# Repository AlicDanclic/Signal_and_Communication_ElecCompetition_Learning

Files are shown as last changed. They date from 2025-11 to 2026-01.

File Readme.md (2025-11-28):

<div align=center><h1>信号电赛备战</h1></div>

### 待完成项目

- [ ] 无线运动传感器节点设计
- [ ] 信号失真度测量装置
- [ ] 无线环境监测模拟装置
- [ ] 微弱信号检测装置
- [ ] 频率补偿电路
- [ ] 调幅信号处理实验电路
- [ ] 无线话筒扩音系统
- [ ] 数字频率计
- [ ] 红外光通信装置
- [ ] 锁定放大器
- [ ] 增益可控射频放大器
- [ ] ∑-Δ 型 ADC 转换电路设计
- [ ] 自适应滤波器
- [ ] 数字-模拟信号混合传输收发机
- [ ] 信号调制方式识别与参数估计装置

### 已有模块

#### 基于TPS7A4701RGWR的低噪声射频LDO

> 包含5V默认输出,3V3默认输出,1V8默认输出,拨码开关可调输出

整个系统通过MP2236进行初步降压,由于MP2236最大输出为6A,考虑1.5倍余量来说,负载端的最大输出应该使用4A左右,正好可以搭配4个TPS7A4701.

### 已有代码

| 代码名/地址 | 完成时间 | 功能介绍 |
| --- | --- | --- |
| | | |
| | | |
| | | |

<div align=center><h3>FPGA知识</h3></div>

<div align=center><h3>信号PCB设计知识</h3></div>

<div align=center><h3>信号处理</h3></div>

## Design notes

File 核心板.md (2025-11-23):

### Component
- FPGA  
XC7A50T-FGG484
- SDRAM  
M12L64322A 8MB SDRAM (512K x 32 Bit x 4 Banks)
- SPI Flash  
MX25L128 16MB
- Ethernet PHY  
1Gb Ethernet PHY Broadcom B50612D x 2

### JTAG
| Pin | Function |
|-----|---|
| J5  | TCK |
| J4  | TMS |
| J3  | TDI |
| J2  | TDO |

### Clock
A 25Mhz clock is connected to FPGA with pin K4

### LED
| LED | FPGA Pin |
|-----|---|
| D2  | A18 |

### SPI-FLASH (U12)
| U12 Pin | FPGA Pin |
|-----|---|
| CS  | T19 |
| MISO| R22 |
| MOSI| P22 |
| SCK | L12 |

### DDR2-SODIMM-200P
| Function | Top-Pin | Bot-Pin | Function |
|---|---|---|---|
| GND | 1 | 2 | 5V |
| GND | 3 | 4 | 5V |
| GND | 5 | 6 | 5V |
| GND | 7 | 8 | 5V |
| GND | 9 | 10 | 5V |
| GND | 11 | 12 | 5V |
| NC | 13 | 14 | NC |
| ETH1_1P| 15 | 16 | ETH2_1P|
| ETH1_1N| 17 | 18 | ETH2_1N|
| NC | 19 | 20 | NC |
| ETH1_2N| 21 | 22 | ETH2_2N|
| ETH1_2P| 23 | 24 | ETH2_2P|
| NC | 25 | 26 | NC |
| ETH1_3P| 27 | 28 | ETH2_3P|
| ETH1_3N| 29 | 30 | ETH2_3N|
| NC | 31 | 32 | NC |
| ETH1_4N| 33 | 34 | ETH2_4N|
| ETH1_4P| 35 | 36 | ETH2_4P|
| NC | 37 | 38 | NC |
| GND | 39 | 40 | GND |
| | | | |
| | | | |
| R2 | 41 | 42 | P5 |
| NC | 43 | 44 | T6 |
| NC | 45 | 46 | U7 |
| NC | 47 | 48 | U6 |
| T3 | 49 | 50 | U5 |
| T4 | 51 | 52 | V5 |
| NC | 53 | 54 | U1 |
| GND | 55 | 56 | GND |
| U2 | 57 | 58 | H3 |
| U3 | 59 | 60 | J1 |
| V2 | 61 | 62 | K1 |
| V3 | 63 | 64 | L1 |
| W1 | 65 | 66 | M1 |
| Y1 | 67 | 68 | J2 |
| AA1 | 69 | 70 | K2 |
| AB1 | 71 | 72 | K3 |
| W2 | 73 | 74 | G3 |
| Y2 | 75 | 76 | J4 |
| AB2 | 77 | 78 | G4 |
| AA3 | 79 | 80 | F4 |
| AB3 | 81 | 82 | L4 |
| Y3 | 83 | 84 | R3 |
| W4 | 85 | 86 | M3 |
| AA4 | 87 | 88 | V4 |
| Y4 | 89 | 90 | R4 |
| AB5 | 91 | 92 | T5 |
| AA5 | 93 | 94 | J5 |
| Y6 | 95 | 96 | J6 |
| AB6 | 97 | 98 | W5 |
| AA6 | 99 | 100  | L5 |
| Y7 | 101  | 102  | L6 |
| AB7 | 103  | 104  | W6 |
| GND | 105  | 106  | GND |
| GND | 107  | 108  | GND |
| AA8 | 109  | 110  | V7 |
| AB8 | 111  | 112  | N13 |
| Y8 | 113  | 114  | N14 |
| W7 | 115  | 116  | P15 |
| Y9 | 117  | 118  | P16 |
| V8 | 119  | 120  | R16 |
| W9 | 121  | 122  | N17 |
| V9 | 123  | 124  | V17 |
| R14 | 125  | 126  | P17 |
| P14 | 127  | 128  | U17 |
| W17 | 129  | 130  | T18 |
| Y18 | 131  | 132  | R17 |
| AA18 | 133  | 134  | U18 |
| W19 | 135  | 136  | R18 |
| AB18 | 137  | 138  | N18 |
| Y19 | 139  | 140  | R19 |
| AA19 | 141  | 142  | N19 |
| V18 | 143  | 144  | N15 |
| V19 | 145  | 146  | M16 |
| AB20 | 147  | 148  | M15 |
| AA20 | 149  | 150  | L15 |
| AA21 | 151  | 152  | L16 |
| AB21 | 153  | 154  | K14 |
| Y21 | 155  | 156  | N22 |
| GND | 157  | 158  | GND |
| NC | 159  | 160  | NC |
| NC | 161  | 162  | NC |
| NC | 163  | 164  | NC |
| NC | 165  | 166  | NC |
| NC | 167  | 168  | NC |
| NC | 169  | 170  | NC |
| NC | 171  | 172  | NC |
| NC | 173  | 174  | NC |
| NC | 175  | 176  | NC |
| NC | 177  | 178  | NC |
| NC | 179  | 180  | NC |
| NC | 181  | 182  | NC |
| NC | 183  | 184  | NC |
| NC | 185  | 186  | NC |
| NC | 187  | 188  | NC |
| NC | 189  | 190  | NC |
| NC | 191  | 192  | NC |
| NC | 193  | 194  | NC |
| NC | 195  | 196  | NC |
| NC | 197  | 198  | NC |
| GND | 199  | 200  | GND |

### SDRAM (U6)
| U6 Pin | FPGA Pin |
|-----|---|
| CLK | E14 |
| CKE | VCC |
| CS  | GND |
| RAS | A14 |
| CAS | D14 |
| WE  | D17 |
| DQM0| GND |
| DQM1| GND |
| DQM2| GND |
| DQM3| GND |
| BA0 | D19 |
| BA1 | B13 |
| A0  | C20 |
| A1  | C19 |
| A2  | C13 |
| A3  | F13 |
| A4  | G13 |
| A5  | G15 |
| A6  | F14 |
| A7  | F18 |
| A8  | E13 |
| A9  | E18 |
| A10 | C14 |
| DQ0 | F21 |
| DQ1 | E22 |
| DQ2 | F20 |
| DQ3 | E21 |
| DQ4 | F19 |
| DQ5 | D22 |
| DQ6 | E19 |
| DQ7 | D21 |
| DQ8 | K21 |
| DQ9 | L21 |
| DQ10| K22 |
| DQ11| M21 |
| DQ12| L20 |
| DQ13| M22 |
| DQ14| N20 |
| DQ15| M20 |
| DQ16| B18 |
| DQ17| D20 |
| DQ18| A19 |
| DQ19| A21 |
| DQ20| A20 |
| DQ21| B21 |
| DQ22| C22 |
| DQ23| B22 |
| DQ24| G21 |
| DQ25| G22 |
| DQ26| H20 |
| DQ27| H22 |
| DQ28| J20 |
| DQ29| J22 |
| DQ30| G20 |
| DQ31| J21 |

### ETH-PHY0 (U5)
| U5 Pin | FPGA Pin |
|---|---|
| MDC | G1 |
| MDIO  | G2 |
| RESET | H2 |
| GTXCLK| A1 |
| TXD[0]| B2 |
| TXD[1]| B1 |
| TXD[2]| C2 |
| TXD[3]| D2 |
| TX_EN | D1 |
| RXC | H2/H4 |
| RXD[0]| E3 |
| RXD[1]| E2 |
| RXD[2]| E1 |
| RXD[3]| F3 |
| RX_DV | F1 |

### ETH-PHY1 (U9)
| U9 Pin | FPGA Pin |
|---|---|
| MDC | G1 |
| MDIO  | G2 |
| RESET | H2 |
| GTXCLK| M6 |
| TXD[0]| M5 |
| TXD[1]| M2 |
| TXD[2]| N4 |
| TXD[3]| P4 |
| TX_EN | N5 |
| RXC | L3/H2 |
| RXD[0]| N2 |
| RXD[1]| N3 |
| RXD[2]| P1 |
| RXD[3]| P2 |
| RX_DV | R1 |

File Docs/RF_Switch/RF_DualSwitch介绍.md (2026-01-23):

<div align="center"><h1>RF_DualSwitch</h1></div>

**SKY13453-385LF**是一款0.01至6.0 GHz单控制SPDT射频开关芯片，专为蜂窝和WLAN系统中的信号路径切换设计。其特点包括采用先进半导体工艺，在2.0 GHz下实现低至0.40 dB的插入损耗和高于25 dB的隔离度。该器件通过单一控制引脚（VCTL）即可实现RFC端口与RF1或RF2之间的高线性切换，并集成在超小尺寸的6引脚QFN（1×1 mm）封装内，满足现代紧凑型射频前端模组的需求。主要应用于手机预功率放大器（PA）模式切换s及双频WLAN（802.11a/b/g/n）等场景。

### 硬件设计

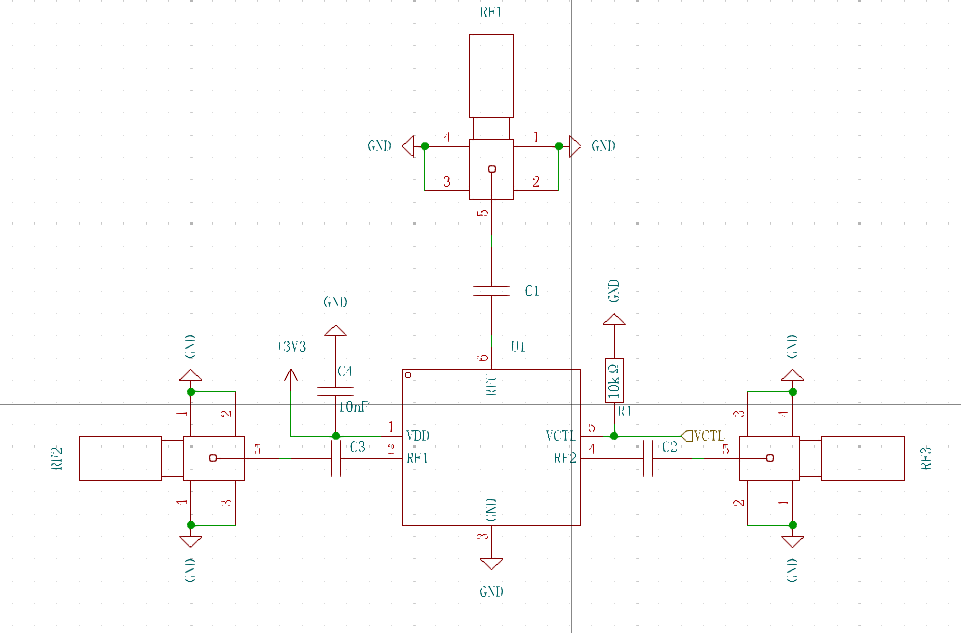
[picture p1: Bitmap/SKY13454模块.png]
RF_DualSwitch模块
 <div align="center">图1 RF_DualSwitch 模块示意图</div>

SKY13453-385LF 的设计重点在于确保射频性能与控制稳定性：**控制端 VCTL** 必须严格遵循逻辑真值表，高电平范围为 +1.8V 至 +3.0V，低电平为 0V 至 +0.45V；**所有射频端口（RFC、RF1、RF2）必须串联 DC 阻隔电容**（建议 10 nF 用于低频应用）；**PCB 布局**应确保射频走线短直、阻抗控制在 50Ω，并**将芯片底部接地焊盘通过多个过孔充分连接至系统地平面**，以优化散热与电气性能；**工作温度范围**为 -40°C 至 +90°C，且在整个生产与操作过程中**必须实施严格的 ESD 防护措施**。建议使用官方评估板进行前期验证，并确保输入功率不超过 +33 dBm。

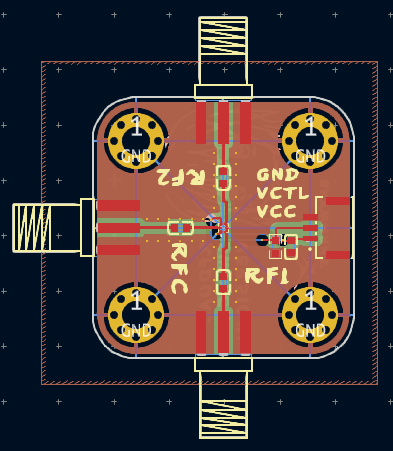
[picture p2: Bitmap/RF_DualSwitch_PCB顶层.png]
RF_DualSwitch_PCB顶层
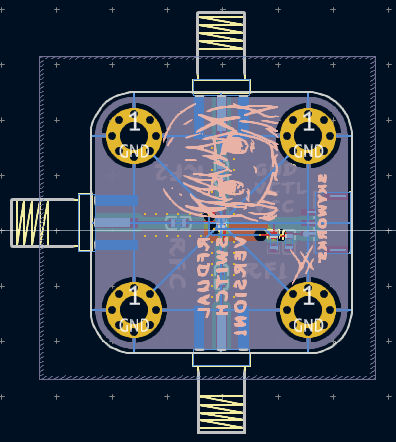
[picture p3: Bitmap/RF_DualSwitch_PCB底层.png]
RF_DualSwitch_PCB底层
 <div align="center">图2 RF_DualSwitch PCB 设计示例</div>

<div style="background-color: #f8f9fa; padding: 30px; text-align: center; margin-top: 20px; border-radius: 8px;">
    <div style="color: #666; margin-bottom: 15px;">PCB尺寸示意图</div>
    <div style="display: inline-block; background-color: #e8f0fe; padding: 90px 60px; border: 2px solid #2c5aa0; border-radius: 4px;">
      <div style="color: #2c5aa0; font-weight: bold; font-size: 24px;">30 × 30 mm</div>
    </div>
    <div style="color: #666; margin-top: 15px;">边长：30 mm</div>
    <div style="color: #888; font-size: 12px; margin-top: 5px;">正方形 PCB</div>
  </div>

  <div style="display: flex; flex-wrap: wrap; gap: 20px; margin-top: 20px;">
    <div style="flex: 1; min-width: 200px;">
      <div style="color: #666; margin-bottom: 5px;">安装孔半径</div>
      <div style="font-size: 18px; font-weight: bold; color: #333;">3mm</div>
    </div>
    <div style="flex: 1; min-width: 200px;">
      <div style="color: #666; margin-bottom: 5px;">安装孔数量</div>
      <div style="font-size: 18px; font-weight: bold; color: #333;">4</div>
    </div>
    <div style="flex: 1; min-width: 200px;">
      <div style="color: #666; margin-bottom: 5px;">板厚</div>
      <div style="font-size: 18px; font-weight: bold; color: #333;">1.6 mm</div>
    </div>
    <div style="flex: 1; min-width: 200px;">
      <div style="color: #666; margin-bottom: 5px;">安装孔位置</div>
      <div style="font-size: 18px; font-weight: bold; color: #333;">四角对称</div>
    </div>
</div>

### 使用注意

- **控制逻辑与电压**：控制引脚 VCTL 必须严格遵循逻辑真值表，高电平为 +1.8V 至 +3.0V，低电平为 0V 至 +0.45V，未定义的逻辑状态会导致开关进入不确定状态
- **射频端口 DC 隔离电容**：所有射频端口（RFC、RF1、RF2）必须串联隔直电容，建议使用 10 nF 电容用于低频应用（＜100 MHz），并应选用 NPO/C0G 材质，尽量靠近芯片引脚布局
- **散热与功率**：射频输入功率绝对不得超过 +33 dBm，芯片底部裸露焊盘必须通过多个过孔大面积连接到 PCB 接地层，以确保散热和电气性能稳定

### 附录: 电容选择建议

| 射频端口 | 频率范围 | 推荐电容值 (C_BL) | 关键设计说明 |
| :--- | :--- | :--- | :--- |
| **所有RF端口** (RFC, RF1, RF2) | **< 100 MHz** (低频应用) | **≥ 10 nF** | **数据手册推荐值**。应选用 **NPO/C0G** 材质多层陶瓷电容（MLCC），以提供充分的DC隔离。 |
| | **≥ 100 MHz** (中高频应用) | **100 pF** | **典型建议值**。为获得更宽频带性能，可根据具体应用调整容值（如47 pF至220 pF）。电容的ESR和自谐振频率需满足应用要求。 |
| **控制电压 VCTL** | **全频率范围** | **10 nF** | **推荐使用**。用于控制引脚的去耦与滤波，确保控制信号稳定，应靠近引脚布局。 |

> **注**：对于高频应用（如 2.4/5.8 GHz WLAN），建议参考官方评估板设计或使用网络分析仪进行实际调测，以优化电容选择。

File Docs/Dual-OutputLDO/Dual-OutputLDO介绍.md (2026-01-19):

<div align="center"><h1>Dual-OutputLDO</h1></div>

LM27762 是一款低噪声正负输出集成式电荷泵与 LDO 芯片，能够从单路输入（2.7V‑5.5V）同时生成可调节的正电压（1.5V‑5V）和负电压（‑1.5V‑‑5V），输出电流可达 ±250mA。其特点包括采用反相电荷泵后接负 LDO 的结构，开关频率为 2MHz，输出噪声极低（典型值 22μVrms），并具有独立的使能控制和电源正常（PGOOD）指示功能。重要参数包括静态电流仅 390μA（典型值）、关断电流 0.5μA，正/负 LDO 在 100mA 负载下的压降分别为 45mV 和 30mV，适用于音频放大器、运放偏置、数据转换器等需要低噪声正负电源的场景。

MP2236 是一款 18V、6A 高效率同步降压转换器，采用恒定导通时间（COT）控制，提供快速瞬态响应和简易的环路补偿。其输入电压范围宽达 3V‑18V，支持最大 6A 连续输出电流，内部集成低导通电阻的功率 MOSFET（25mΩ/12mΩ）。该器件默认参考电压为 600mV，开关频率为 600kHz，并具备打嗝式过流保护（OCP）和热关断功能。重要参数包括轻载时静态电流 150μA（典型值）、关断电流低于 1μA，以及内部软启动时间约 1ms，主要应用于平板电视、数字电视电源、分布式电源系统等中高功率降压转换场合。

### 硬件设计

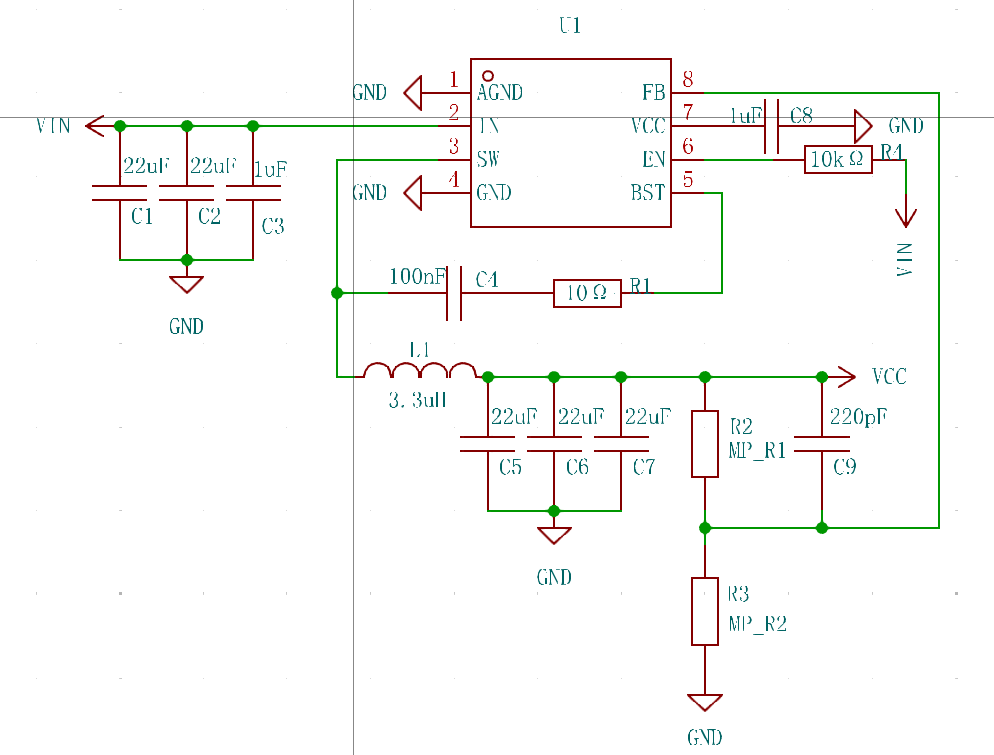
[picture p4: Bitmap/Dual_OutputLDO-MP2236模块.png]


<div align="center">图1 MP2236模块</div>

MP2236是一款同步降压（Step-Down）转换器，其核心任务是将较高的输入电压（如12V）高效、稳定地转换为一个更低的、可精确设定的中间电压（VCC）。这个电压的设定完全由一个连接在输出端与反馈（FB）引脚之间的外部电阻分压网络决定。计算遵循公式 **Vout = 0.6V × (1 + R1/R2)**，其中0.6V是芯片内部的精密基准电压。通过改变R1与R2的阻值比例，即可在0.6V至输入电压的范围内线性调节输出电压。MP2236采用恒定导通时间（COT）控制模式，能根据输入、输出电压实时调整开关频率，在宽输入范围内保持效率与快速瞬态响应。其输出的VCC电压的精度和稳定性，直接决定了后续电路供电平台的质量。

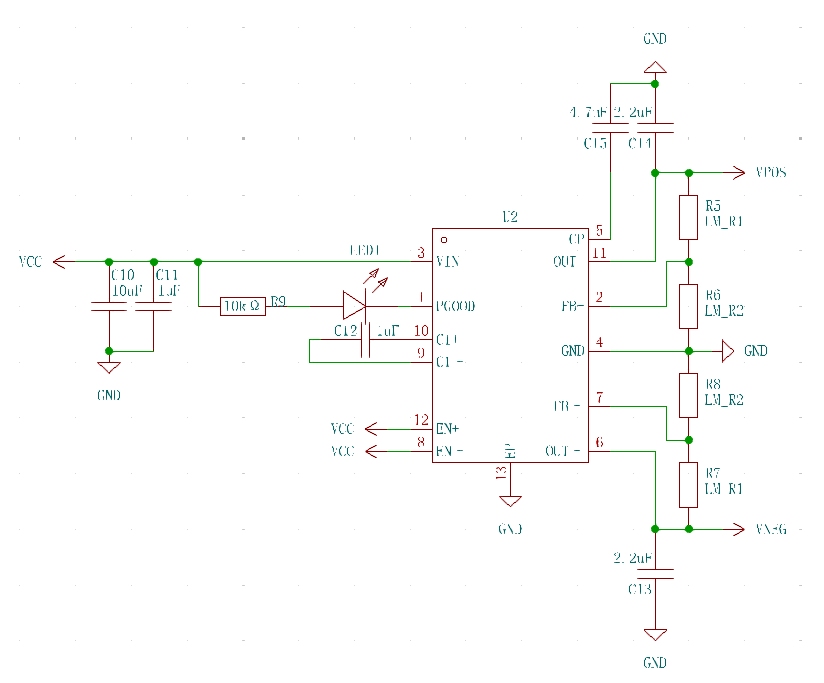
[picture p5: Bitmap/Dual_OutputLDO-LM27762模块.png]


<div align="center">图2 LM27762模块</div>

LM27762则是一个集成了电荷泵和低压差线性稳压器（LDO）的独特芯片，它能从一个单路正输入（即MP2236提供的VCC）同时产生一组相互独立、低噪声的正负输出电压（如+3.3V和-3.3V）。其每路输出都拥有独立的反馈控制环路：正输出由基准电压1.2V和电阻R1、R2设定（公式：**Vout+ = 1.2V × (R1+R2)/R2**），负输出则由基准电压-1.22V和电阻R3、R4设定（公式：**Vout- = -1.22V × (R3+R4)/R4**）。一个关键的设计约束是，为了保障LDO环路的稳定，连接到地的反馈电阻R2和R4必须不小于50kΩ。这种设计允许工程师灵活配置不对称的双电源（如+5V/-3V），但为了获得最佳性能，正负输出的电阻需分别计算以确保精度。

<div style="display: flex; justify-content: space-between; margin: 20px 0;">
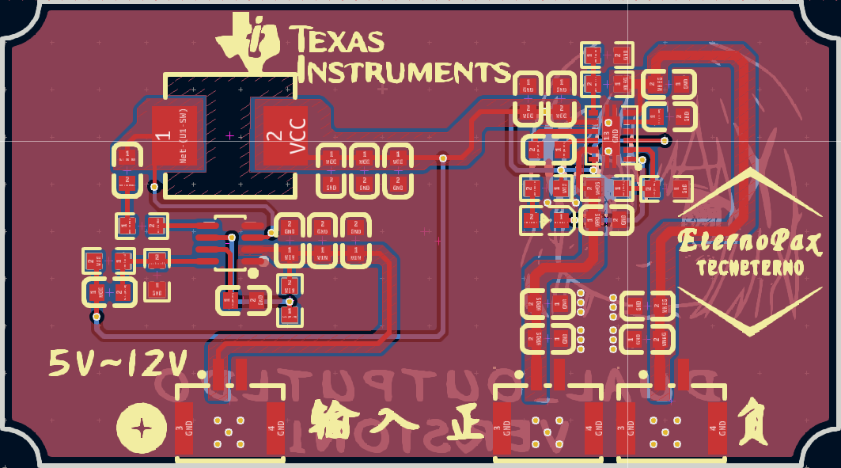
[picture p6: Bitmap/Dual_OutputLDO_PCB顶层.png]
QuietLDO_PCB顶层
  
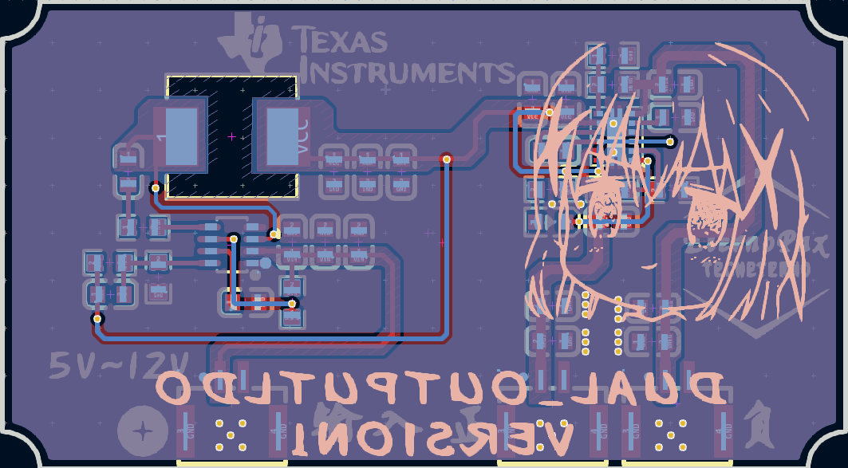
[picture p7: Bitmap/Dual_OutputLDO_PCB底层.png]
QuietLDO_PCBd底层
  
</div>
<div align="center">图3 Dual-OutputLDO PCB设计</div>

<div style="background-color:#f8f9fa;padding:40px;text-align:center;margin-top:30px;border-radius:10px;"><div style="color:#666;margin-bottom:20px;font-size:18px;">PCB尺寸示意图</div><div style="position:relative;display:inline-block;padding:80px 120px;"><div style="width:300px;height:180px;background-color:#e8f0fe;border:3px solid #2c5aa0;clip-path:path('M15,0L285,0L300,15L300,165L285,180L15,180L0,165L0,15L15,0Z M0,15A15,15 0 0 0 15,0L0,15Z M300,15L285,0A15,15 0 0 0 300,15Z M285,180L300,165A15,15 0 0 0 285,180Z M0,165L15,180A15,15 0 0 0 0,165Z')"><div style="color:#2c5aa0;font-weight:bold;font-size:32px;position:absolute;top:50%;left:50%;transform:translate(5%,100%);">25 × 45 mm</div></div></div><div style="color:#666;margin-top:20px;font-size:16px;">长×宽 (单位: mm)，四角2mm半径内凹缺角</div></div>

  <div style="display: flex; flex-wrap: wrap; gap: 20px; margin-top: 20px;">
    <div style="flex: 1; min-width: 200px;">
      <div style="color: #666; margin-bottom: 5px;">安装孔半径</div>
      <div style="font-size: 18px; font-weight: bold; color: #333;">2 mm</div>
    </div>
    <div style="flex: 1; min-width: 200px;">
      <div style="color: #666; margin-bottom: 5px;">安装孔数量</div>
      <div style="font-size: 18px; font-weight: bold; color: #333;">4个</div>
    </div>
    <div style="flex: 1; min-width: 200px;">
      <div style="color: #666; margin-bottom: 5px;">板厚</div>
      <div style="font-size: 18px; font-weight: bold; color: #333;">1.6 mm</div>
    </div>
    <div style="flex: 1; min-width: 200px;">
      <div style="color: #666; margin-bottom: 5px;">安装孔位置</div>
      <div style="font-size: 18px; font-weight: bold; color: #333;">四角对称</div>
    </div>
</div>

### 使用注意

- 在焊接过程中需注意反馈电阻的选择,原理图上为标注电阻大小的作为反馈电阻,具体取值参考附录
- 在使用前尽可能先估算电压电流大小,该电路板不适合通过大电流
- 用户需要采用4个铜柱+螺母将PCB固定
- 由于可以同时输出正负电压,所以在使用过程中注意散热

### 附录:建议匹配电阻

| 目标输出 (LM27762) | 推荐VCC (MP2236) | MP2236 电阻配置 (产生VCC) | LM27762 正输出电阻配置 | LM27762 负输出电阻配置 | 计算实际电压 |
| :--- | :--- | :--- | :--- | :--- | :--- |
| **±3.3V** | **4.0V** | **R1**: 267kΩ </br>**R2**: 47.5kΩ | **R1**: 174kΩ </br>**R2**: 100kΩ  | **R3**: 169kΩ </br>**R4**: 100kΩ  | VCC≈3.99V </br>VOUT+≈3.30V </br>VOUT-≈-3.29V |
| **±1.8V** | **2.5V** | **R1**: 158kΩ </br>**R2**: 49.9kΩ | **R1**: 51.1kΩ </br>**R2**: 100kΩ | **R3**: 47.5kΩ </br>**R4**: 100kΩ | VCC≈2.50V </br>VOUT+≈1.81V </br>VOUT-≈-1.80V |
| **±2.5V** | **3.3V** | **R1**: 287kΩ </br>**R2**: 63.4kΩ | **R1**: 127kΩ </br>**R2**: 100kΩ  | **R3**: 124kΩ </br>**R4**: 100kΩ  | VCC≈3.30V </br>VOUT+≈2.51V </br>VOUT-≈-2.50V |

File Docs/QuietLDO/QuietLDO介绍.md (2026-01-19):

<div align="center"><h1>QuietLDO</h1></div>

**MP2236** 是一款由 MPS 生产的高效率同步降压转换器，其输入电压范围为 3V 至 18V，并能提供高达 6A 的连续输出电流。它采用恒定导通时间控制模式，具有快速的瞬态响应能力，开关频率为 600kHz，且集成了低导通电阻的功率 MOSFET，使其在宽负载范围内都能保持高效。该芯片内置了打嗝模式的过流保护、热关断和欠压锁定等全面保护功能，外围元件精简，采用紧凑的 TSOT23-8 封装，非常适用于平板显示器、数字电视电源和分布式电源系统等需要高电流密度和高效能的应用场景。

**TPS7A47** 系列是德州仪器推出的一款高压、超低噪声的 LDO 线性稳压器，包括 TPS7A4700 和 TPS7A4701 两个型号。它的输入电压范围宽达 3V 至 36V，输出电流为 1A，其最突出的特点是极低的输出噪声（仅 4µVrms）和极高的电源抑制比，能为核心模拟电路提供极其洁净的电压轨。TPS7A4700 可通过独特的 ANY-OUT 引脚编程方式设置输出电压（1.4V 至 20.5V），无需外部电阻；TPS7A4701 还支持通过外部电阻在更宽范围（至 34V）内调节。该器件采用带散热焊盘的 VQFN 封装，是射频电路、高精度 ADC/DAC、测试测量以及医疗音频等噪声敏感型应用的理想选择。

### 硬件设计

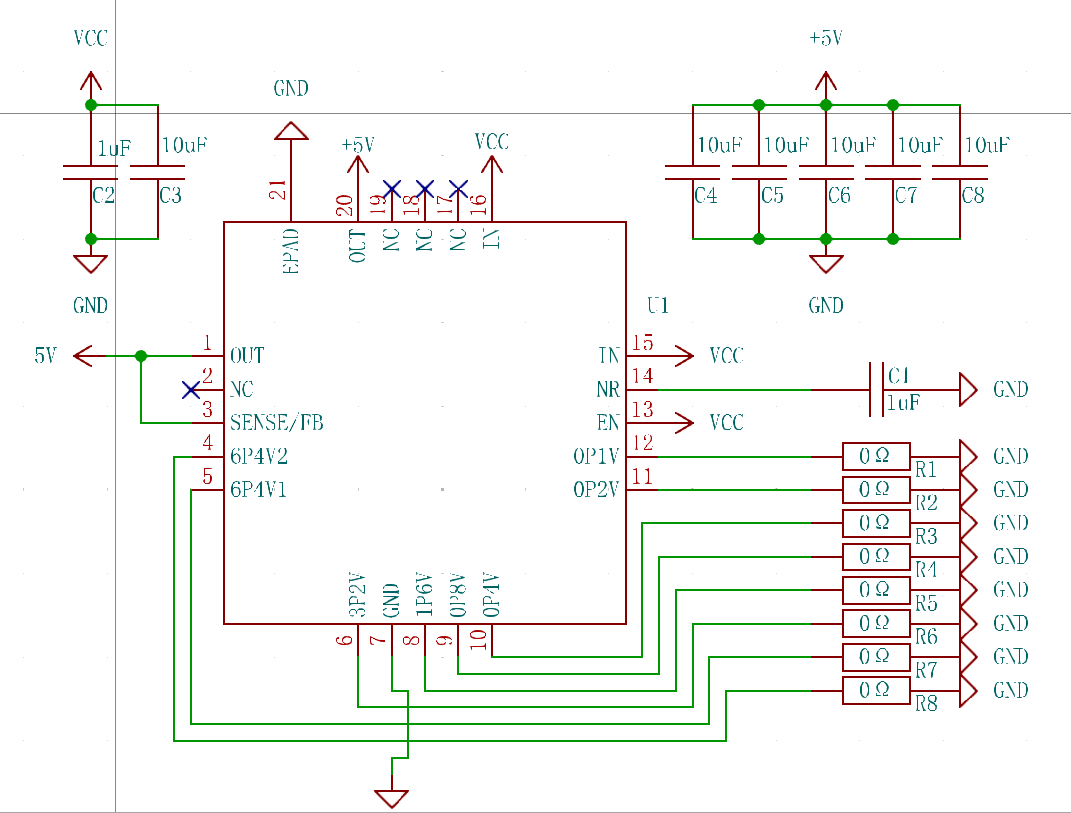
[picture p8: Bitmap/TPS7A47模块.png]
TPS7A47模块


<div align="center">图1 TPS7A47模块</div>

这一个基本的TPS7A47模块,在实际使用时,需要考虑右侧八个电阻的有无.在其配置中他有1.4V到20.5V的输出,步长为0.1V,计算公式如下:V_
$$
V_{out} = 1.4V + a_0V_{0.1} + a_1 V_{0.2}+ a_2 V_{0.4}+ a_3 V_{0.8}+ a_4 V_{1.6}+ a_5 V_{3.2}+ a_6 V_{6.4}+ a_7 V_{6.4}
$$
但实际上我们在实际需求时只需要6V以下的电压,过大的电压在实际中并不适合LDO,超过7V的输入在实际使用中会使得该电路发热多大,于是我们采用MP2236作为前级DCDC降压.

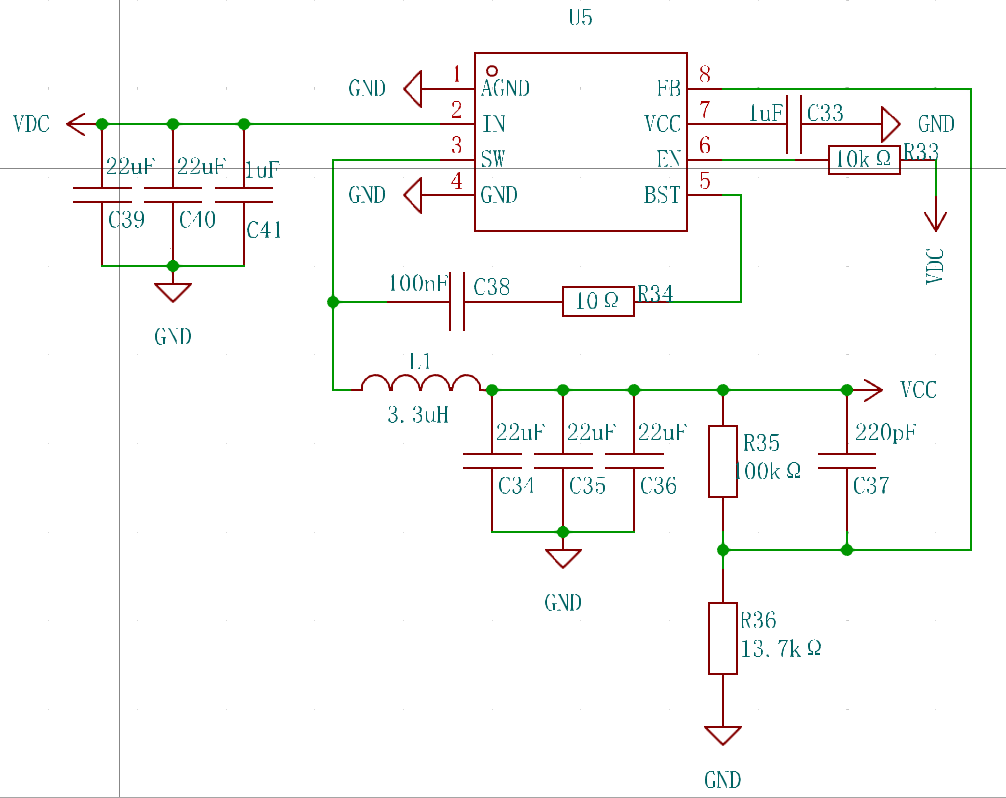
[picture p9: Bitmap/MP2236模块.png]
MP2236模块


<div align="center">图2 MP2236模块</div>

在PCB设计主要注意MP2236的大电流布局和TPS7A47的电源布局.通过PCB ToolKit,我们可以计算出以下几个数据:

| 导线宽度(mils) | 最大电流(A) |
| :---: | :---: |
| 10 | 1.2927 |
| 40 | 3.2097 |
| 60 | 4.1041 |
| 120 | 6.1992 |

可以发现在实际中我们过6A的上限电流是实现不了的,当我们可以使用40mils+铺铜的布线方式增大电流的上限.

<div style="display: flex; justify-content: space-between; margin: 20px 0;">
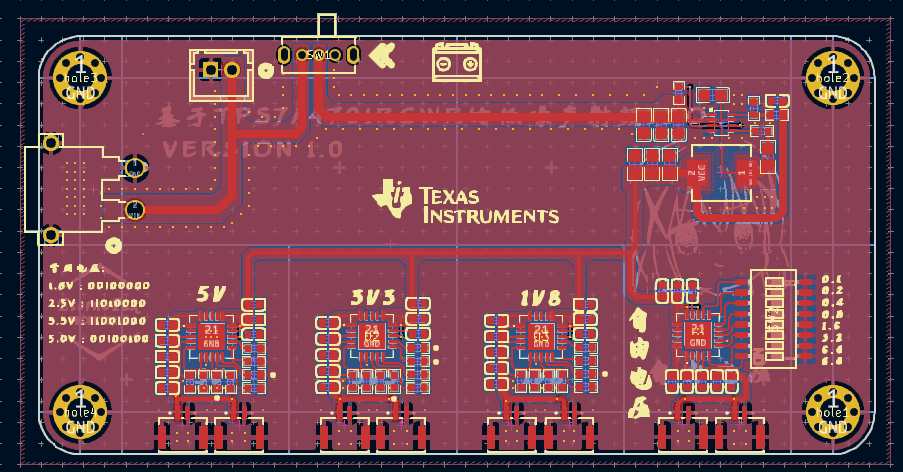
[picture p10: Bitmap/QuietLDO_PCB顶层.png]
QuietLDO_PCB顶层
  
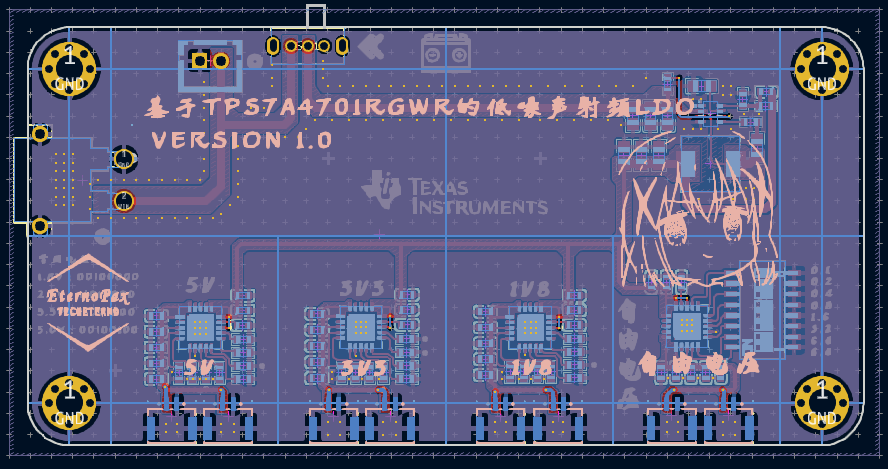
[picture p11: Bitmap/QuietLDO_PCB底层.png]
QuietLDO_PCBd底层
  
</div>

<div align="center">图3 QuietPCB设计</div>

<div style="background-color: #f8f9fa; padding: 30px; text-align: center; margin-top: 20px; border-radius: 8px;">
    <div style="color: #666; margin-bottom: 15px;">PCB尺寸示意图</div>
    <div style="display: inline-block; background-color: #e8f0fe; padding: 40px 60px; border: 2px solid #2c5aa0; border-radius: 4px;">
      <div style="color: #2c5aa0; font-weight: bold; font-size: 24px;">100 × 50 mm</div>
    </div>
    <div style="color: #666; margin-top: 15px;">长×宽 (单位: mm)</div>
  </div>

  <div style="display: flex; flex-wrap: wrap; gap: 20px; margin-top: 20px;">
    <div style="flex: 1; min-width: 200px;">
      <div style="color: #666; margin-bottom: 5px;">安装孔直径</div>
      <div style="font-size: 18px; font-weight: bold; color: #333;">3.2 mm</div>
    </div>
    <div style="flex: 1; min-width: 200px;">
      <div style="color: #666; margin-bottom: 5px;">安装孔数量</div>
      <div style="font-size: 18px; font-weight: bold; color: #333;">无</div>
    </div>
    <div style="flex: 1; min-width: 200px;">
      <div style="color: #666; margin-bottom: 5px;">板厚</div>
      <div style="font-size: 18px; font-weight: bold; color: #333;">1.6 mm</div>
    </div>
    <div style="flex: 1; min-width: 200px;">
      <div style="color: #666; margin-bottom: 5px;">安装孔位置</div>
      <div style="font-size: 18px; font-weight: bold; color: #333;">四角对称</div>
    </div>
  </div>
### 使用注意

- 在焊接过程中需注意5V,3V3和1V8的电阻焊接问题,可以阅读原理图,对于NC的电阻不进行焊接,也可以参考PCB,标有圆圈的电阻需要焊接
- 在使用前请尽可能先估计电压大小和电流电小,输出端建议每路(4个GH1.25)不超过1A,输出总电流不超过4A,输入电压尽可能控制在7.4V-12V
- 用户需采用4个M3的铜柱踮起,尽可能避免该PCB处于射频信号的附近或不必要接触

### 附录:可调端所有可能输出

| 组合编号 | OP1V | OP2V | OP4V | OP8V | 1P6V | 3P2V | 6P4V1 | 6P4V2 | 输出电压(V) | 二进制 |
| --- | ---- | ---- | ---- | ---- | ---- | ---- | ----- | ----- | --- | --- |
| 0 | 0V | 0V | 0V | 0V | 0V | 0V | 0V | 0V | 1.4 | 00000000 |
| 1 | 0.1V | 0V | 0V | 0V | 0V | 0V | 0V | 0V | 1.5 | 00000001 |
| 2 | 0V | 0.2V | 0V | 0V | 0V | 0V | 0V | 0V | 1.6 | 00000010 |
| 3 | 0.1V | 0.2V | 0V | 0V | 0V | 0V | 0V | 0V | 1.7 | 00000011 |
| 4 | 0V | 0V | 0.4V | 0V | 0V | 0V | 0V | 0V | 1.8 | 00000100 |
| 5 | 0.1V | 0V | 0.4V | 0V | 0V | 0V | 0V | 0V | 1.9 | 00000101 |
| 6 | 0V | 0.2V | 0.4V | 0V | 0V | 0V | 0V | 0V | 2.0 | 00000110 |
| 7 | 0.1V | 0.2V | 0.4V | 0V | 0V | 0V | 0V | 0V | 2.1 | 00000111 |
| 8 | 0V | 0V | 0V | 0.8V | 0V | 0V | 0V | 0V | 2.2 | 00001000 |
| 9 | 0.1V | 0V | 0V | 0.8V | 0V | 0V | 0V | 0V | 2.3 | 00001001 |
| 10 | 0V | 0.2V | 0V | 0.8V | 0V | 0V | 0V | 0V | 2.4 | 00001010 |
| 11 | 0.1V | 0.2V | 0V | 0.8V | 0V | 0V | 0V | 0V | 2.5 | 00001011 |
| 12 | 0V | 0V | 0.4V | 0.8V | 0V | 0V | 0V | 0V | 2.6 | 00001100 |
| 13 | 0.1V | 0V | 0.4V | 0.8V | 0V | 0V | 0V | 0V | 2.7 | 00001101 |
| 14 | 0V | 0.2V | 0.4V | 0.8V | 0V | 0V | 0V | 0V | 2.8 | 00001110 |
| 15 | 0.1V | 0.2V | 0.4V | 0.8V | 0V | 0V | 0V | 0V | 2.9 | 00001111 |
| 16 | 0V | 0V | 0V | 0V | 1.6V | 0V | 0V | 0V | 3.0 | 00010000 |
| 17 | 0.1V | 0V | 0V | 0V | 1.6V | 0V | 0V | 0V | 3.1 | 00010001 |
| 18 | 0V | 0.2V | 0V | 0V | 1.6V | 0V | 0V | 0V | 3.2 | 00010010 |
| 19 | 0.1V | 0.2V | 0V | 0V | 1.6V | 0V | 0V | 0V | 3.3 | 00010011 |
| 20 | 0V | 0V | 0.4V | 0V | 1.6V | 0V | 0V | 0V | 3.4 | 00010100 |
| 21 | 0.1V | 0V | 0.4V | 0V | 1.6V | 0V | 0V | 0V | 3.5 | 00010101 |
| 22 | 0V | 0.2V | 0.4V | 0V | 1.6V | 0V | 0V | 0V | 3.6 | 00010110 |
| 23 | 0.1V | 0.2V | 0.4V | 0V | 1.6V | 0V | 0V | 0V | 3.7 | 00010111 |
| 24 | 0V | 0V | 0V | 0.8V | 1.6V | 0V | 0V | 0V | 3.8 | 00011000 |
| 25 | 0.1V | 0V | 0V | 0.8V | 1.6V | 0V | 0V | 0V | 3.9 | 00011001 |
| 26 | 0V | 0.2V | 0V | 0.8V | 1.6V | 0V | 0V | 0V | 4.0 | 00011010 |
| 27 | 0.1V | 0.2V | 0V | 0.8V | 1.6V | 0V | 0V | 0V | 4.1 | 00011011 |
| 28 | 0V | 0V | 0.4V | 0.8V | 1.6V | 0V | 0V | 0V | 4.2 | 00011100 |
| 29 | 0.1V | 0V | 0.4V | 0.8V | 1.6V | 0V | 0V | 0V | 4.3 | 00011101 |
| 30 | 0V | 0.2V | 0.4V | 0.8V | 1.6V | 0V | 0V | 0V | 4.4 | 00011110 |
| 31 | 0.1V | 0.2V | 0.4V | 0.8V | 1.6V | 0V | 0V | 0V | 4.5 | 00011111 |
| 32 | 0V | 0V | 0V | 0V | 0V | 3.2V | 0V | 0V | 4.6 | 00100000 |
| 33 | 0.1V | 0V | 0V | 0V | 0V | 3.2V | 0V | 0V | 4.7 | 00100001 |
| 34 | 0V | 0.2V | 0V | 0V | 0V | 3.2V | 0V | 0V | 4.8 | 00100010 |
| 35 | 0.1V | 0.2V | 0V | 0V | 0V | 3.2V | 0V | 0V | 4.9 | 00100011 |
| 36 | 0V | 0V | 0.4V | 0V | 0V | 3.2V | 0V | 0V | 5.0 | 00100100 |
| 37 | 0.1V | 0V | 0.4V | 0V | 0V | 3.2V | 0V | 0V | 5.1 | 00100101 |
| 38 | 0V | 0.2V | 0.4V | 0V | 0V | 3.2V | 0V | 0V | 5.2 | 00100110 |
| 39 | 0.1V | 0.2V | 0.4V | 0V | 0V | 3.2V | 0V | 0V | 5.3 | 00100111 |
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

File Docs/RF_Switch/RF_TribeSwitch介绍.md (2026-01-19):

<div align="center"><h1>RF_TribeSwitch</h1></div>

**SKY13317-373LF**是一款20 MHz至6.0 GHz基于pHEMT工艺的GaAs SP3T天线开关，适用于高频宽带的无线通信系统。其采用正电压控制逻辑（0/1.8-5.0V），在2.5 GHz和6 GHz频点分别实现0.5 dB和0.9 dB的低插入损耗，并保持高达25 dB的通道隔离。芯片集成了高线性度设计（P1dB达+29 dBm），并采用微型8引脚MLP（1.5×1.5 mm）封装，是WLAN（802.11a/b/g/n）及蓝牙天线切换的理想选择。

### 硬件设计

<div align="center">
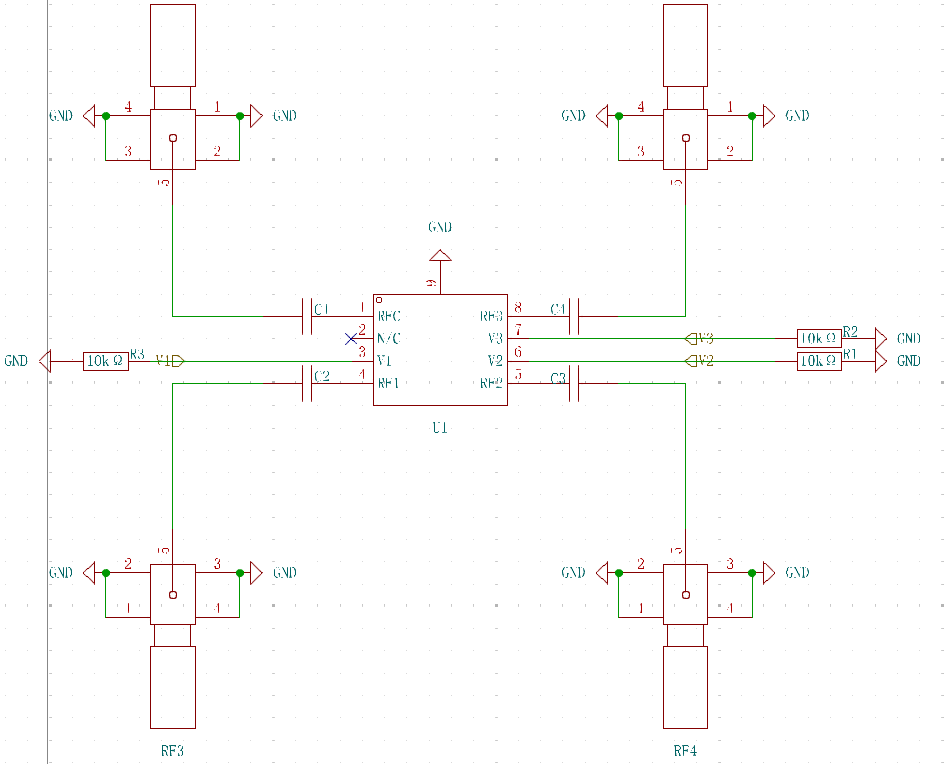
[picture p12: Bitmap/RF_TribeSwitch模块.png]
  
</div>
<div align="center">图2 Dual-OutputLDO PCB设计</div>

SKY13317-373LF的设计要求核心在于确保其射频性能与可靠性：**控制端**需严格遵循真值表逻辑，提供1.8-5.0V（高电平）与0-0.25V（低电平）的电压；**所有RF端口（RF1/RF2/RF3/RFC）必须串联DC阻隔电容**（根据频段选择47pF至10nF）；**PCB布局**须保证射频走线短直、阻抗匹配为50Ω，并**将芯片底部裸露焊盘充分接地**以优化散热与电气性能；**工作环境**需控制在-40°C至+100°C之间，且在整个生产与操作过程中**必须实施严格的ESD防护措施**。建议使用官方评估板进行前期验证，并确保输入功率不超过+30dBm。

<div style="display: flex; justify-content: space-between; margin: 20px 0;">
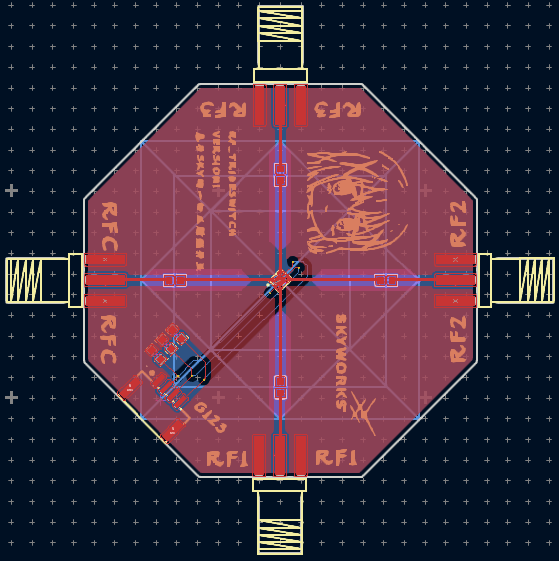
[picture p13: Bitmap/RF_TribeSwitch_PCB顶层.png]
QuietLDO_PCB顶层
  
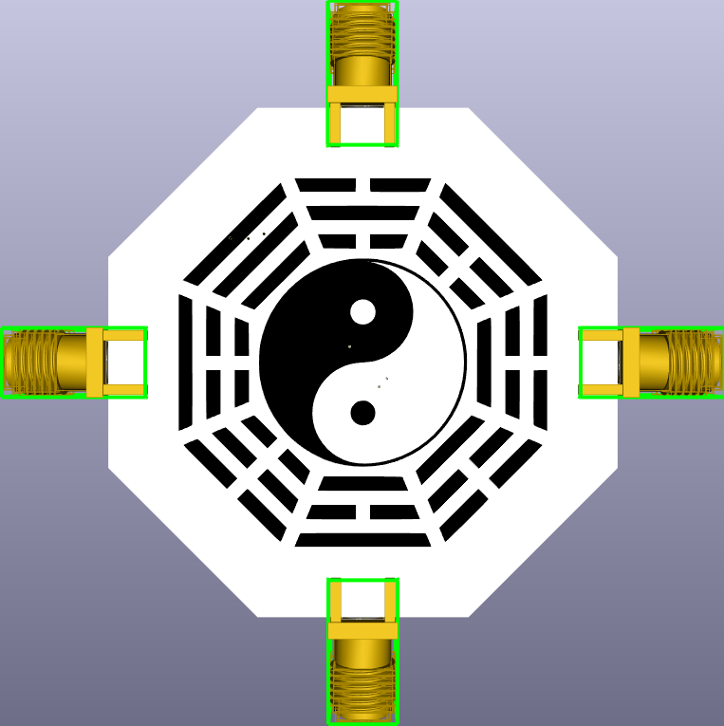
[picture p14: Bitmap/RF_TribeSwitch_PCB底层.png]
QuietLDO_PCBd底层
  
</div>
<div align="center">图2 Dual-OutputLDO PCB设计</div>

<div style="background-color: #f8f9fa; padding: 30px; text-align: center; margin-top: 20px; border-radius: 8px;">
    <div style="color: #666; margin-bottom: 15px;">正八边形尺寸示意图</div>
    <div style="display: inline-block; position: relative; width: 180px; height: 180px; margin: 0 auto;">
        <svg width="180" height="180" viewBox="0 0 180 180">
            <!-- 正八边形 -->
            <polygon points="90,20 130,40 150,80 130,120 90,140 50,120 30,80 50,40" 
                     style="fill: #e8f0fe; stroke: #2c5aa0; stroke-width: 3;"/>
            <!-- 边长标注 -->
            <line x1="90" y1="20" x2="130" y2="40" 
                  style="stroke: #666; stroke-width: 1; stroke-dasharray: 5,5;"/>
            <text x="110" y="15" text-anchor="middle" style="font-size: 12px; fill: #333;">20 mm</text>
            <!-- 中心点 -->
            <circle cx="90" cy="80" r="4" fill="#2c5aa0"/>
            <text x="90" y="75" text-anchor="middle" style="font-size: 10px; fill: #2c5aa0;">中心</text>
        </svg>
    </div>
    <div style="color: #666; margin-top: 15px;">边长：20 mm</div>
    <div style="color: #888; font-size: 12px; margin-top: 5px;">边数：8 | 内角：135° | 外角：45°</div>
</div>

  <div style="display: flex; flex-wrap: wrap; gap: 20px; margin-top: 20px;">
    <div style="flex: 1; min-width: 200px;">
      <div style="color: #666; margin-bottom: 5px;">安装孔半径</div>
      <div style="font-size: 18px; font-weight: bold; color: #333;">无</div>
    </div>
    <div style="flex: 1; min-width: 200px;">
      <div style="color: #666; margin-bottom: 5px;">安装孔数量</div>
      <div style="font-size: 18px; font-weight: bold; color: #333;">无</div>
    </div>
    <div style="flex: 1; min-width: 200px;">
      <div style="color: #666; margin-bottom: 5px;">板厚</div>
      <div style="font-size: 18px; font-weight: bold; color: #333;">1.6 mm</div>
    </div>
    <div style="flex: 1; min-width: 200px;">
      <div style="color: #666; margin-bottom: 5px;">安装孔位置</div>
      <div style="font-size: 18px; font-weight: bold; color: #333;">无</div>
    </div>
</div>

### 使用注意

- **控制逻辑与电压**：控制引脚 V1、V2、V3 必须严格遵循真值表逻辑，高电平为 +1.8V 至 +5.0V，低电平为 0V 至 +0.25V（建议为 0V），任何未定义的逻辑组合都会使开关进入不可预测的状态
- **射频端口 DC 隔离电容**：所有射频端口（RFC、RF1、RF2、RF3）必须串联隔直电容，电容值根据工作频率选择：＞500MHz 时建议 47pF，50MHz‑500MHz 建议 220pF，＜50MHz 建议 ≥10nF，并应选用 NPO/C0G 材质，且尽量靠近引脚布局
- **散热与功率**：射频输入功率绝对不得超过 +30dBm（1W），芯片底部裸露焊盘必须通过多个过孔大面积连接到 PCB 接地层，以确保散热和电气性能稳定

### 附录:建议匹配电容

| 射频端口 | 频率范围 | 推荐电容值 (C_BL) | 关键设计说明 |
| :--- | :--- | :--- | :--- |
| **所有RF端口** (RF1, RF2, RF3, RFC) | **> 500 MHz** (例如：2.4/5.8 GHz WLAN) | **47 pF** | **首选值**。应选用高频性能优异的 **NPO/C0G** 材质多层陶瓷电容（MLCC），以最小化插入损耗。 |
| | **50 MHz 至 500 MHz** | **220 pF** | 用于中频段，确保良好的射频导通与DC隔离。 |
| | **< 50 MHz** (低频应用) | **≥ 10 nF** | 为获得更低的截止频率，建议使用更大容值（如10 nF）。电容的ESR和自谐振频率需满足应用要求。 |

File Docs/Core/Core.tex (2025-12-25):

\documentclass[12pt]{article}
\usepackage{xeCJK}
\usepackage{geometry}
\usepackage{booktabs}
\usepackage{longtable}
\usepackage{array}
\usepackage{multirow}
\usepackage{xcolor}
\usepackage{colortbl}
\usepackage{makecell}
\usepackage{caption}
\usepackage{afterpage}
\usepackage{threeparttable}
\usepackage{tabu}
\usepackage{rotating}

% 设置中文字体
\setCJKmainfont{SimSun}
\setCJKsansfont{SimHei}
\setCJKmonofont{SimSun}

% 页面设置
\geometry{a4paper, left=1.5cm, right=1.5cm, top=2cm, bottom=2cm}

% 表格样式定义
\newcolumntype{L}[1]{>{\raggedright\arraybackslash}p{#1}}
\newcolumntype{C}[1]{>{\centering\arraybackslash}p{#1}}
\newcolumntype{R}[1]{>{\raggedleft\arraybackslash}p{#1}}
% 表格列格式定义
\newcolumntype{P}[1]{>{\centering\arraybackslash}p{#1}}

% 颜色定义
\definecolor{tableheader}{RGB}{41,128,185}
\definecolor{rowcolor1}{RGB}{250,250,250}
\definecolor{rowcolor2}{RGB}{240,248,255}
\definecolor{rowcolor3}{RGB}{245,245,245}
\definecolor{highlight}{RGB}{255,255,204}

% 表格颜色定义
\definecolor{headcolor}{RGB}{52,152,219}
\definecolor{GNDcolor}{RGB}{220,237,247}
\definecolor{ETHcolor}{RGB}{230,247,238}
\definecolor{NCcolor}{RGB}{250,250,250}

% 表格设置
\captionsetup[table]{
    font=small,
    labelfont=bf,
    labelsep=period,
    justification=centering,
    skip=6pt
}
\renewcommand{\arraystretch}{1.1}
\setlength{\tabcolsep}{4pt}
\setlength{\belowcaptionskip}{8pt}

% 自定义表格命令
\newcommand{\tabhead}[1]{\cellcolor{tableheader}\textcolor{white}{\bfseries #1}}
\newcommand{\specialcell}[2][c]{\begin{tabular}[#1]{@{}c@{}}#2\end{tabular}}
\newcommand{\important}[1]{\cellcolor{highlight}#1}

\begin{document}

\title{\textbf{FPGA 开发板完整引脚连接技术文档}}
\author{}
\date{}
\maketitle

\begin{center}
    \color{tableheader}\rule{\textwidth}{1.5pt}
    \vspace{5pt}
    \textcolor{tableheader}{\small 完整引脚连接表 - 保留所有原始内容}
\end{center}

\section*{1. 系统主要组件}
\begin{table}[h]
    \centering
    \footnotesize
    \begin{tabular}{|L{4cm}|L{10cm}|}
    \hline
    \rowcolor{tableheader}
    \textcolor{white}{\bfseries 组件名称} & \textcolor{white}{\bfseries 规格描述} \\
    \hline
    FPGA芯片 & Xilinx Artix-7 XC7A50T-FGG484 (484引脚) \\
    \hline
    SDRAM存储器 & M12L64322A, 8MB容量 (512K × 32位 × 4 Bank) \\
    \hline
    SPI Flash存储器 & MX25L128, 16MB容量 \\
    \hline
    以太网PHY芯片 & Broadcom B50612D 1Gb以太网PHY × 2个 \\
    \hline
    \end{tabular}
\end{table}

\section*{2. JTAG调试接口引脚连接}
\begin{table}[h]
    \centering
    \footnotesize
    \begin{tabular}{|C{2cm}|C{2cm}|C{8cm}|}
    \hline
    \rowcolor{tableheader}
    \textcolor{white}{\bfseries 引脚编号} & \textcolor{white}{\bfseries 功能} & \textcolor{white}{\bfseries 功能描述} \\
    \hline
    J5 & TCK & 测试时钟输入 \\
    \hline
    J4 & TMS & 测试模式选择 \\
    \hline
    J3 & TDI & 测试数据输入 \\
    \hline
    J2 & TDO & 测试数据输出 \\
    \hline
    \end{tabular}
\end{table}

\section*{3. 系统时钟源}
\begin{table}[h]
    \centering
    \footnotesize
    \begin{tabular}{|C{4cm}|C{3cm}|C{7cm}|}
    \hline
    \rowcolor{tableheader}
    \textcolor{white}{\bfseries 时钟类型} & \textcolor{white}{\bfseries FPGA引脚} & \textcolor{white}{\bfseries 规格说明} \\
    \hline
    主系统时钟 & K4 & 25MHz有源晶振，作为系统主时钟源 \\
    \hline
    \end{tabular}
\end{table}

\section*{4. LED状态指示灯}
\begin{table}[h]
    \centering
    \footnotesize
    \begin{tabular}{|C{2cm}|C{2cm}|C{9cm}|}
    \hline
    \rowcolor{tableheader}
    \textcolor{white}{\bfseries LED编号} & \textcolor{white}{\bfseries FPGA引脚} & \textcolor{white}{\bfseries 功能说明} \\
    \hline
    D2 & A18 & 用户可编程状态指示灯 \\
    \hline
    \end{tabular}
\end{table}

\section*{5. SPI Flash存储器 (U12) 引脚连接}
\begin{table}[h]
    \centering
    \footnotesize
    \begin{tabular}{|C{2cm}|C{2.5cm}|C{2.5cm}|C{6cm}|}
    \hline
    \rowcolor{tableheader}
    \multicolumn{2}{|c|}{\textcolor{white}{\bfseries SPI Flash引脚}} & \textcolor{white}{\bfseries FPGA引脚} & \textcolor{white}{\bfseries 功能描述} \\
    \hline
    引脚名称 & 功能 & 引脚编号 & 说明 \\
    \hline
    CS & 片选信号 & T19 & 低电平有效，选择SPI Flash \\
    \hline
    MISO & 主入从出 & R22 & 数据输入线，Flash输出数据到FPGA \\
    \hline
    MOSI & 主出从入 & P22 & 数据输出线，FPGA输出数据到Flash \\
    \hline
    SCK & 时钟信号 & L12 & 串行时钟，由FPGA提供 \\
    \hline
    \end{tabular}
\end{table}

\begin{longtable}{P{2.5cm}P{1.5cm}P{1.5cm}P{2.5cm}}
\caption{DDR2 SODIMM 引脚连接表} \\
\toprule
\rowcolor{headcolor}
\textcolor{white}{\textbf{功能}} & \textcolor{white}{\textbf{顶排引脚}} & \textcolor{white}{\textbf{底排引脚}} & \textcolor{white}{\textbf{功能}} \\
\midrule
\endfirsthead

\multicolumn{4}{c}{{\bfseries 续表：DDR2 SODIMM 引脚连接表}} \\
\toprule
\rowcolor{headcolor}
\textcolor{white}{\textbf{功能}} & \textcolor{white}{\textbf{顶排引脚}} & \textcolor{white}{\textbf{底排引脚}} & \textcolor{white}{\textbf{功能}} \\
\midrule
\endhead

\bottomrule
\endfoot

\rowcolor{GNDcolor} GND    & 1  & 2  & 5V \\
\rowcolor{GNDcolor} GND    & 3  & 4  & 5V \\
\rowcolor{GNDcolor} GND    & 5  & 6  & 5V \\
\rowcolor{GNDcolor} GND    & 7  & 8  & 5V \\
\rowcolor{GNDcolor} GND    & 9  & 10 & 5V \\
\rowcolor{GNDcolor} GND    & 11 & 12 & 5V \\
\rowcolor{NCcolor} NC     & 13 & 14 & NC \\
\rowcolor{ETHcolor} ETH1\_1P & 15 & 16 & ETH2\_1P \\
\rowcolor{ETHcolor} ETH1\_1N & 17 & 18 & ETH2\_1N \\
\rowcolor{NCcolor} NC     & 19 & 20 & NC \\
\rowcolor{ETHcolor} ETH1\_2N & 21 & 22 & ETH2\_2N \\
\rowcolor{ETHcolor} ETH1\_2P & 23 & 24 & ETH2\_2P \\
\rowcolor{NCcolor} NC     & 25 & 26 & NC \\
\rowcolor{ETHcolor} ETH1\_3P & 27 & 28 & ETH2\_3P \\
\rowcolor{ETHcolor} ETH1\_3N & 29 & 30 & ETH2\_3N \\
\rowcolor{NCcolor} NC     & 31 & 32 & NC \\
\rowcolor{ETHcolor} ETH1\_4N & 33 & 34 & ETH2\_4N \\
\rowcolor{ETHcolor} ETH1\_4P & 35 & 36 & ETH2\_4P \\
\rowcolor{NCcolor} NC     & 37 & 38 & NC \\
\rowcolor{GNDcolor} GND    & 39 & 40 & GND \\
\rowcolor{rowcolor2} R2     & 41 & 42 & P5 \\
\rowcolor{NCcolor} NC     & 43 & 44 & T6 \\
\rowcolor{NCcolor} NC     & 45 & 46 & U7 \\
\rowcolor{NCcolor} NC     & 47 & 48 & U6 \\
\rowcolor{rowcolor2} T3     & 49 & 50 & U5 \\
\rowcolor{rowcolor2} T4     & 51 & 52 & V5 \\
\rowcolor{NCcolor} NC     & 53 & 54 & U1 \\
\rowcolor{GNDcolor} GND    & 55 & 56 & GND \\
\rowcolor{rowcolor2} U2     & 57 & 58 & H3 \\
\rowcolor{rowcolor2} U3     & 59 & 60 & J1 \\
\rowcolor{rowcolor2} V2     & 61 & 62 & K1 \\
\rowcolor{rowcolor2} V3     & 63 & 64 & L1 \\
\rowcolor{rowcolor2} W1     & 65 & 66 & M1 \\
\rowcolor{rowcolor2} Y1     & 67 & 68 & J2 \\
\rowcolor{rowcolor2} AA1    & 69 & 70 & K2 \\
\rowcolor{rowcolor2} AB1    & 71 & 72 & K3 \\
\rowcolor{rowcolor2} W2     & 73 & 74 & G3 \\
\rowcolor{rowcolor2} Y2     & 75 & 76 & J4 \\
\rowcolor{rowcolor2} AB2    & 77 & 78 & G4 \\
\rowcolor{rowcolor2} AA3    & 79 & 80 & F4 \\
\rowcolor{rowcolor2} AB3    & 81 & 82 & L4 \\
\rowcolor{rowcolor2} Y3     & 83 & 84 & R3 \\
\rowcolor{rowcolor2} W4     & 85 & 86 & M3 \\
\rowcolor{rowcolor2} AA4    & 87 & 88 & V4 \\
\rowcolor{rowcolor2} Y4     & 89 & 90 & R4 \\
\rowcolor{rowcolor2} AB5    & 91 & 92 & T5 \\
\rowcolor{rowcolor2} AA5    & 93 & 94 & J5 \\
\rowcolor{rowcolor2} Y6     & 95 & 96 & J6 \\
\rowcolor{rowcolor2} AB6    & 97 & 98 & W5 \\
\rowcolor{rowcolor2} AA6    & 99 & 100 & L5 \\
\rowcolor{rowcolor2} Y7     & 101 & 102 & L6 \\
\rowcolor{rowcolor2} AB7    & 103 & 104 & W6 \\
\rowcolor{GNDcolor} GND    & 105 & 106 & GND \\
\rowcolor{GNDcolor} GND    & 107 & 108 & GND \\
\rowcolor{rowcolor2} AA8    & 109 & 110 & V7 \\
\rowcolor{rowcolor2} AB8    & 111 & 112 & N13 \\
\rowcolor{rowcolor2} Y8     & 113 & 114 & N14 \\
\rowcolor{rowcolor2} W7     & 115 & 116 & P15 \\
\rowcolor{rowcolor2} Y9     & 117 & 118 & P16 \\
\rowcolor{rowcolor2} V8     & 119 & 120 & R16 \\
\rowcolor{rowcolor2} W9     & 121 & 122 & N17 \\
\rowcolor{rowcolor2} V9     & 123 & 124 & V17 \\
\rowcolor{rowcolor2} R14    & 125 & 126 & P17 \\
\rowcolor{rowcolor2} P14    & 127 & 128 & U17 \\
\rowcolor{rowcolor2} W17    & 129 & 130 & T18 \\
\rowcolor{rowcolor2} Y18    & 131 & 132 & R17 \\
\rowcolor{rowcolor2} AA18   & 133 & 134 & U18 \\
\rowcolor{rowcolor2} W19    & 135 & 136 & R18 \\
\rowcolor{rowcolor2} AB18   & 137 & 138 & N18 \\
\rowcolor{rowcolor2} Y19    & 139 & 140 & R19 \\
\rowcolor{rowcolor2} AA19   & 141 & 142 & N19 \\
\rowcolor{rowcolor2} V18    & 143 & 144 & N15 \\
\rowcolor{rowcolor2} V19    & 145 & 146 & M16 \\
\rowcolor{rowcolor2} AB20   & 147 & 148 & M15 \\
\rowcolor{rowcolor2} AA20   & 149 & 150 & L15 \\
\rowcolor{rowcolor2} AA21   & 151 & 152 & L16 \\
\rowcolor{rowcolor2} AB21   & 153 & 154 & K14 \\
\rowcolor{rowcolor2} Y21    & 155 & 156 & N22 \\
\rowcolor{GNDcolor} GND    & 157 & 158 & GND \\
\rowcolor{NCcolor} NC     & 159 & 160 & NC \\
\rowcolor{NCcolor} NC     & 161 & 162 & NC \\
\rowcolor{NCcolor} NC     & 163 & 164 & NC \\
\rowcolor{NCcolor} NC     & 165 & 166 & NC \\
\rowcolor{NCcolor} NC     & 167 & 168 & NC \\
\rowcolor{NCcolor} NC     & 169 & 170 & NC \\
\rowcolor{NCcolor} NC     & 171 & 172 & NC \\
\rowcolor{NCcolor} NC     & 173 & 174 & NC \\
\rowcolor{NCcolor} NC     & 175 & 176 & NC \\
\rowcolor{NCcolor} NC     & 177 & 178 & NC \\
\rowcolor{NCcolor} NC     & 179 & 180 & NC \\
\rowcolor{NCcolor} NC     & 181 & 182 & NC \\
\rowcolor{NCcolor} NC     & 183 & 184 & NC \\
\rowcolor{NCcolor} NC     & 185 & 186 & NC \\
\rowcolor{NCcolor} NC     & 187 & 188 & NC \\
\rowcolor{NCcolor} NC     & 189 & 190 & NC \\
\rowcolor{NCcolor} NC     & 191 & 192 & NC \\
\rowcolor{NCcolor} NC     & 193 & 194 & NC \\
\rowcolor{NCcolor} NC     & 195 & 196 & NC \\
\rowcolor{NCcolor} NC     & 197 & 198 & NC \\
\rowcolor{GNDcolor} GND    & 199 & 200 & GND \\
\bottomrule
\end{longtable}

\section*{7. SDRAM (U6) 完整引脚连接表}
\afterpage{\clearpage}
\begin{longtable}{|C{2cm}|C{3cm}|C{3cm}|}
\caption{SDRAM (U6) 完整引脚连接表}\\
\hline
\rowcolor{tableheader}
\textcolor{white}{\bfseries SDRAM引脚} & \textcolor{white}{\bfseries FPGA引脚/连接} & \textcolor{white}{\bfseries 功能说明} \\
\hline
\endfirsthead

\multicolumn{3}{c}{{\bfseries 续表: SDRAM (U6) 完整引脚连接表}} \\
\hline
\rowcolor{tableheader}
\textcolor{white}{\bfseries SDRAM引脚} & \textcolor{white}{\bfseries FPGA引脚/连接} & \textcolor{white}{\bfseries 功能说明} \\
\hline
\endhead

\hline
\endfoot

CLK & E14 & 时钟输入引脚 \\
\hline
CKE & VCC & 时钟使能，接电源 \\
\hline
CS & GND & 片选，接地 \\
\hline
RAS & A14 & 行地址选通 \\
\hline
CAS & D14 & 列地址选通 \\
\hline
WE & D17 & 写使能 \\
\hline
DQM0 & GND & 数据掩码0，接地 \\
\hline
DQM1 & GND & 数据掩码1，接地 \\
\hline
DQM2 & GND & 数据掩码2，接地 \\
\hline
DQM3 & GND & 数据掩码3，接地 \\
\hline
BA0 & D19 & Bank地址0 \\
\hline
BA1 & B13 & Bank地址1 \\
\hline
A0 & C20 & 地址线0 \\
\hline
A1 & C19 & 地址线1 \\
\hline
A2 & C13 & 地址线2 \\
\hline
A3 & F13 & 地址线3 \\
\hline
A4 & G13 & 地址线4 \\
\hline
A5 & G15 & 地址线5 \\
\hline
A6 & F14 & 地址线6 \\
\hline
A7 & F18 & 地址线7 \\
\hline
A8 & E13 & 地址线8 \\
\hline
A9 & E18 & 地址线9 \\
\hline
A10 & C14 & 地址线10 \\
\hline
DQ0 & F21 & 数据线0 \\
\hline
DQ1 & E22 & 数据线1 \\
\hline
DQ2 & F20 & 数据线2 \\
\hline
DQ3 & E21 & 数据线3 \\
\hline
DQ4 & F19 & 数据线4 \\
\hline
DQ5 & D22 & 数据线5 \\
\hline
DQ6 & E19 & 数据线6 \\
\hline
DQ7 & D21 & 数据线7 \\
\hline
DQ8 & K21 & 数据线8 \\
\hline
DQ9 & L21 & 数据线9 \\
\hline
DQ10 & K22 & 数据线10 \\
\hline
DQ11 & M21 & 数据线11 \\
\hline
DQ12 & L20 & 数据线12 \\
\hline
DQ13 & M22 & 数据线13 \\
\hline
DQ14 & N20 & 数据线14 \\
\hline
DQ15 & M20 & 数据线15 \\
\hline
DQ16 & B18 & 数据线16 \\
\hline
DQ17 & D20 & 数据线17 \\
\hline
DQ18 & A19 & 数据线18 \\
\hline
DQ19 & A21 & 数据线19 \\
\hline
DQ20 & A20 & 数据线20 \\
\hline
DQ21 & B21 & 数据线21 \\
\hline
DQ22 & C22 & 数据线22 \\
\hline
DQ23 & B22 & 数据线23 \\
\hline
DQ24 & G21 & 数据线24 \\
\hline
DQ25 & G22 & 数据线25 \\
\hline
DQ26 & H20 & 数据线26 \\
\hline
DQ27 & H22 & 数据线27 \\
\hline
DQ28 & J20 & 数据线28 \\
\hline
DQ29 & J22 & 数据线29 \\
\hline
DQ30 & G20 & 数据线30 \\
\hline
DQ31 & J21 & 数据线31 \\
\hline
\end{longtable}

\section*{8. 以太网 PHY 0 (U5) 完整引脚连接表}
\afterpage{\clearpage}
\begin{longtable}{|C{2.5cm}|C{3cm}|C{3cm}|C{5cm}|}
\caption{以太网 PHY 0 (U5) 完整引脚连接表}\\
\hline
\rowcolor{tableheader}
\textcolor{white}{\bfseries U5引脚} & \textcolor{white}{\bfseries 功能名称} & \textcolor{white}{\bfseries FPGA引脚} & \textcolor{white}{\bfseries 详细描述} \\
\hline
\endfirsthead

\multicolumn{4}{c}{{\bfseries 续表: 以太网 PHY 0 (U5) 完整引脚连接表}} \\
\hline
\rowcolor{tableheader}
\textcolor{white}{\bfseries U5引脚} & \textcolor{white}{\bfseries 功能名称} & \textcolor{white}{\bfseries FPGA引脚} & \textcolor{white}{\bfseries 详细描述} \\
\hline
\endhead

\hline
\endfoot

MDC & 管理数据时钟 & G1 & MDIO接口时钟信号 \\
\hline
MDIO & 管理数据输入输出 & G2 & MDIO接口双向数据线 \\
\hline
RESET & 复位信号 & H2 & PHY复位控制信号 \\
\hline
GTXCLK & 发送时钟 & A1 & 千兆发送时钟 \\
\hline
TXD[0] & 发送数据0 & B2 & 发送数据位0 \\
\hline
TXD[1] & 发送数据1 & B1 & 发送数据位1 \\
\hline
TXD[2] & 发送数据2 & C2 & 发送数据位2 \\
\hline
TXD[3] & 发送数据3 & D2 & 发送数据位3 \\
\hline
TX\_EN & 发送使能 & D1 & 发送使能控制信号 \\
\hline
RXC & 接收时钟 & H2/H4 & 接收时钟（双引脚连接） \\
\hline
RXD[0] & 接收数据0 & E3 & 接收数据位0 \\
\hline
RXD[1] & 接收数据1 & E2 & 接收数据位1 \\
\hline
RXD[2] & 接收数据2 & E1 & 接收数据位2 \\
\hline
RXD[3] & 接收数据3 & F3 & 接收数据位3 \\
\hline
RX\_DV & 接收数据有效 & F1 & 接收数据有效指示信号 \\
\hline
\end{longtable}

\section*{9. 以太网 PHY 1 (U9) 完整引脚连接表}
\begin{longtable}{|C{2.5cm}|C{3cm}|C{3cm}|C{5cm}|}
\caption{以太网 PHY 1 (U9) 完整引脚连接表}\\
\hline
\rowcolor{tableheader}
\textcolor{white}{\bfseries U9引脚} & \textcolor{white}{\bfseries 功能名称} & \textcolor{white}{\bfseries FPGA引脚} & \textcolor{white}{\bfseries 详细描述} \\
\hline
\endfirsthead

\multicolumn{4}{c}{{\bfseries 续表: 以太网 PHY 1 (U9) 完整引脚连接表}} \\
\hline
\rowcolor{tableheader}
\textcolor{white}{\bfseries U9引脚} & \textcolor{white}{\bfseries 功能名称} & \textcolor{white}{\bfseries FPGA引脚} & \textcolor{white}{\bfseries 详细描述} \\
\hline
\endhead

\hline
\endfoot

MDC & 管理数据时钟 & G1 & MDIO接口时钟信号 \\
\hline
MDIO & 管理数据输入输出 & G2 & MDIO接口双向数据线 \\
\hline
RESET & 复位信号 & H2 & PHY复位控制信号 \\
\hline
GTXCLK & 发送时钟 & M6 & 千兆发送时钟 \\
\hline
TXD[0] & 发送数据0 & M5 & 发送数据位0 \\
\hline
TXD[1] & 发送数据1 & M2 & 发送数据位1 \\
\hline
TXD[2] & 发送数据2 & N4 & 发送数据位2 \\
\hline
TXD[3] & 发送数据3 & P4 & 发送数据位3 \\
\hline
TX\_EN & 发送使能 & N5 & 发送使能控制信号 \\
\hline
RXC & 接收时钟 & L3/H2 & 接收时钟（双引脚连接） \\
\hline
RXD[0] & 接收数据0 & N2 & 接收数据位0 \\
\hline
RXD[1] & 接收数据1 & N3 & 接收数据位1 \\
\hline
RXD[2] & 接收数据2 & P1 & 接收数据位2 \\
\hline
RXD[3] & 接收数据3 & P2 & 接收数据位3 \\
\hline
RX\_DV & 接收数据有效 & R1 & 接收数据有效指示信号 \\
\hline
\end{longtable}

\vspace{1cm}
\begin{center}
    \color{tableheader}\rule{\textwidth}{0.8pt}
    
    \vspace{5pt}
    \textbf{文档完整性声明} \\
    \small
    本技术文档完整包含了所有原始引脚连接信息，无任何内容删减。\\
    包含：200个DDR2 SODIMM引脚、32个SDRAM数据线、11个SDRAM地址线、\\
    所有以太网PHY信号以及其他所有系统连接。\\
    总记录引脚数：350+个引脚连接关系 \\
    版本：1.0 | 生成日期：\today \\
    文档状态：完整准确
\end{center}

\end{document}

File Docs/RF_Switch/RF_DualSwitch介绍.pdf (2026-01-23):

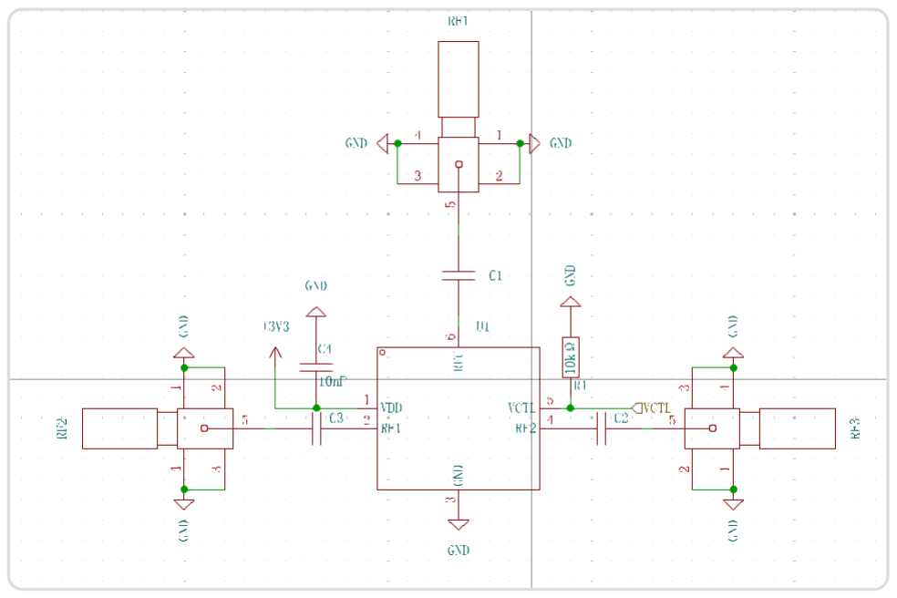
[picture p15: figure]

图1 RF_DualSwitch 模块示意图

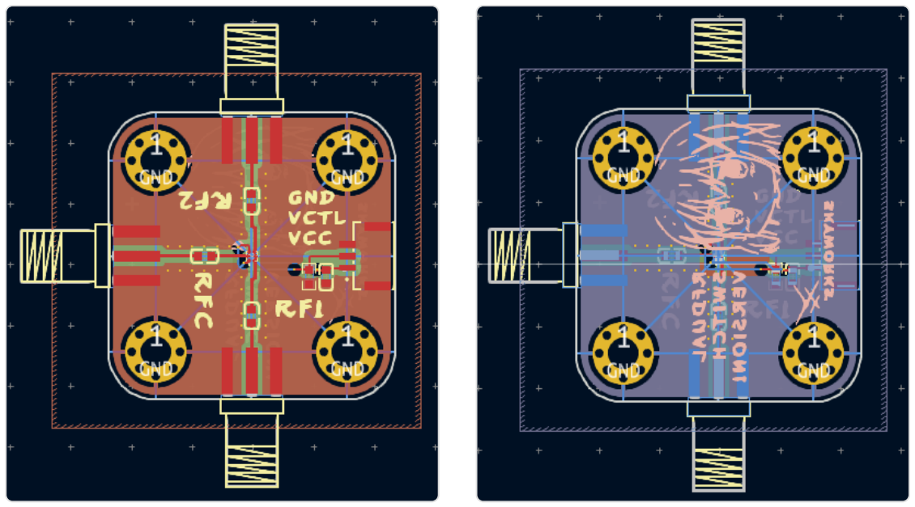
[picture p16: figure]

图2 RF_DualSwitch PCB 设计示例

# RF_DualSwitch

SKY13453-385LF是一款0.01至6.0 GHz单控制SPDT射频开关芯片，专为蜂窝和WLAN系统中的信号路径 切换设计。其特点包括采用先进半导体工艺，在2.0 GHz下实现低至0.40 dB的插入损耗和高于25 dB的隔 离度。该器件通过单一控制引脚（VCTL）即可实现RFC端口与RF1或RF2之间的高线性切换，并集成在超 小尺寸的6引脚QFN（1×1 mm）封装内，满足现代紧凑型射频前端模组的需求。主要应用于手机预功率 放大器（PA）模式切换s及双频WLAN（802.11a/b/g/n）等场景。

## 硬件设计

SKY13453-385LF 的设计重点在于确保射频性能与控制稳定性：控制端 VCTL 必须严格遵循逻辑真值 表，高电平范围为 +1.8V 至 +3.0V，低电平为 0V 至 +0.45V；所有射频端口（RFC、RF1、RF2）必须串 联 DC 阻隔电容（建议 10 nF 用于低频应用）；PCB 布局应确保射频走线短直、阻抗控制在 50Ω，并将 芯片底部接地焊盘通过多个过孔充分连接至系统地平面，以优化散热与电气性能；工作温度范围为 -40°C 至 +90°C，且在整个生产与操作过程中必须实施严格的 ESD 防护措施。建议使用官方评估板进行前期验 证，并确保输入功率不超过 +33 dBm。

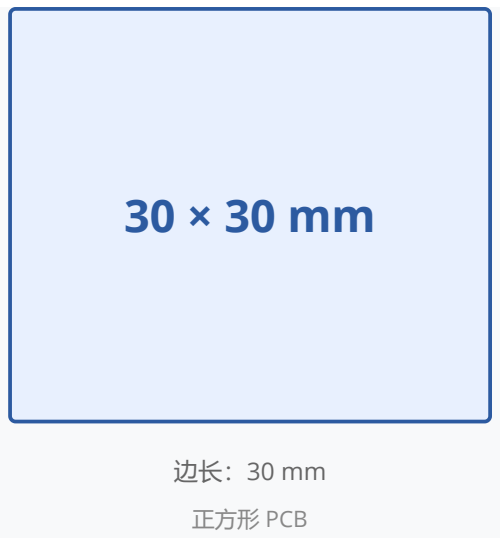
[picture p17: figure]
正方形 PCB

安装孔半径
3mm

安装孔数量
4

板厚

## 1.6 mm

安装孔位置

## 四角对称

射频端口 | 频率范围 | 推荐电容 值 (C_BL) | 关键设计说明
所有RF端口 (RFC, RF1, RF2) | < 100 MHz (低频应用) | ≥ 10 nF | 数据手册推荐值。应选用 NPO/C0G 材质多层陶瓷 电容（MLCC），以提供充分的DC隔离。
| ≥ 100 MHz (中高频应 用) | 100 pF | 典型建议值。为获得更宽频带性能，可根据具体应 用调整容值（如47 pF至220 pF）。电容的ESR和 自谐振频率需满足应用要求。
控制电压 VCTL | 全频率范围 | 10 nF | 推荐使用。用于控制引脚的去耦与滤波，确保控制 信号稳定，应靠近引脚布局。

## 使用注意

控制逻辑与电压：控制引脚 VCTL 必须严格遵循逻辑真值表，高电平为 +1.8V 至 +3.0V，低电平为 0V 至 +0.45V，未定义的逻辑状态会导致开关进入不确定状态
射频端口 DC 隔离电容：所有射频端口（RFC、RF1、RF2）必须串联隔直电容，建议使用 10 nF 电 容用于低频应用（＜100 MHz），并应选用 NPO/C0G 材质，尽量靠近芯片引脚布局 散热与功率：射频输入功率绝对不得超过 +33 dBm，芯片底部裸露焊盘必须通过多个过孔大面积连 接到 PCB 接地层，以确保散热和电气性能稳定

## 附录: 电容选择建议

注：对于高频应用（如 2.4/5.8 GHz WLAN），建议参考官方评估板设计或使用网络分析仪进行实 际调测，以优化电容选择。

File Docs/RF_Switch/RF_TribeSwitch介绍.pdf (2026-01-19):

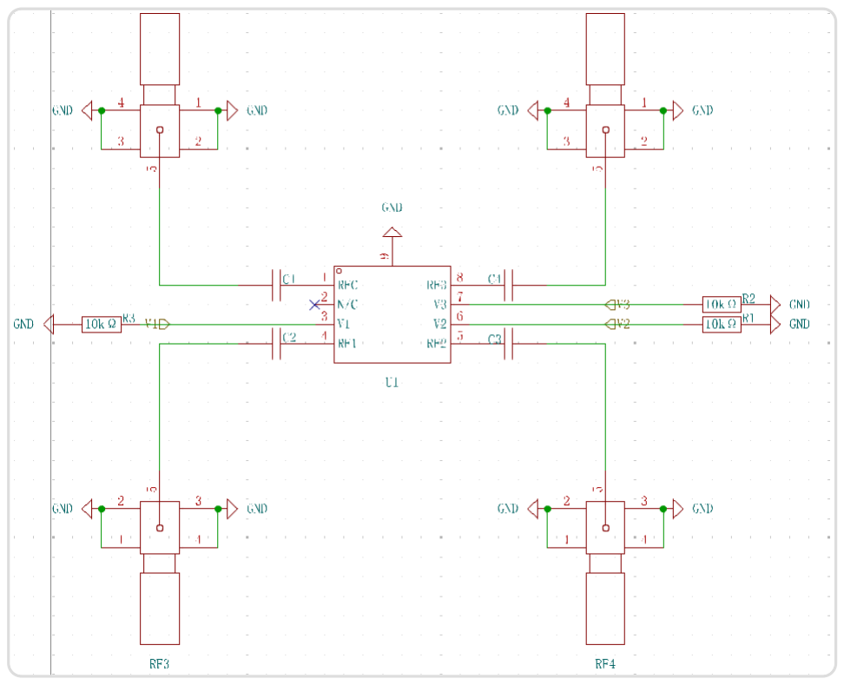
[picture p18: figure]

图2 Dual-OutputLDO PCB设计

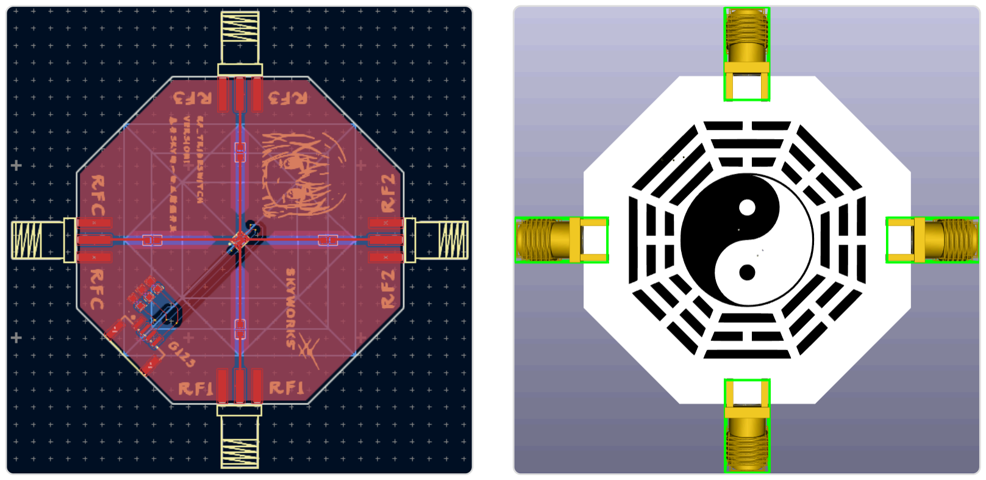
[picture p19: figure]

图2 Dual-OutputLDO PCB设计

# RF_TribeSwitch

SKY13317-373LF是一款20 MHz至6.0 GHz基于pHEMT工艺的GaAs SP3T天线开关，适用于高频宽带的 无线通信系统。其采用正电压控制逻辑（0/1.8-5.0V），在2.5 GHz和6 GHz频点分别实现0.5 dB和0.9 dB的低插入损耗，并保持高达25 dB的通道隔离。芯片集成了高线性度设计（P1dB达+29 dBm），并采 用微型8引脚MLP（1.5×1.5 mm）封装，是WLAN（802.11a/b/g/n）及蓝牙天线切换的理想选择。

## 硬件设计

SKY13317-373LF的设计要求核心在于确保其射频性能与可靠性：控制端需严格遵循真值表逻辑，提供 1.8-5.0V（高电平）与0-0.25V（低电平）的电压；所有RF端口（RF1/RF2/RF3/RFC）必须串联DC阻隔 电容（根据频段选择47pF至10nF）；PCB布局须保证射频走线短直、阻抗匹配为50Ω，并将芯片底部裸 露焊盘充分接地以优化散热与电气性能；工作环境需控制在-40°C至+100°C之间，且在整个生产与操作 过程中必须实施严格的ESD防护措施。建议使用官方评估板进行前期验证，并确保输入功率不超过 +30dBm。

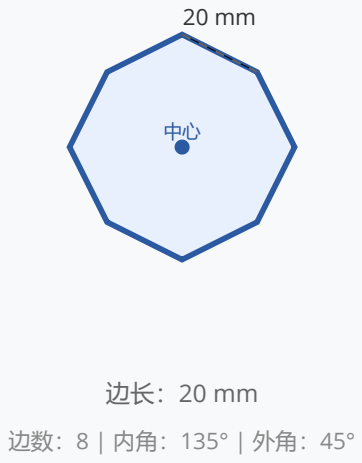
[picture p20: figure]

安装孔半径
无

安装孔数量
无

板厚

## 1.6 mm

安装孔位置
无
射频端口 | 频率范围 | 推荐电容 值 (C_BL) | 关键设计说明
所有RF端口 (RF1, RF2, RF3, RFC) | > 500 MHz (例 如：2.4/5.8 GHz WLAN) | 47 pF | 首选值。应选用高频性能优异的 NPO/C0G 材质多层陶瓷电容（MLCC）， 以最小化插入损耗。
| 50 MHz 至 500 MHz | 220 pF | 用于中频段，确保良好的射频导通与DC隔 离。
| < 50 MHz (低频 应用) | ≥ 10 nF | 为获得更低的截止频率，建议使用更大容 值（如10 nF）。电容的ESR和自谐振频率 需满足应用要求。

## 使用注意

控制逻辑与电压：控制引脚 V1、V2、V3 必须严格遵循真值表逻辑，高电平为 +1.8V 至 +5.0V，低 电平为 0V 至 +0.25V（建议为 0V），任何未定义的逻辑组合都会使开关进入不可预测的状态 射频端口 DC 隔离电容：所有射频端口（RFC、RF1、RF2、RF3）必须串联隔直电容，电容值根据 工作频率选择：＞500MHz 时建议 47pF，50MHz‑500MHz 建议 220pF，＜50MHz 建议 ≥10nF， 并应选用 NPO/C0G 材质，且尽量靠近引脚布局
散热与功率：射频输入功率绝对不得超过 +30dBm（1W），芯片底部裸露焊盘必须通过多个过孔 大面积连接到 PCB 接地层，以确保散热和电气性能稳定

## 附录:建议匹配电容

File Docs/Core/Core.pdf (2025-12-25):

# FPGA 开发板完整引脚连接技术文档

完整引脚连接表 - 保留所有原始内容

## 1. 系统主要组件

组件名称 | 规格描述
FPGA 芯片 | Xilinx Artix-7 XC7A50T-FGG484 (484 引脚)
SDRAM 存储器 | M12L64322A, 8MB 容量 (512K × 32 位 × 4 Bank)
SPI Flash 存储器 | MX25L128, 16MB 容量
以太网 PHY 芯片 | Broadcom B50612D 1Gb 以太网 PHY × 2 个

## 2. JTAG 调试接口引脚连接

引脚编号 | 功能 | 功能描述
J5 | TCK | 测试时钟输入
J4 | TMS | 测试模式选择
J3 | TDI | 测试数据输入
J2 | TDO | 测试数据输出

## 3. 系统时钟源

时钟类型 | FPGA 引脚 | 规格说明
主系统时钟 | K4 | 25MHz 有源晶振，作为系统主时钟源

## 4. LED 状态指示灯

## 5. SPI Flash 存储器 (U12) 引脚连接

LED 编号 | FPGA 引脚 | 功能说明
D2 | A18 | 用户可编程状态指示灯
SPI Flash 引脚 | FPGA 引脚 | 功能描述
引脚名称 | 功能 | 引脚编号 | 说明
CS | 片选信号 | T19 | 低电平有效，选择 SPI Flash
MISO | 主入从出 | R22 | 数据输入线，Flash 输出数据到 FPGA
MOSI | 主出从入 | P22 | 数据输出线，FPGA 输出数据到 Flash
SCK | 时钟信号 | L12 | 串行时钟，由 FPGA 提供

Table 1. DDR2 SODIMM 引脚连接表

功能 | 顶排引 脚 | 底排引 脚 | 功能
GND | 1 | 2 | 5V
GND | 3 | 4 | 5V
GND | 5 | 6 | 5V
GND | 7 | 8 | 5V
GND | 9 | 10 | 5V
GND | 11 | 12 | 5V
NC | 13 | 14 | NC
ETH1_1P | 15 | 16 | ETH2_1P
ETH1_1N | 17 | 18 | ETH2_1N
NC | 19 | 20 | NC
ETH1_2N | 21 | 22 | ETH2_2N
ETH1_2P | 23 | 24 | ETH2_2P
NC | 25 | 26 | NC
ETH1_3P | 27 | 28 | ETH2_3P
ETH1_3N | 29 | 30 | ETH2_3N
NC | 31 | 32 | NC
ETH1_4N | 33 | 34 | ETH2_4N
ETH1_4P | 35 | 36 | ETH2_4P
NC | 37 | 38 | NC
GND | 39 | 40 | GND
R2 | 41 | 42 | P5
NC | 43 | 44 | T6
NC | 45 | 46 | U7
NC | 47 | 48 | U6
T3 | 49 | 50 | U5
T4 | 51 | 52 | V5
NC | 53 | 54 | U1
GND | 55 | 56 | GND
U2 | 57 | 58 | H3
U3 | 59 | 60 | J1
V2 | 61 | 62 | K1
V3 | 63 | 64 | L1

续表：DDR2 SODIMM 引脚连接表
功能 顶排引 脚

底排引
脚

功能

W1 | 65 | 66 | M1
Y1 | 67 | 68 | J2
AA1 | 69 | 70 | K2
AB1 | 71 | 72 | K3
W2 | 73 | 74 | G3
Y2 | 75 | 76 | J4
AB2 | 77 | 78 | G4
AA3 | 79 | 80 | F4
AB3 | 81 | 82 | L4
Y3 | 83 | 84 | R3
W4 | 85 | 86 | M3
AA4 | 87 | 88 | V4
Y4 | 89 | 90 | R4
AB5 | 91 | 92 | T5
AA5 | 93 | 94 | J5
Y6 | 95 | 96 | J6
AB6 | 97 | 98 | W5
AA6 | 99 | 100 | L5
Y7 | 101 | 102 | L6
AB7 | 103 | 104 | W6
GND | 105 | 106 | GND
GND | 107 | 108 | GND
AA8 | 109 | 110 | V7
AB8 | 111 | 112 | N13
Y8 | 113 | 114 | N14
W7 | 115 | 116 | P15
Y9 | 117 | 118 | P16
V8 | 119 | 120 | R16
W9 | 121 | 122 | N17
V9 | 123 | 124 | V17
R14 | 125 | 126 | P17
P14 | 127 | 128 | U17
W17 | 129 | 130 | T18
Y18 | 131 | 132 | R17
AA18 | 133 | 134 | U18
W19 | 135 | 136 | R18
AB18 | 137 | 138 | N18
Y19 | 139 | 140 | R19
AA19 | 141 | 142 | N19
V18 | 143 | 144 | N15
V19 | 145 | 146 | M16
AB20 | 147 | 148 | M15

续表：DDR2 SODIMM 引脚连接表
功能 | 顶排引 脚 | 底排引 脚 | 功能
AA20 | 149 | 150 | L15
AA21 | 151 | 152 | L16
AB21 | 153 | 154 | K14
Y21 | 155 | 156 | N22
GND | 157 | 158 | GND
NC | 159 | 160 | NC
NC | 161 | 162 | NC
NC | 163 | 164 | NC
NC | 165 | 166 | NC
NC | 167 | 168 | NC
NC | 169 | 170 | NC
NC | 171 | 172 | NC
NC | 173 | 174 | NC
NC | 175 | 176 | NC
NC | 177 | 178 | NC
NC | 179 | 180 | NC
NC | 181 | 182 | NC
NC | 183 | 184 | NC
NC | 185 | 186 | NC
NC | 187 | 188 | NC
NC | 189 | 190 | NC
NC | 191 | 192 | NC
NC | 193 | 194 | NC
NC | 195 | 196 | NC
NC | 197 | 198 | NC
GND | 199 | 200 | GND

## 7. SDRAM (U6) 完整引脚连接表

Table 2. SDRAM (U6) 完整引脚连接表
SDRAM 引脚 | FPGA 引 脚/连接 | 功能说明
CLK | E14 | 时钟输入引脚
CKE | VCC | 时钟使能，接电 源
CS | GND | 片选，接地
RAS | A14 | 行地址选通
CAS | D14 | 列地址选通
WE | D17 | 写使能

续表: SDRAM (U6) 完整引脚连接表
SDRAM 引脚 | FPGA 引 脚/连接 | 功能说明
DQM0 | GND | 数据掩码 0，接 地
DQM1 | GND | 数据掩码 1，接 地
DQM2 | GND | 数据掩码 2，接 地
DQM3 | GND | 数据掩码 3，接 地
BA0 | D19 | Bank 地址 0
BA1 | B13 | Bank 地址 1
A0 | C20 | 地址线 0
A1 | C19 | 地址线 1
A2 | C13 | 地址线 2
A3 | F13 | 地址线 3
A4 | G13 | 地址线 4
A5 | G15 | 地址线 5
A6 | F14 | 地址线 6
A7 | F18 | 地址线 7
A8 | E13 | 地址线 8
A9 | E18 | 地址线 9
A10 | C14 | 地址线 10
DQ0 | F21 | 数据线 0
DQ1 | E22 | 数据线 1
DQ2 | F20 | 数据线 2
DQ3 | E21 | 数据线 3
DQ4 | F19 | 数据线 4
DQ5 | D22 | 数据线 5
DQ6 | E19 | 数据线 6
DQ7 | D21 | 数据线 7
DQ8 | K21 | 数据线 8
DQ9 | L21 | 数据线 9
DQ10 | K22 | 数据线 10
DQ11 | M21 | 数据线 11
DQ12 | L20 | 数据线 12
DQ13 | M22 | 数据线 13
DQ14 | N20 | 数据线 14
DQ15 | M20 | 数据线 15
DQ16 | B18 | 数据线 16
DQ17 | D20 | 数据线 17
DQ18 | A19 | 数据线 18
DQ19 | A21 | 数据线 19
DQ20 | A20 | 数据线 20

续表: SDRAM (U6) 完整引脚连接表
SDRAM 引脚 | FPGA 引 脚/连接 | 功能说明
DQ21 | B21 | 数据线 21
DQ22 | C22 | 数据线 22
DQ23 | B22 | 数据线 23
DQ24 | G21 | 数据线 24
DQ25 | G22 | 数据线 25
DQ26 | H20 | 数据线 26
DQ27 | H22 | 数据线 27
DQ28 | J20 | 数据线 28
DQ29 | J22 | 数据线 29
DQ30 | G20 | 数据线 30
DQ31 | J21 | 数据线 31

## 8. 以太网 PHY 0 (U5) 完整引脚连接表

Table 3. 以太网 PHY 0 (U5) 完整引脚连接表
U5 引脚 | 功能名称 | FPGA 引脚 | 详细描述
MDC | 管理数据时钟 | G1 | MDIO 接口时钟信号
MDIO | 管理数据输入输 出 | G2 | MDIO 接口双向数据线
RESET | 复位信号 | H2 | PHY 复位控制信号
GTXCLK | 发送时钟 | A1 | 千兆发送时钟
TXD[0] | 发送数据 0 | B2 | 发送数据位 0
TXD[1] | 发送数据 1 | B1 | 发送数据位 1
TXD[2] | 发送数据 2 | C2 | 发送数据位 2
TXD[3] | 发送数据 3 | D2 | 发送数据位 3
TX_EN | 发送使能 | D1 | 发送使能控制信号
RXC | 接收时钟 | H2/H4 | 接收时钟（双引脚连接）
RXD[0] | 接收数据 0 | E3 | 接收数据位 0
RXD[1] | 接收数据 1 | E2 | 接收数据位 1
RXD[2] | 接收数据 2 | E1 | 接收数据位 2
RXD[3] | 接收数据 3 | F3 | 接收数据位 3
RX_DV | 接收数据有效 | F1 | 接收数据有效指示信号

## 9. 以太网 PHY 1 (U9) 完整引脚连接表

Table 4. 以太网 PHY 1 (U9) 完整引脚连接表
U9 引脚 | 功能名称 | FPGA 引脚 | 详细描述
MDC | 管理数据时钟 | G1 | MDIO 接口时钟信号
MDIO | 管理数据输入输 出 | G2 | MDIO 接口双向数据线
RESET | 复位信号 | H2 | PHY 复位控制信号
GTXCLK | 发送时钟 | M6 | 千兆发送时钟
TXD[0] | 发送数据 0 | M5 | 发送数据位 0
TXD[1] | 发送数据 1 | M2 | 发送数据位 1
TXD[2] | 发送数据 2 | N4 | 发送数据位 2
TXD[3] | 发送数据 3 | P4 | 发送数据位 3
TX_EN | 发送使能 | N5 | 发送使能控制信号
RXC | 接收时钟 | L3/H2 | 接收时钟（双引脚连接）
RXD[0] | 接收数据 0 | N2 | 接收数据位 0
RXD[1] | 接收数据 1 | N3 | 接收数据位 1
RXD[2] | 接收数据 2 | P1 | 接收数据位 2
RXD[3] | 接收数据 3 | P2 | 接收数据位 3
RX_DV | 接收数据有效 | R1 | 接收数据有效指示信号

文档完整性声明
本技术文档完整包含了所有原始引脚连接信息，无任何内容删减。 包含：200 个 DDR2 SODIMM 引脚、32 个 SDRAM 数据线、11 个 SDRAM 地址线、 所有以太网 PHY 信号以及其他所有系统连接。
总记录引脚数：350+ 个引脚连接关系
版本：1.0 | 生成日期：December 25, 2025
文档状态：完整准确

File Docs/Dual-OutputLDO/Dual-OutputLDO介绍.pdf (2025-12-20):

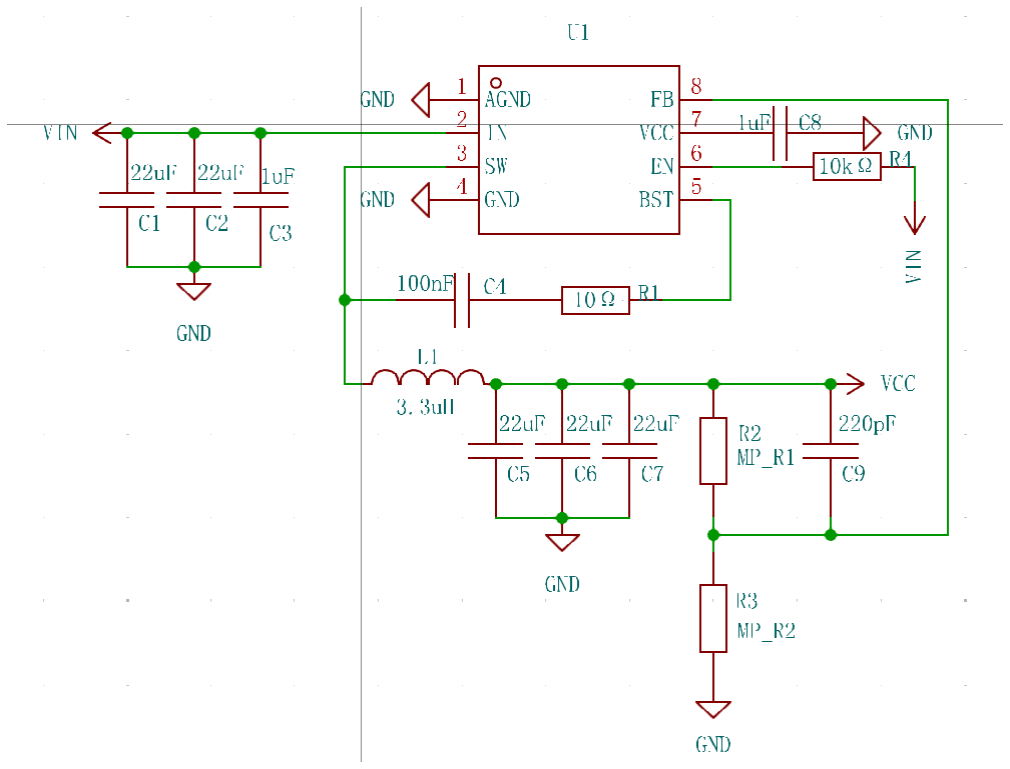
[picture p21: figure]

图1 MP2236模块

# Dual-OutputLDO

LM27762 是一款低噪声正负输出集成式电荷泵与 LDO 芯片，能够从单路输入（2.7V‑5.5V）同时生 成可调节的正电压（1.5V‑5V）和负电压（‑1.5V‑ ‑5V），输出电流可达 ±250mA。其特点包括采用反相 电荷泵后接负 LDO 的结构，开关频率为 2MHz，输出噪声极低（典型值 22μVrms），并具有独立的使 能控制和电源正常（PGOOD）指示功能。重要参数包括静态电流仅 390μA（典型值）、关断电流 0.5μA，正/负 LDO 在 100mA 负载下的压降分别为 45mV 和 30mV，适用于音频放大器、运放偏置、数 据转换器等需要低噪声正负电源的场景。

MP2236 是一款 18V、6A 高效率同步降压转换器，采用恒定导通时间（COT）控制，提供快速瞬态 响应和简易的环路补偿。其输入电压范围宽达 3V‑18V，支持最大 6A 连续输出电流，内部集成低导通电 阻的功率 MOSFET（25mΩ/12mΩ）。该器件默认参考电压为 600mV，开关频率为 600kHz，并具备打 嗝式过流保护（OCP）和热关断功能。重要参数包括轻载时静态电流 150μA（典型值）、关断电流低于 1μA，以及内部软启动时间约 1ms，主要应用于平板电视、数字电视电源、分布式电源系统等中高功率 降压转换场合。

## 硬件设计

MP2236是一款同步降压（Step-Down）转换器，其核心任务是将较高的输入电压（如12V）高效、 稳定地转换为一个更低的、可精确设定的中间电压（VCC）。这个电压的设定完全由一个连接在输出端 与反馈（FB）引脚之间的外部电阻分压网络决定。计算遵循公式 Vout = 0.6V × (1 + R1/R2)，其中0.6V 是芯片内部的精密基准电压。通过改变R1与R2的阻值比例，即可在0.6V至输入电压的范围内线性调节输 出电压。MP2236采用恒定导通时间（COT）控制模式，能根据输入、输出电压实时调整开关频率，在宽 输入范围内保持效率与快速瞬态响应。其输出的VCC电压的精度和稳定性，直接决定了后续电路供电平 台的质量。

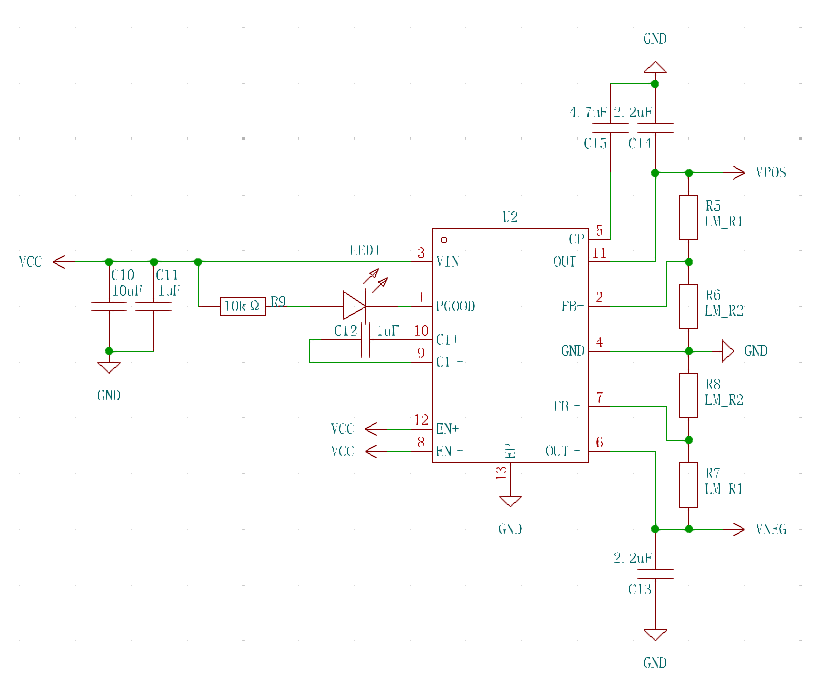
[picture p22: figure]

图2 LM27762模块

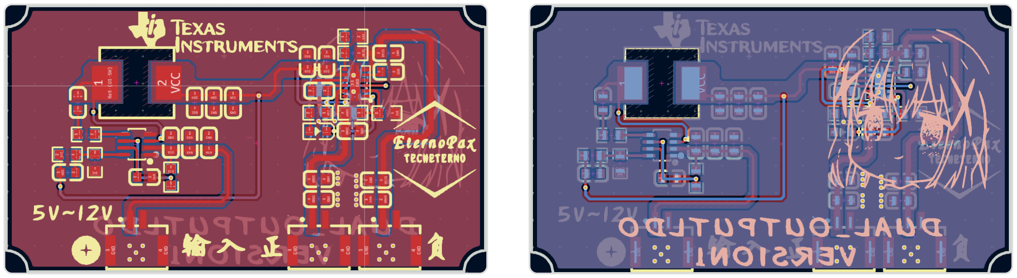
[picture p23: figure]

图3 Dual-OutputLDO PCB设计

LM27762则是一个集成了电荷泵和低压差线性稳压器（LDO）的独特芯片，它能从一个单路正输入 （即MP2236提供的VCC）同时产生一组相互独立、低噪声的正负输出电压（如+3.3V和-3.3V）。其每路 输出都拥有独立的反馈控制环路：正输出由基准电压1.2V和电阻R1、R2设定（公式：Vout+ = 1.2V × (R1+R2)/R2），负输出则由基准电压-1.22V和电阻R3、R4设定（公式：Vout- = -1.22V × (R3+R4)/R4）。一个关键的设计约束是，为了保障LDO环路的稳定，连接到地的反馈电阻R2和R4必须不 小于50kΩ。这种设计允许工程师灵活配置不对称的双电源（如+5V/-3V），但为了获得最佳性能，正负 输出的电阻需分别计算以确保精度。

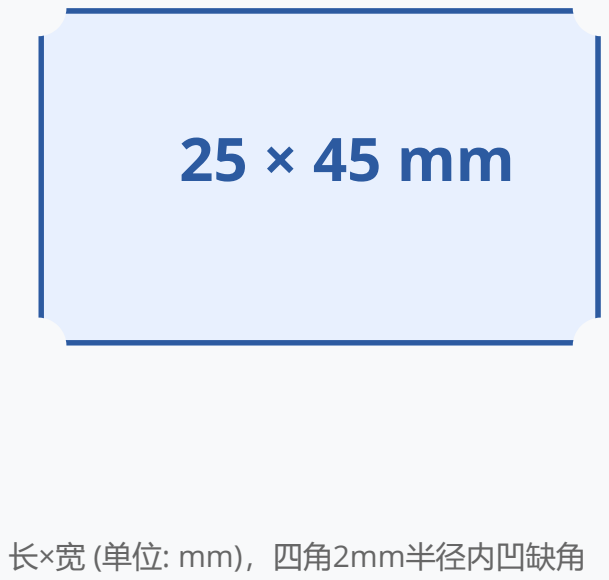
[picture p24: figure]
长×宽 (单位: mm)，四角2mm半径内凹缺角

安装孔半径

## 2 mm

安装孔数量
4个

板厚

## 1.6 mm

安装孔位置

## 四角对称

目标输出 (LM27762) | 推荐VCC (MP2236) | MP2236 电 阻配置 (产 生VCC) | LM27762 正输出电阻 配置 | LM27762 负输出电阻 配置 | 计算实际电压
±3.3V | 4.0V | R1: 267kΩ R2: 47.5kΩ | R1: 174kΩ R2: 100kΩ | R3: 169kΩ R4: 100kΩ | VCC≈3.99V VOUT+≈3.30V VOUT-≈-3.29V

## 使用注意

在焊接过程中需注意反馈电阻的选择,原理图上为标注电阻大小的作为反馈电阻,具体取值参考附 录
在使用前尽可能先估算电压电流大小,该电路板不适合通过大电流 用户需要采用4个铜柱+螺母将PCB固定
由于可以同时输出正负电压,所以在使用过程中注意散热

## 附录:建议匹配电阻

目标输出 (LM27762) | 推荐VCC (MP2236) | MP2236 电 阻配置 (产 生VCC) | LM27762 正输出电阻 配置 | LM27762 负输出电阻 配置 | 计算实际电压
±1.8V | 2.5V | R1: 158kΩ R2: 49.9kΩ | R1: 51.1kΩ R2: 100kΩ | R3: 47.5kΩ R4: 100kΩ | VCC≈2.50V VOUT+≈1.81V VOUT-≈-1.80V
±2.5V | 3.3V | R1: 287kΩ R2: 63.4kΩ | R1: 127kΩ R2: 100kΩ | R3: 124kΩ R4: 100kΩ | VCC≈3.30V VOUT+≈2.51V VOUT-≈-2.50V

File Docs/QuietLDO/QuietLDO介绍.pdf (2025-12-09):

# QuietLDO

图1 TPS7A47模块; 这一个基本的TPS7A47模块,在实际使用时,需要考虑右侧八个电阻的有无.在其配置中他有1.4V到 20.5V的输出,步长为0.1V,计算公式如下:V_; 但实际上我们在实际需求时只需要6V以下的电压,过大的电压在实际中并不适合LDO,超过7V的输入 在实际使用中会使得该电路发热多大,于是我们采用MP2236作为前级DCDC降压.

MP2236 是一款由 MPS 生产的高效率同步降压转换器，其输入电压范围为 3V 至 18V，并能提供高
达 6A 的连续输出电流。它采用恒定导通时间控制模式，具有快速的瞬态响应能力，开关频率为
600kHz，且集成了低导通电阻的功率 MOSFET，使其在宽负载范围内都能保持高效。该芯片内置了打嗝
模式的过流保护、热关断和欠压锁定等全面保护功能，外围元件精简，采用紧凑的 TSOT23-8 封装，非
常适用于平板显示器、数字电视电源和分布式电源系统等需要高电流密度和高效能的应用场景。
TPS7A47 系列是德州仪器推出的一款高压、超低噪声的 LDO 线性稳压器，包括 TPS7A4700 和
TPS7A4701 两个型号。它的输入电压范围宽达 3V 至 36V，输出电流为 1A，其最突出的特点是极低的输
出噪声（仅 4µVrms）和极高的电源抑制比，能为核心模拟电路提供极其洁净的电压轨。TPS7A4700 可
通过独特的 ANY-OUT 引脚编程方式设置输出电压（1.4V 至 20.5V），无需外部电阻；TPS7A4701 还支
持通过外部电阻在更宽范围（至 34V）内调节。该器件采用带散热焊盘的 VQFN 封装，是射频电路、高
精度 ADC/DAC、测试测量以及医疗音频等噪声敏感型应用的理想选择。
硬件设计


### 图2 MP2236模块

导线宽度(mils) | 最大电流(A)
10 | 1.2927
40 | 3.2097
60 | 4.1041
120 | 6.1992


### 图3 QuietPCB设计

在PCB设计主要注意MP2236的大电流布局和TPS7A47的电源布局.通过PCB ToolKit,我们可以计算出 以下几个数据:

可以发现在实际中我们过6A的上限电流是实现不了的,当我们可以使用40mils+铺铜的布线方式增大 电流的上限.

PCB尺寸示意图

### 长×宽 (单位: mm)

安装孔直径

## 3.2 mm

安装孔数量
4个

板厚

## 1.6 mm

安装孔位置

## 四角对称

组合 编号 | OP1V | OP2V | OP4V | OP8V | 1P6V | 3P2V | 6P4V1 | 6P4V2 | 输出 电压 (V) | 二进制
0 | 0V | 0V | 0V | 0V | 0V | 0V | 0V | 0V | 1.4 | 00000000
1 | 0.1V | 0V | 0V | 0V | 0V | 0V | 0V | 0V | 1.5 | 00000001
2 | 0V | 0.2V | 0V | 0V | 0V | 0V | 0V | 0V | 1.6 | 00000010
3 | 0.1V | 0.2V | 0V | 0V | 0V | 0V | 0V | 0V | 1.7 | 00000011
4 | 0V | 0V | 0.4V | 0V | 0V | 0V | 0V | 0V | 1.8 | 00000100
5 | 0.1V | 0V | 0.4V | 0V | 0V | 0V | 0V | 0V | 1.9 | 00000101
6 | 0V | 0.2V | 0.4V | 0V | 0V | 0V | 0V | 0V | 2.0 | 00000110
7 | 0.1V | 0.2V | 0.4V | 0V | 0V | 0V | 0V | 0V | 2.1 | 00000111
8 | 0V | 0V | 0V | 0.8V | 0V | 0V | 0V | 0V | 2.2 | 00001000
9 | 0.1V | 0V | 0V | 0.8V | 0V | 0V | 0V | 0V | 2.3 | 00001001
10 | 0V | 0.2V | 0V | 0.8V | 0V | 0V | 0V | 0V | 2.4 | 00001010
11 | 0.1V | 0.2V | 0V | 0.8V | 0V | 0V | 0V | 0V | 2.5 | 00001011
12 | 0V | 0V | 0.4V | 0.8V | 0V | 0V | 0V | 0V | 2.6 | 00001100
13 | 0.1V | 0V | 0.4V | 0.8V | 0V | 0V | 0V | 0V | 2.7 | 00001101
14 | 0V | 0.2V | 0.4V | 0.8V | 0V | 0V | 0V | 0V | 2.8 | 00001110
15 | 0.1V | 0.2V | 0.4V | 0.8V | 0V | 0V | 0V | 0V | 2.9 | 00001111
16 | 0V | 0V | 0V | 0V | 1.6V | 0V | 0V | 0V | 3.0 | 00010000
17 | 0.1V | 0V | 0V | 0V | 1.6V | 0V | 0V | 0V | 3.1 | 00010001

# 使用注意

在焊接过程中需注意5V,3V3和1V8的电阻焊接问题,可以阅读原理图,对于NC的电阻不进行焊接, 也可以参考PCB,标有圆圈的电阻需要焊接
在使用前请尽可能先估计电压大小和电流电小,输出端建议每路(4个GH1.25)不超过1A,输出总电 流不超过4A,输入电压尽可能控制在7.4V-12V
用户需采用4个M3的铜柱踮起,尽可能避免该PCB处于射频信号的附近或不必要接触

# 附录:可调端所有可能输出

组合 编号 | OP1V | OP2V | OP4V | OP8V | 1P6V | 3P2V | 6P4V1 | 6P4V2 | 输出 电压 (V) | 二进制
18 | 0V | 0.2V | 0V | 0V | 1.6V | 0V | 0V | 0V | 3.2 | 00010010
19 | 0.1V | 0.2V | 0V | 0V | 1.6V | 0V | 0V | 0V | 3.3 | 00010011
20 | 0V | 0V | 0.4V | 0V | 1.6V | 0V | 0V | 0V | 3.4 | 00010100
21 | 0.1V | 0V | 0.4V | 0V | 1.6V | 0V | 0V | 0V | 3.5 | 00010101
22 | 0V | 0.2V | 0.4V | 0V | 1.6V | 0V | 0V | 0V | 3.6 | 00010110
23 | 0.1V | 0.2V | 0.4V | 0V | 1.6V | 0V | 0V | 0V | 3.7 | 00010111
24 | 0V | 0V | 0V | 0.8V | 1.6V | 0V | 0V | 0V | 3.8 | 00011000
25 | 0.1V | 0V | 0V | 0.8V | 1.6V | 0V | 0V | 0V | 3.9 | 00011001
26 | 0V | 0.2V | 0V | 0.8V | 1.6V | 0V | 0V | 0V | 4.0 | 00011010
27 | 0.1V | 0.2V | 0V | 0.8V | 1.6V | 0V | 0V | 0V | 4.1 | 00011011
28 | 0V | 0V | 0.4V | 0.8V | 1.6V | 0V | 0V | 0V | 4.2 | 00011100
29 | 0.1V | 0V | 0.4V | 0.8V | 1.6V | 0V | 0V | 0V | 4.3 | 00011101
30 | 0V | 0.2V | 0.4V | 0.8V | 1.6V | 0V | 0V | 0V | 4.4 | 00011110
31 | 0.1V | 0.2V | 0.4V | 0.8V | 1.6V | 0V | 0V | 0V | 4.5 | 00011111
32 | 0V | 0V | 0V | 0V | 0V | 3.2V | 0V | 0V | 4.6 | 00100000
33 | 0.1V | 0V | 0V | 0V | 0V | 3.2V | 0V | 0V | 4.7 | 00100001
34 | 0V | 0.2V | 0V | 0V | 0V | 3.2V | 0V | 0V | 4.8 | 00100010
35 | 0.1V | 0.2V | 0V | 0V | 0V | 3.2V | 0V | 0V | 4.9 | 00100011
36 | 0V | 0V | 0.4V | 0V | 0V | 3.2V | 0V | 0V | 5.0 | 00100100
37 | 0.1V | 0V | 0.4V | 0V | 0V | 3.2V | 0V | 0V | 5.1 | 00100101
38 | 0V | 0.2V | 0.4V | 0V | 0V | 3.2V | 0V | 0V | 5.2 | 00100110
39 | 0.1V | 0.2V | 0.4V | 0V | 0V | 3.2V | 0V | 0V | 5.3 | 00100111
40 | 0V | 0V | 0V | 0.8V | 0V | 3.2V | 0V | 0V | 5.4 | 00101000
41 | 0.1V | 0V | 0V | 0.8V | 0V | 3.2V | 0V | 0V | 5.5 | 00101001
42 | 0V | 0.2V | 0V | 0.8V | 0V | 3.2V | 0V | 0V | 5.6 | 00101010
43 | 0.1V | 0.2V | 0V | 0.8V | 0V | 3.2V | 0V | 0V | 5.7 | 00101011
44 | 0V | 0V | 0.4V | 0.8V | 0V | 3.2V | 0V | 0V | 5.8 | 00101100
45 | 0.1V | 0V | 0.4V | 0.8V | 0V | 3.2V | 0V | 0V | 5.9 | 00101101
46 | 0V | 0.2V | 0.4V | 0.8V | 0V | 3.2V | 0V | 0V | 6.0 | 00101110
47 | 0.1V | 0.2V | 0.4V | 0.8V | 0V | 3.2V | 0V | 0V | 6.1 | 00101111
48 | 0V | 0V | 0V | 0V | 1.6V | 3.2V | 0V | 0V | 6.2 | 00110000
49 | 0.1V | 0V | 0V | 0V | 1.6V | 3.2V | 0V | 0V | 6.3 | 00110001
50 | 0V | 0.2V | 0V | 0V | 1.6V | 3.2V | 0V | 0V | 6.4 | 00110010
51 | 0.1V | 0.2V | 0V | 0V | 1.6V | 3.2V | 0V | 0V | 6.5 | 00110011

52 | 0V | 0V | 0.4V | 0V | 1.6V | 3.2V | 0V | 0V | 6.6 | 00110100
53 | 0.1V | 0V | 0.4V | 0V | 1.6V | 3.2V | 0V | 0V | 6.7 | 00110101
54 | 0V | 0.2V | 0.4V | 0V | 1.6V | 3.2V | 0V | 0V | 6.8 | 00110110
55 | 0.1V | 0.2V | 0.4V | 0V | 1.6V | 3.2V | 0V | 0V | 6.9 | 00110111
56 | 0V | 0V | 0V | 0.8V | 1.6V | 3.2V | 0V | 0V | 7.0 | 00111000
57 | 0.1V | 0V | 0V | 0.8V | 1.6V | 3.2V | 0V | 0V | 7.1 | 00111001
58 | 0V | 0.2V | 0V | 0.8V | 1.6V | 3.2V | 0V | 0V | 7.2 | 00111010
59 | 0.1V | 0.2V | 0V | 0.8V | 1.6V | 3.2V | 0V | 0V | 7.3 | 00111011
60 | 0V | 0V | 0.4V | 0.8V | 1.6V | 3.2V | 0V | 0V | 7.4 | 00111100
61 | 0.1V | 0V | 0.4V | 0.8V | 1.6V | 3.2V | 0V | 0V | 7.5 | 00111101
62 | 0V | 0.2V | 0.4V | 0.8V | 1.6V | 3.2V | 0V | 0V | 7.6 | 00111110
63 | 0.1V | 0.2V | 0.4V | 0.8V | 1.6V | 3.2V | 0V | 0V | 7.7 | 00111111
64 | 0V | 0V | 0V | 0V | 0V | 0V | 6.4V | 0V | 7.8 | 01000000
65 | 0.1V | 0V | 0V | 0V | 0V | 0V | 6.4V | 0V | 7.9 | 01000001
66 | 0V | 0.2V | 0V | 0V | 0V | 0V | 6.4V | 0V | 8.0 | 01000010
67 | 0.1V | 0.2V | 0V | 0V | 0V | 0V | 6.4V | 0V | 8.1 | 01000011
68 | 0V | 0V | 0.4V | 0V | 0V | 0V | 6.4V | 0V | 8.2 | 01000100
69 | 0.1V | 0V | 0.4V | 0V | 0V | 0V | 6.4V | 0V | 8.3 | 01000101
70 | 0V | 0.2V | 0.4V | 0V | 0V | 0V | 6.4V | 0V | 8.4 | 01000110
71 | 0.1V | 0.2V | 0.4V | 0V | 0V | 0V | 6.4V | 0V | 8.5 | 01000111
72 | 0V | 0V | 0V | 0.8V | 0V | 0V | 6.4V | 0V | 8.6 | 01001000
73 | 0.1V | 0V | 0V | 0.8V | 0V | 0V | 6.4V | 0V | 8.7 | 01001001
74 | 0V | 0.2V | 0V | 0.8V | 0V | 0V | 6.4V | 0V | 8.8 | 01001010
75 | 0.1V | 0.2V | 0V | 0.8V | 0V | 0V | 6.4V | 0V | 8.9 | 01001011
76 | 0V | 0V | 0.4V | 0.8V | 0V | 0V | 6.4V | 0V | 9.0 | 01001100
77 | 0.1V | 0V | 0.4V | 0.8V | 0V | 0V | 6.4V | 0V | 9.1 | 01001101
78 | 0V | 0.2V | 0.4V | 0.8V | 0V | 0V | 6.4V | 0V | 9.2 | 01001110
79 | 0.1V | 0.2V | 0.4V | 0.8V | 0V | 0V | 6.4V | 0V | 9.3 | 01001111
80 | 0V | 0V | 0V | 0V | 1.6V | 0V | 6.4V | 0V | 9.4 | 01010000
81 | 0.1V | 0V | 0V | 0V | 1.6V | 0V | 6.4V | 0V | 9.5 | 01010001
82 | 0V | 0.2V | 0V | 0V | 1.6V | 0V | 6.4V | 0V | 9.6 | 01010010
83 | 0.1V | 0.2V | 0V | 0V | 1.6V | 0V | 6.4V | 0V | 9.7 | 01010011
84 | 0V | 0V | 0.4V | 0V | 1.6V | 0V | 6.4V | 0V | 9.8 | 01010100
85 | 0.1V | 0V | 0.4V | 0V | 1.6V | 0V | 6.4V | 0V | 9.9 | 01010101

86 | 0V | 0.2V | 0.4V | 0V | 1.6V | 0V | 6.4V | 0V | 10.0 | 01010110
87 | 0.1V | 0.2V | 0.4V | 0V | 1.6V | 0V | 6.4V | 0V | 10.1 | 01010111
88 | 0V | 0V | 0V | 0.8V | 1.6V | 0V | 6.4V | 0V | 10.2 | 01011000
89 | 0.1V | 0V | 0V | 0.8V | 1.6V | 0V | 6.4V | 0V | 10.3 | 01011001
90 | 0V | 0.2V | 0V | 0.8V | 1.6V | 0V | 6.4V | 0V | 10.4 | 01011010
91 | 0.1V | 0.2V | 0V | 0.8V | 1.6V | 0V | 6.4V | 0V | 10.5 | 01011011
92 | 0V | 0V | 0.4V | 0.8V | 1.6V | 0V | 6.4V | 0V | 10.6 | 01011100
93 | 0.1V | 0V | 0.4V | 0.8V | 1.6V | 0V | 6.4V | 0V | 10.7 | 01011101
94 | 0V | 0.2V | 0.4V | 0.8V | 1.6V | 0V | 6.4V | 0V | 10.8 | 01011110
95 | 0.1V | 0.2V | 0.4V | 0.8V | 1.6V | 0V | 6.4V | 0V | 10.9 | 01011111
96 | 0V | 0V | 0V | 0V | 0V | 3.2V | 6.4V | 0V | 11.0 | 01100000
97 | 0.1V | 0V | 0V | 0V | 0V | 3.2V | 6.4V | 0V | 11.1 | 01100001
98 | 0V | 0.2V | 0V | 0V | 0V | 3.2V | 6.4V | 0V | 11.2 | 01100010
99 | 0.1V | 0.2V | 0V | 0V | 0V | 3.2V | 6.4V | 0V | 11.3 | 01100011
100 | 0V | 0V | 0.4V | 0V | 0V | 3.2V | 6.4V | 0V | 11.4 | 01100100
101 | 0.1V | 0V | 0.4V | 0V | 0V | 3.2V | 6.4V | 0V | 11.5 | 01100101
102 | 0V | 0.2V | 0.4V | 0V | 0V | 3.2V | 6.4V | 0V | 11.6 | 01100110
103 | 0.1V | 0.2V | 0.4V | 0V | 0V | 3.2V | 6.4V | 0V | 11.7 | 01100111
104 | 0V | 0V | 0V | 0.8V | 0V | 3.2V | 6.4V | 0V | 11.8 | 01101000
105 | 0.1V | 0V | 0V | 0.8V | 0V | 3.2V | 6.4V | 0V | 11.9 | 01101001
106 | 0V | 0.2V | 0V | 0.8V | 0V | 3.2V | 6.4V | 0V | 12.0 | 01101010
107 | 0.1V | 0.2V | 0V | 0.8V | 0V | 3.2V | 6.4V | 0V | 12.1 | 01101011
108 | 0V | 0V | 0.4V | 0.8V | 0V | 3.2V | 6.4V | 0V | 12.2 | 01101100
109 | 0.1V | 0V | 0.4V | 0.8V | 0V | 3.2V | 6.4V | 0V | 12.3 | 01101101
110 | 0V | 0.2V | 0.4V | 0.8V | 0V | 3.2V | 6.4V | 0V | 12.4 | 01101110
111 | 0.1V | 0.2V | 0.4V | 0.8V | 0V | 3.2V | 6.4V | 0V | 12.5 | 01101111
112 | 0V | 0V | 0V | 0V | 1.6V | 3.2V | 6.4V | 0V | 12.6 | 01110000
113 | 0.1V | 0V | 0V | 0V | 1.6V | 3.2V | 6.4V | 0V | 12.7 | 01110001
114 | 0V | 0.2V | 0V | 0V | 1.6V | 3.2V | 6.4V | 0V | 12.8 | 01110010
115 | 0.1V | 0.2V | 0V | 0V | 1.6V | 3.2V | 6.4V | 0V | 12.9 | 01110011
116 | 0V | 0V | 0.4V | 0V | 1.6V | 3.2V | 6.4V | 0V | 13.0 | 01110100
117 | 0.1V | 0V | 0.4V | 0V | 1.6V | 3.2V | 6.4V | 0V | 13.1 | 01110101
118 | 0V | 0.2V | 0.4V | 0V | 1.6V | 3.2V | 6.4V | 0V | 13.2 | 01110110
119 | 0.1V | 0.2V | 0.4V | 0V | 1.6V | 3.2V | 6.4V | 0V | 13.3 | 01110111

120 | 0V | 0V | 0V | 0.8V | 1.6V | 3.2V | 6.4V | 0V | 13.4 | 01111000
121 | 0.1V | 0V | 0V | 0.8V | 1.6V | 3.2V | 6.4V | 0V | 13.5 | 01111001
122 | 0V | 0.2V | 0V | 0.8V | 1.6V | 3.2V | 6.4V | 0V | 13.6 | 01111010
123 | 0.1V | 0.2V | 0V | 0.8V | 1.6V | 3.2V | 6.4V | 0V | 13.7 | 01111011
124 | 0V | 0V | 0.4V | 0.8V | 1.6V | 3.2V | 6.4V | 0V | 13.8 | 01111100
125 | 0.1V | 0V | 0.4V | 0.8V | 1.6V | 3.2V | 6.4V | 0V | 13.9 | 01111101
126 | 0V | 0.2V | 0.4V | 0.8V | 1.6V | 3.2V | 6.4V | 0V | 14.0 | 01111110
127 | 0.1V | 0.2V | 0.4V | 0.8V | 1.6V | 3.2V | 6.4V | 0V | 14.1 | 01111111
128 | 0V | 0V | 0V | 0V | 0V | 0V | 0V | 6.4V | 7.8 | 10000000
129 | 0.1V | 0V | 0V | 0V | 0V | 0V | 0V | 6.4V | 7.9 | 10000001
130 | 0V | 0.2V | 0V | 0V | 0V | 0V | 0V | 6.4V | 8.0 | 10000010
131 | 0.1V | 0.2V | 0V | 0V | 0V | 0V | 0V | 6.4V | 8.1 | 10000011
132 | 0V | 0V | 0.4V | 0V | 0V | 0V | 0V | 6.4V | 8.2 | 10000100
133 | 0.1V | 0V | 0.4V | 0V | 0V | 0V | 0V | 6.4V | 8.3 | 10000101
134 | 0V | 0.2V | 0.4V | 0V | 0V | 0V | 0V | 6.4V | 8.4 | 10000110
135 | 0.1V | 0.2V | 0.4V | 0V | 0V | 0V | 0V | 6.4V | 8.5 | 10000111
136 | 0V | 0V | 0V | 0.8V | 0V | 0V | 0V | 6.4V | 8.6 | 10001000
137 | 0.1V | 0V | 0V | 0.8V | 0V | 0V | 0V | 6.4V | 8.7 | 10001001
138 | 0V | 0.2V | 0V | 0.8V | 0V | 0V | 0V | 6.4V | 8.8 | 10001010
139 | 0.1V | 0.2V | 0V | 0.8V | 0V | 0V | 0V | 6.4V | 8.9 | 10001011
140 | 0V | 0V | 0.4V | 0.8V | 0V | 0V | 0V | 6.4V | 9.0 | 10001100
141 | 0.1V | 0V | 0.4V | 0.8V | 0V | 0V | 0V | 6.4V | 9.1 | 10001101
142 | 0V | 0.2V | 0.4V | 0.8V | 0V | 0V | 0V | 6.4V | 9.2 | 10001110
143 | 0.1V | 0.2V | 0.4V | 0.8V | 0V | 0V | 0V | 6.4V | 9.3 | 10001111
144 | 0V | 0V | 0V | 0V | 1.6V | 0V | 0V | 6.4V | 9.4 | 10010000
145 | 0.1V | 0V | 0V | 0V | 1.6V | 0V | 0V | 6.4V | 9.5 | 10010001
146 | 0V | 0.2V | 0V | 0V | 1.6V | 0V | 0V | 6.4V | 9.6 | 10010010
147 | 0.1V | 0.2V | 0V | 0V | 1.6V | 0V | 0V | 6.4V | 9.7 | 10010011
148 | 0V | 0V | 0.4V | 0V | 1.6V | 0V | 0V | 6.4V | 9.8 | 10010100
149 | 0.1V | 0V | 0.4V | 0V | 1.6V | 0V | 0V | 6.4V | 9.9 | 10010101
150 | 0V | 0.2V | 0.4V | 0V | 1.6V | 0V | 0V | 6.4V | 10.0 | 10010110
151 | 0.1V | 0.2V | 0.4V | 0V | 1.6V | 0V | 0V | 6.4V | 10.1 | 10010111
152 | 0V | 0V | 0V | 0.8V | 1.6V | 0V | 0V | 6.4V | 10.2 | 10011000
153 | 0.1V | 0V | 0V | 0.8V | 1.6V | 0V | 0V | 6.4V | 10.3 | 10011001

154 | 0V | 0.2V | 0V | 0.8V | 1.6V | 0V | 0V | 6.4V | 10.4 | 10011010
155 | 0.1V | 0.2V | 0V | 0.8V | 1.6V | 0V | 0V | 6.4V | 10.5 | 10011011
156 | 0V | 0V | 0.4V | 0.8V | 1.6V | 0V | 0V | 6.4V | 10.6 | 10011100
157 | 0.1V | 0V | 0.4V | 0.8V | 1.6V | 0V | 0V | 6.4V | 10.7 | 10011101
158 | 0V | 0.2V | 0.4V | 0.8V | 1.6V | 0V | 0V | 6.4V | 10.8 | 10011110
159 | 0.1V | 0.2V | 0.4V | 0.8V | 1.6V | 0V | 0V | 6.4V | 10.9 | 10011111
160 | 0V | 0V | 0V | 0V | 0V | 3.2V | 0V | 6.4V | 11.0 | 10100000
161 | 0.1V | 0V | 0V | 0V | 0V | 3.2V | 0V | 6.4V | 11.1 | 10100001
162 | 0V | 0.2V | 0V | 0V | 0V | 3.2V | 0V | 6.4V | 11.2 | 10100010
163 | 0.1V | 0.2V | 0V | 0V | 0V | 3.2V | 0V | 6.4V | 11.3 | 10100011
164 | 0V | 0V | 0.4V | 0V | 0V | 3.2V | 0V | 6.4V | 11.4 | 10100100
165 | 0.1V | 0V | 0.4V | 0V | 0V | 3.2V | 0V | 6.4V | 11.5 | 10100101
166 | 0V | 0.2V | 0.4V | 0V | 0V | 3.2V | 0V | 6.4V | 11.6 | 10100110
167 | 0.1V | 0.2V | 0.4V | 0V | 0V | 3.2V | 0V | 6.4V | 11.7 | 10100111
168 | 0V | 0V | 0V | 0.8V | 0V | 3.2V | 0V | 6.4V | 11.8 | 10101000
169 | 0.1V | 0V | 0V | 0.8V | 0V | 3.2V | 0V | 6.4V | 11.9 | 10101001
170 | 0V | 0.2V | 0V | 0.8V | 0V | 3.2V | 0V | 6.4V | 12.0 | 10101010
171 | 0.1V | 0.2V | 0V | 0.8V | 0V | 3.2V | 0V | 6.4V | 12.1 | 10101011
172 | 0V | 0V | 0.4V | 0.8V | 0V | 3.2V | 0V | 6.4V | 12.2 | 10101100
173 | 0.1V | 0V | 0.4V | 0.8V | 0V | 3.2V | 0V | 6.4V | 12.3 | 10101101
174 | 0V | 0.2V | 0.4V | 0.8V | 0V | 3.2V | 0V | 6.4V | 12.4 | 10101110
175 | 0.1V | 0.2V | 0.4V | 0.8V | 0V | 3.2V | 0V | 6.4V | 12.5 | 10101111
176 | 0V | 0V | 0V | 0V | 1.6V | 3.2V | 0V | 6.4V | 12.6 | 10110000
177 | 0.1V | 0V | 0V | 0V | 1.6V | 3.2V | 0V | 6.4V | 12.7 | 10110001
178 | 0V | 0.2V | 0V | 0V | 1.6V | 3.2V | 0V | 6.4V | 12.8 | 10110010
179 | 0.1V | 0.2V | 0V | 0V | 1.6V | 3.2V | 0V | 6.4V | 12.9 | 10110011
180 | 0V | 0V | 0.4V | 0V | 1.6V | 3.2V | 0V | 6.4V | 13.0 | 10110100
181 | 0.1V | 0V | 0.4V | 0V | 1.6V | 3.2V | 0V | 6.4V | 13.1 | 10110101
182 | 0V | 0.2V | 0.4V | 0V | 1.6V | 3.2V | 0V | 6.4V | 13.2 | 10110110
183 | 0.1V | 0.2V | 0.4V | 0V | 1.6V | 3.2V | 0V | 6.4V | 13.3 | 10110111
184 | 0V | 0V | 0V | 0.8V | 1.6V | 3.2V | 0V | 6.4V | 13.4 | 10111000
185 | 0.1V | 0V | 0V | 0.8V | 1.6V | 3.2V | 0V | 6.4V | 13.5 | 10111001
186 | 0V | 0.2V | 0V | 0.8V | 1.6V | 3.2V | 0V | 6.4V | 13.6 | 10111010
187 | 0.1V | 0.2V | 0V | 0.8V | 1.6V | 3.2V | 0V | 6.4V | 13.7 | 10111011

188 | 0V | 0V | 0.4V | 0.8V | 1.6V | 3.2V | 0V | 6.4V | 13.8 | 10111100
189 | 0.1V | 0V | 0.4V | 0.8V | 1.6V | 3.2V | 0V | 6.4V | 13.9 | 10111101
190 | 0V | 0.2V | 0.4V | 0.8V | 1.6V | 3.2V | 0V | 6.4V | 14.0 | 10111110
191 | 0.1V | 0.2V | 0.4V | 0.8V | 1.6V | 3.2V | 0V | 6.4V | 14.1 | 10111111
192 | 0V | 0V | 0V | 0V | 0V | 0V | 6.4V | 6.4V | 14.2 | 11000000
193 | 0.1V | 0V | 0V | 0V | 0V | 0V | 6.4V | 6.4V | 14.3 | 11000001
194 | 0V | 0.2V | 0V | 0V | 0V | 0V | 6.4V | 6.4V | 14.4 | 11000010
195 | 0.1V | 0.2V | 0V | 0V | 0V | 0V | 6.4V | 6.4V | 14.5 | 11000011
196 | 0V | 0V | 0.4V | 0V | 0V | 0V | 6.4V | 6.4V | 14.6 | 11000100
197 | 0.1V | 0V | 0.4V | 0V | 0V | 0V | 6.4V | 6.4V | 14.7 | 11000101
198 | 0V | 0.2V | 0.4V | 0V | 0V | 0V | 6.4V | 6.4V | 14.8 | 11000110
199 | 0.1V | 0.2V | 0.4V | 0V | 0V | 0V | 6.4V | 6.4V | 14.9 | 11000111
200 | 0V | 0V | 0V | 0.8V | 0V | 0V | 6.4V | 6.4V | 15.0 | 11001000
201 | 0.1V | 0V | 0V | 0.8V | 0V | 0V | 6.4V | 6.4V | 15.1 | 11001001
202 | 0V | 0.2V | 0V | 0.8V | 0V | 0V | 6.4V | 6.4V | 15.2 | 11001010
203 | 0.1V | 0.2V | 0V | 0.8V | 0V | 0V | 6.4V | 6.4V | 15.3 | 11001011
204 | 0V | 0V | 0.4V | 0.8V | 0V | 0V | 6.4V | 6.4V | 15.4 | 11001100
205 | 0.1V | 0V | 0.4V | 0.8V | 0V | 0V | 6.4V | 6.4V | 15.5 | 11001101
206 | 0V | 0.2V | 0.4V | 0.8V | 0V | 0V | 6.4V | 6.4V | 15.6 | 11001110
207 | 0.1V | 0.2V | 0.4V | 0.8V | 0V | 0V | 6.4V | 6.4V | 15.7 | 11001111
208 | 0V | 0V | 0V | 0V | 1.6V | 0V | 6.4V | 6.4V | 15.8 | 11010000
209 | 0.1V | 0V | 0V | 0V | 1.6V | 0V | 6.4V | 6.4V | 15.9 | 11010001
210 | 0V | 0.2V | 0V | 0V | 1.6V | 0V | 6.4V | 6.4V | 16.0 | 11010010
211 | 0.1V | 0.2V | 0V | 0V | 1.6V | 0V | 6.4V | 6.4V | 16.1 | 11010011
212 | 0V | 0V | 0.4V | 0V | 1.6V | 0V | 6.4V | 6.4V | 16.2 | 11010100
213 | 0.1V | 0V | 0.4V | 0V | 1.6V | 0V | 6.4V | 6.4V | 16.3 | 11010101
214 | 0V | 0.2V | 0.4V | 0V | 1.6V | 0V | 6.4V | 6.4V | 16.4 | 11010110
215 | 0.1V | 0.2V | 0.4V | 0V | 1.6V | 0V | 6.4V | 6.4V | 16.5 | 11010111
216 | 0V | 0V | 0V | 0.8V | 1.6V | 0V | 6.4V | 6.4V | 16.6 | 11011000
217 | 0.1V | 0V | 0V | 0.8V | 1.6V | 0V | 6.4V | 6.4V | 16.7 | 11011001
218 | 0V | 0.2V | 0V | 0.8V | 1.6V | 0V | 6.4V | 6.4V | 16.8 | 11011010
219 | 0.1V | 0.2V | 0V | 0.8V | 1.6V | 0V | 6.4V | 6.4V | 16.9 | 11011011
220 | 0V | 0V | 0.4V | 0.8V | 1.6V | 0V | 6.4V | 6.4V | 17.0 | 11011100
221 | 0.1V | 0V | 0.4V | 0.8V | 1.6V | 0V | 6.4V | 6.4V | 17.1 | 11011101

222 | 0V | 0.2V | 0.4V | 0.8V | 1.6V | 0V | 6.4V | 6.4V | 17.2 | 11011110
223 | 0.1V | 0.2V | 0.4V | 0.8V | 1.6V | 0V | 6.4V | 6.4V | 17.3 | 11011111
224 | 0V | 0V | 0V | 0V | 0V | 3.2V | 6.4V | 6.4V | 17.4 | 11100000
225 | 0.1V | 0V | 0V | 0V | 0V | 3.2V | 6.4V | 6.4V | 17.5 | 11100001
226 | 0V | 0.2V | 0V | 0V | 0V | 3.2V | 6.4V | 6.4V | 17.6 | 11100010
227 | 0.1V | 0.2V | 0V | 0V | 0V | 3.2V | 6.4V | 6.4V | 17.7 | 11100011
228 | 0V | 0V | 0.4V | 0V | 0V | 3.2V | 6.4V | 6.4V | 17.8 | 11100100
229 | 0.1V | 0V | 0.4V | 0V | 0V | 3.2V | 6.4V | 6.4V | 17.9 | 11100101
230 | 0V | 0.2V | 0.4V | 0V | 0V | 3.2V | 6.4V | 6.4V | 18.0 | 11100110
231 | 0.1V | 0.2V | 0.4V | 0V | 0V | 3.2V | 6.4V | 6.4V | 18.1 | 11100111
232 | 0V | 0V | 0V | 0.8V | 0V | 3.2V | 6.4V | 6.4V | 18.2 | 11101000
233 | 0.1V | 0V | 0V | 0.8V | 0V | 3.2V | 6.4V | 6.4V | 18.3 | 11101001
234 | 0V | 0.2V | 0V | 0.8V | 0V | 3.2V | 6.4V | 6.4V | 18.4 | 11101010
235 | 0.1V | 0.2V | 0V | 0.8V | 0V | 3.2V | 6.4V | 6.4V | 18.5 | 11101011
236 | 0V | 0V | 0.4V | 0.8V | 0V | 3.2V | 6.4V | 6.4V | 18.6 | 11101100
237 | 0.1V | 0V | 0.4V | 0.8V | 0V | 3.2V | 6.4V | 6.4V | 18.7 | 11101101
238 | 0V | 0.2V | 0.4V | 0.8V | 0V | 3.2V | 6.4V | 6.4V | 18.8 | 11101110
239 | 0.1V | 0.2V | 0.4V | 0.8V | 0V | 3.2V | 6.4V | 6.4V | 18.9 | 11101111
240 | 0V | 0V | 0V | 0V | 1.6V | 3.2V | 6.4V | 6.4V | 19.0 | 11110000
241 | 0.1V | 0V | 0V | 0V | 1.6V | 3.2V | 6.4V | 6.4V | 19.1 | 11110001
242 | 0V | 0.2V | 0V | 0V | 1.6V | 3.2V | 6.4V | 6.4V | 19.2 | 11110010
243 | 0.1V | 0.2V | 0V | 0V | 1.6V | 3.2V | 6.4V | 6.4V | 19.3 | 11110011
244 | 0V | 0V | 0.4V | 0V | 1.6V | 3.2V | 6.4V | 6.4V | 19.4 | 11110100
245 | 0.1V | 0V | 0.4V | 0V | 1.6V | 3.2V | 6.4V | 6.4V | 19.5 | 11110101
246 | 0V | 0.2V | 0.4V | 0V | 1.6V | 3.2V | 6.4V | 6.4V | 19.6 | 11110110
247 | 0.1V | 0.2V | 0.4V | 0V | 1.6V | 3.2V | 6.4V | 6.4V | 19.7 | 11110111
248 | 0V | 0V | 0V | 0.8V | 1.6V | 3.2V | 6.4V | 6.4V | 19.8 | 11111000
249 | 0.1V | 0V | 0V | 0.8V | 1.6V | 3.2V | 6.4V | 6.4V | 19.9 | 11111001
250 | 0V | 0.2V | 0V | 0.8V | 1.6V | 3.2V | 6.4V | 6.4V | 20.0 | 11111010
251 | 0.1V | 0.2V | 0V | 0.8V | 1.6V | 3.2V | 6.4V | 6.4V | 20.1 | 11111011
252 | 0V | 0V | 0.4V | 0.8V | 1.6V | 3.2V | 6.4V | 6.4V | 20.2 | 11111100
253 | 0.1V | 0V | 0.4V | 0.8V | 1.6V | 3.2V | 6.4V | 6.4V | 20.3 | 11111101
254 | 0V | 0.2V | 0.4V | 0.8V | 1.6V | 3.2V | 6.4V | 6.4V | 20.4 | 11111110
255 | 0.1V | 0.2V | 0.4V | 0.8V | 1.6V | 3.2V | 6.4V | 6.4V | 20.5 | 11111111

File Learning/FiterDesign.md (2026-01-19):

<div align=center><h1>滤波器设计手册</h1></div>

> 

[TOC]

***

# 复变函数基础

## 1. 复数的定义和基础运算

### 1.1 复数的定义
复数是一个可以表示为 $a + bi$ 形式的数，其中 $a$ 和 $b$ 是实数，$i$ 是虚数单位，满足 $i^2 = -1$。

这里 $a$ 称为复数的实部，记作 $\text{Re}(z)$；$b$ 称为复数的虚部，记作 $\text{Im}(z)$。

### 1.2 复数的基础运算

#### 1.2.1 加法和减法
对于两个复数 $z_1 = a + bi$ 和 $z_2 = c + di$：
$$
\begin{align*}
\text{加法：} & z_1 + z_2 = (a + c) + (b + d)i \\
\text{减法：} & z_1 - z_2 = (a - c) + (b - d)i
\end{align*}
$$

#### 1.2.2 乘法
$$
\begin{align*}
z_1 \cdot z_2 &= (a + bi)(c + di) \\
&= ac + adi + bci + bdi^2 \\
&= (ac - bd) + (ad + bc)i
\end{align*}
$$

#### 1.2.3 除法

$$
\frac{z_1}{z_2} = \frac{a + bi}{c + di} = \frac{(a + bi)(c - di)}{(c + di)(c - di)} = \frac{(ac + bd) + (bc - ad)i}{c^2 + d^2}
$$

#### 1.2.4 共轭复数
复数 $z = a + bi$ 的共轭复数定义为 $\bar{z} = a - bi$。共轭运算具有以下性质：
1. $\overline{z_1 + z_2} = \bar{z_1} + \bar{z_2}$
2. $\overline{z_1 \cdot z_2} = \bar{z_1} \cdot \bar{z_2}$
3. $\overline{\left(\frac{z_1}{z_2}\right)} = \frac{\bar{z_1}}{\bar{z_2}}$
4. $z \cdot \bar{z} = |z|^2 = a^2 + b^2$

#### 1.2.5 复数的模
复数 $z = a + bi$ 的模定义为 $|z| = \sqrt{a^2 + b^2}$。模运算具有以下性质：
1. $|z_1 \cdot z_2| = |z_1| \cdot |z_2|$
2. $\left|\frac{z_1}{z_2}\right| = \frac{|z_1|}{|z_2|}$
3. $|z_1 + z_2| \leq |z_1| + |z_2|$（三角不等式）
4. $|z_1 - z_2| \geq ||z_1| - |z_2||$

## 2. 复平面和欧拉公式

### 2.1 复平面
复平面（也称为高斯平面或Argand平面）是一个二维平面，其中横坐标表示复数的实部，纵坐标表示复数的虚部。复数 $z = a + bi$ 在复平面上对应于点 $(a, b)$。

在复平面上，复数还可以用极坐标形式表示：

$$
z = r(\cos\theta + i\sin\theta)
$$

其中：
- $r = |z| = \sqrt{a^2 + b^2}$ 是模
- $\theta = \arg(z) = \arctan\left(\frac{b}{a}\right)$ 是辐角（需要考虑象限）

### 2.2 欧拉公式
欧拉公式建立了复数指数函数与三角函数之间的关系：

$$
e^{i\theta} = \cos\theta + i\sin\theta
$$

由此，复数可以表示为指数形式：

$$
z = re^{i\theta}
$$

#### 2.2.1 欧拉公式的推导
使用泰勒级数展开：

$$
e^x = 1 + x + \frac{x^2}{2!} + \frac{x^3}{3!} + \frac{x^4}{4!} + \cdots
$$

$$
\cos x = 1 - \frac{x^2}{2!} + \frac{x^4}{4!} - \frac{x^6}{6!} + \cdots
$$

$$
\sin x = x - \frac{x^3}{3!} + \frac{x^5}{5!} - \frac{x^7}{7!} + \cdots
$$

将 $x = i\theta$ 代入 $e^x$：

$$
e^{i\theta} = 1 + i\theta + \frac{(i\theta)^2}{2!} + \frac{(i\theta)^3}{3!} + \frac{(i\theta)^4}{4!} + \cdots
$$

$$
= 1 + i\theta - \frac{\theta^2}{2!} - i\frac{\theta^3}{3!} + \frac{\theta^4}{4!} + i\frac{\theta^5}{5!} - \cdots
$$

$$
= \left(1 - \frac{\theta^2}{2!} + \frac{\theta^4}{4!} - \cdots\right) + i\left(\theta - \frac{\theta^3}{3!} + \frac{\theta^5}{5!} - \cdots\right)
$$

$$
= \cos\theta + i\sin\theta
$$

#### 2.2.2 欧拉公式的重要推论
1. 欧拉恒等式：当 $\theta = \pi$ 时，$e^{i\pi} + 1 = 0$
2. 三角函数与指数函数的关系：

$$
\cos\theta = \frac{e^{i\theta} + e^{-i\theta}}{2}, \quad \sin\theta = \frac{e^{i\theta} - e^{-i\theta}}{2i}
$$

3. 复数的乘除运算简化：

$$
z_1 \cdot z_2 = r_1 r_2 e^{i(\theta_1 + \theta_2)}
$$

$$
\frac{z_1}{z_2} = \frac{r_1}{r_2} e^{i(\theta_1 - \theta_2)}
$$

$$
z^n = r^n e^{in\theta} \quad (\text{棣莫弗公式})
$$

## 3. 复变函数及其零点与极点

### 3.1 复变函数的定义
复变函数是从复数域到复数域的映射：
$$
f: D \subseteq \mathbb{C} \to \mathbb{C}
$$
其中 $D$ 是定义域。复变函数可以表示为 $w = f(z)$，其中 $z, w \in \mathbb{C}$。

在滤波器设计中，最常用的是有理函数形式的复变函数：

$$
H(s) = \frac{N(s)}{D(s)} = \frac{b_m s^m + b_{m-1} s^{m-1} + \cdots + b_0}{a_n s^n + a_{n-1} s^{n-1} + \cdots + a_0}
$$

其中 $s$ 是复频率变量，$N(s)$ 和 $D(s)$ 是多项式。

### 3.2 零点
#### 3.2.1 零点的定义
如果 $f(z_0) = 0$，则 $z_0$ 是函数 $f(z)$ 的零点。对于有理函数 $H(s) = \frac{N(s)}{D(s)}$，零点 $s_0$ 满足 $N(s_0) = 0$。

#### 3.2.2 零点的阶数
如果 $f(z)$ 在 $z_0$ 处可以表示为：

$$
f(z) = (z - z_0)^k g(z)
$$

其中 $g(z_0) \neq 0$，则 $z_0$ 是 $f(z)$ 的 $k$ 阶零点。

### 3.3 极点
#### 3.3.1 极点的定义
如果 $f(z)$ 在 $z_0$ 处无定义，且 $\lim_{z \to z_0} |f(z)| = \infty$，则 $z_0$ 是函数 $f(z)$ 的极点。对于有理函数 $H(s) = \frac{N(s)}{D(s)}$，极点 $s_p$ 满足 $D(s_p) = 0$。

#### 3.3.2 极点的阶数
如果 $f(z)$ 在 $z_p$ 处可以表示为：

$$
f(z) = \frac{h(z)}{(z - z_p)^k}
$$

其中 $h(z_p) \neq 0$，则 $z_p$ 是 $f(z)$ 的 $k$ 阶极点。

## 4. 留数及其计算

### 4.1 留数的定义
设 $f(z)$ 在点 $z_0$ 的邻域内除 $z_0$ 外解析，且在 $z_0$ 处有孤立奇点，则 $f(z)$ 在 $z_0$ 处的留数定义为：

$$
\text{Res}(f, z_0) = \frac{1}{2\pi i} \oint_{C} f(z) dz
$$

其中 $C$ 是以 $z_0$ 为中心、半径充分小的正向圆周。

### 4.2 留数的计算

#### 4.2.1 一阶极点
如果 $z_0$ 是 $f(z)$ 的一阶极点，则：

$$
\text{Res}(f, z_0) = \lim_{z \to z_0} (z - z_0) f(z)
$$

#### 4.2.2 $k$ 阶极点
如果 $z_0$ 是 $f(z)$ 的 $k$ 阶极点，则：

$$
\text{Res}(f, z_0) = \frac{1}{(k-1)!} \lim_{z \to z_0} \frac{d^{k-1}}{dz^{k-1}} [(z - z_0)^k f(z)]
$$

#### 4.2.3 有理函数的留数
对于有理函数 $f(z) = \frac{P(z)}{Q(z)}$，如果 $z_0$ 是 $Q(z)$ 的一阶零点且 $P(z_0) \neq 0$，则：

$$
\text{Res}(f, z_0) = \frac{P(z_0)}{Q'(z_0)}
$$

### 4.3 留数定理

#### 4.3.1 留数定理的表述
设 $f(z)$ 在区域 $D$ 内除有限个孤立奇点 $z_1, z_2, \ldots, z_n$ 外处处解析，$C$ 是 $D$ 内一条正向简单闭曲线，且 $z_1, z_2, \ldots, z_n$ 都在 $C$ 的内部，则：

$$
\oint_{C} f(z) dz = 2\pi i \sum_{k=1}^n \text{Res}(f, z_k)
$$

#### 4.3.2 留数定理的应用
留数定理在计算实积分和滤波器设计中非常有用。例如，在计算某些类型的无穷积分时：

$$
\int_{-\infty}^{\infty} f(x) dx = 2\pi i \sum_{\text{上半平面极点}} \text{Res}(f, z_k)
$$

## 5. 共形映射

### 5.1 共形映射的定义
设 $f(z)$ 在区域 $D$ 内解析，且 $f'(z) \neq 0$，则称 $f: D \to \mathbb{C}$ 是一个共形映射。共形映射具有以下性质：
1. **保角性**：映射保持两条曲线在交点处的夹角大小和方向
2. **伸缩率不变性**：在任意点 $z_0$，映射的伸缩率 $|f'(z_0)|$ 与方向无关

### 5.2 常见的共形映射

#### 5.2.1 线性变换

$$
w = az + b, \quad a \neq 0
$$

这是一个旋转、缩放和平移的组合。

#### 5.2.2 分式线性变换（莫比乌斯变换）

$$
w = \frac{az + b}{cz + d}, \quad ad - bc \neq 0
$$

分式线性变换将圆或直线映射为圆或直线。

#### 5.2.3 指数函数

$$
w = e^z
$$

将水平带形区域映射为角形区域。

#### 5.2.4 对数函数

$$
w = \ln z
$$

是指数函数的逆映射。

#### 5.2.5 共形映射的性质
1. **保角性**：保持角度大小和方向
2. **保域性**：将区域映射为区域
3. **边界对应原理**：区域的边界映射为像区域的边界
4. **黎曼映射定理**：任何单连通区域（除了整个复平面）都可以共形映射到单位圆内部

# 信号与系统

## 1、连续信号与离散信号理论

### 1.1 连续信号数学定义与分类

连续信号在数学上定义为定义在连续时间域上的函数，其时间变量 $t$ 在实数域 $\mathbb{R}$ 上连续取值：

$$
x(t): \mathbb{R} \rightarrow \mathbb{C} \quad \text{或} \quad \mathbb{R}
$$

#### 连续信号的分类

1. **确定性信号与随机信号**
   - 确定性信号：完全由确定数学表达式描述
     $$
     x(t) = A\cos(2\pi f_0 t + \phi)
     $$
   - 随机信号：统计特性已知，具体实现不确定

2. **能量信号与功率信号**
   - 能量信号：总能量有限
     $$
     E = \int_{-\infty}^{\infty} |x(t)|^2 dt \lt \infty
     $$
   - 功率信号：平均功率有限
     $$
     P = \lim_{T\to\infty} \frac{1}{T} \int_{-T/2}^{T/2} |x(t)|^2 dt \lt \infty
     $$

3. **周期信号与非周期信号**
   - 周期信号：存在最小正周期 $T_0$
     $$
     x(t + T_0) = x(t), \quad \forall t \in \mathbb{R}
     $$
   - 非周期信号：不存在这样的 $T_0$

#### 典型连续信号

*单位冲激函数：*
$$
\delta(t) = 
\begin{cases}
\infty, & t=0 \\
0, & t \neq 0
\end{cases}
\quad \text{且} \quad \int_{-\infty}^{\infty} \delta(t) dt = 1
$$

*单位阶跃函数：*
$$
u(t) = 
\begin{cases}
1, & t \geq 0 \\
0, & t &lt; 0
\end{cases}
$$

*矩形脉冲：*
$$
\text{rect}\left(\frac{t}{T}\right) = 
\begin{cases}
1, & |t| \leq T/2 \\
0, & |t| \gt T/2
\end{cases}
$$

### 1.2 离散信号数学定义与性质

离散信号在数学上定义为定义在整数时间点上的序列：

$$
x[n]: \mathbb{Z} \rightarrow \mathbb{C} \quad \text{或} \quad \mathbb{R}, \quad n \in \mathbb{Z}
$$

#### 离散信号的运算

1. **移位运算**
   $$
   y[n] = x[n - n_0]
   $$

2. **反褶运算**
   $$
   y[n] = x[-n]
   $$

3. **尺度变换**
   $$
   y[n] = x[an], \quad a \in \mathbb{Z}^+
   $$

#### 典型离散信号

*单位样本序列：*
$$
\delta[n] = 
\begin{cases}
1, & n = 0 \\
0, & n \neq 0
\end{cases}
$$

*单位阶跃序列：*
$$
u[n] = 
\begin{cases}
1, & n \geq 0 \\
0, & n &lt; 0
\end{cases}
$$

*矩形序列：*
$$
R_N[n] = 
\begin{cases}
1, & 0 \leq n \leq N-1 \\
0, & \text{其他}
\end{cases}
$$

### 1.3 连续到离散的转换：采样理论

#### 理想采样模型

理想采样过程可建模为连续信号与冲激串的乘积：

$$
x_s(t) = x(t) \cdot s(t) = x(t) \cdot \sum_{n=-\infty}^{\infty} \delta(t - nT_s)
$$

其中 $T_s$ 为采样周期，$f_s = 1/T_s$ 为采样频率。

#### 采样过程的频域分析

对采样模型取傅里叶变换：

$$
\begin{align*}
X_s(f) &= \mathcal{F}\{x(t) \cdot s(t)\} \\
&= X(f) * S(f) \\
&= X(f) * \left[ f_s \sum_{k=-\infty}^{\infty} \delta(f - kf_s) \right] \\
&= f_s \sum_{k=-\infty}^{\infty} X(f - kf_s)
\end{align*}
$$

这表明采样信号的频谱是原信号频谱的周期性延拓，周期为 $f_s$。

#### 奈奎斯特采样定理的严格证明

**定理：** 设连续信号 $x(t)$ 的最高频率分量为 $f_m$，则当采样频率 $f_s \gt 2f_m$ 时，可以从采样信号 $x_s(t)$ 中无失真地恢复原信号。

**证明：** 考虑采样信号的频域表达式，当 $f_s \gt 2f_m$ 时，频谱的周期延拓不会重叠。通过理想低通滤波器：
$$
H(f) = T_s \cdot \text{rect}\left(\frac{f}{f_s}\right) = 
\begin{cases}
T_s, & |f| &lt; f_s/2 \\
0, & |f| \geq f_s/2
\end{cases}
$$

滤波输出：

$$
\begin{align*}
Y(f) &= X_s(f) \cdot H(f) \\
&= f_s \sum_{k=-\infty}^{\infty} X(f - kf_s) \cdot H(f) \\
&= X(f) \quad \text{(由于 $H(f)$ 只保留中心周期)}
\end{align*}
$$

时域恢复公式：

$$
\begin{align*}
y(t) &= x_s(t) * h(t) \\
&= \left[ \sum_{n=-\infty}^{\infty} x(nT_s)\delta(t-nT_s) \right] * \left[ \frac{\sin(\pi f_s t)}{\pi f_s t} \right] \\
&= \sum_{n=-\infty}^{\infty} x(nT_s) \frac{\sin[\pi f_s (t-nT_s)]}{\pi f_s (t-nT_s)} \\
&= \sum_{n=-\infty}^{\infty} x(nT_s) \text{sinc}[f_s(t-nT_s)]
\end{align*}
$$

### 1.4 离散到连续的转换：信号重建

#### 理想重建

如上述公式所示，理想重建使用 sinc 函数进行插值。

#### 实际重建方法

1. **零阶保持（Zero-Order Hold）**
   $$
   x_{\text{ZOH}}(t) = \sum_{n=-\infty}^{\infty} x[n] \cdot \text{rect}\left(\frac{t-nT_s - T_s/2}{T_s}\right)
   $$

2. **一阶保持（First-Order Hold）**
   $$
   x_{\text{FOH}}(t) = \sum_{n=-\infty}^{\infty} \left[ x[n] + \frac{x[n+1]-x[n]}{T_s}(t-nT_s) \right] \cdot \text{rect}\left(\frac{t-nT_s}{T_s}\right)
   $$
## 2、卷积、系统函数与脉冲响应

### 2.1 卷积的数学定义与性质

#### 连续卷积

对于两个连续信号 $x(t)$ 和 $h(t)$，其卷积定义为：

$$
y(t) = (x * h)(t) = \int_{-\infty}^{\infty} x(\tau)h(t-\tau) d\tau
$$

**卷积性质：**

1. **交换律：** $x(t) * h(t) = h(t) * x(t)$
2. **结合律：** $[x(t) * h_1(t)] * h_2(t) = x(t) * [h_1(t) * h_2(t)]$
3. **分配律：** $x(t) * [h_1(t) + h_2(t)] = x(t) * h_1(t) + x(t) * h_2(t)$
4. **平移特性：** 若 $y(t) = x(t) * h(t)$，则 $x(t-t_0) * h(t) = y(t-t_0)$
5. **微分特性：** $\frac{d}{dt}[x(t) * h(t)] = \frac{dx(t)}{dt} * h(t) = x(t) * \frac{dh(t)}{dt}$
6. **积分特性：** $\int_{-\infty}^{t} [x(\tau) * h(\tau)] d\tau = \left[\int_{-\infty}^{t} x(\tau) d\tau\right] * h(t)$

#### 离散卷积

对于两个离散序列 $x[n]$ 和 $h[n]$，其卷积定义为：

$$
y[n] = (x * h)[n] = \sum_{k=-\infty}^{\infty} x[k]h[n-k]
$$

**卷积计算示例：** 设 $x[n] = \{1, 2, 3\}$，$h[n] = \{1, 1, 1\}$，则

$$
\begin{align*}
y[0] &= x[0]h[0] = 1 \\
y[1] &= x[0]h[1] + x[1]h[0] = 1 + 2 = 3 \\
y[2] &= x[0]h[2] + x[1]h[1] + x[2]h[0] = 1 + 2 + 3 = 6 \\
y[3] &= x[1]h[2] + x[2]h[1] = 2 + 3 = 5 \\
y[4] &= x[2]h[2] = 3
\end{align*}
$$

故 $y[n] = \{1, 3, 6, 5, 3\}$。

### 2.2 脉冲响应的物理意义

#### 连续系统脉冲响应

对于连续时间线性时不变系统，脉冲响应 $h(t)$ 定义为系统对单位冲激函数 $\delta(t)$ 的响应：

$$
h(t) = T\{\delta(t)\}
$$

#### 离散系统脉冲响应

对于离散时间线性时不变系统，脉冲响应 $h[n]$ 定义为系统对单位样本序列 $\delta[n]$ 的响应：

$$
h[n] = T\{\delta[n]\}
$$

#### 脉冲响应的物理意义

脉冲响应完全表征了LTI系统的时域特性。任何输入信号 $x(t)$（或 $x[n]$）的输出可以通过输入与脉冲响应的卷积得到：

$$
y(t) = x(t) * h(t) \quad \text{或} \quad y[n] = x[n] * h[n]
$$

### 2.3 系统函数的定义与性质

#### 连续系统系统函数

连续时间LTI系统的系统函数 $H(s)$ 定义为脉冲响应 $h(t)$ 的拉普拉斯变换：

$$
H(s) = \mathcal{L}\{h(t)\} = \int_{-\infty}^{\infty} h(t)e^{-st} dt, \quad s = \sigma + j\omega
$$

当 $s = j\omega$ 时，得到系统的频率响应：

$$
H(j\omega) = \mathcal{F}\{h(t)\} = \int_{-\infty}^{\infty} h(t)e^{-j\omega t} dt
$$

#### 离散系统系统函数

离散时间LTI系统的系统函数 $H(z)$ 定义为脉冲响应 $h[n]$ 的Z变换：

$$
H(z) = \mathcal{Z}\{h[n]\} = \sum_{n=-\infty}^{\infty} h[n]z^{-n}
$$

当 $z = e^{j\omega}$ 时，得到系统的频率响应：

$$
H(e^{j\omega}) = \mathcal{DTFT}\{h[n]\} = \sum_{n=-\infty}^{\infty} h[n]e^{-j\omega n}
$$

#### 系统函数的极零点分析

系统函数通常可表示为有理分式形式：

$$
H(z) = \frac{\sum_{k=0}^{M} b_k z^{-k}}{\sum_{k=0}^{N} a_k z^{-k}} = K \frac{\prod_{k=1}^{M} (1 - z_k z^{-1})}{\prod_{k=1}^{N} (1 - p_k z^{-1})}
$$

其中 $z_k$ 为零点，$p_k$ 为极点，$K$ 为增益常数。

### 2.4 系统稳定性与因果性判据

#### 连续系统

1. **稳定性：** 系统稳定当且仅当 $\int_{-\infty}^{\infty} |h(t)| dt \lt \infty$
2. **因果性：** 系统因果当且仅当 $h(t) = 0$，对于所有 $t \lt 0$
3. **频率域判据：** 稳定系统 $H(s)$ 的所有极点必须位于S平面的左半平面

#### 离散系统

1. **稳定性：** 系统稳定当且仅当 $\sum_{n=-\infty}^{\infty} |h[n]| \lt \infty$
2. **因果性：** 系统因果当且仅当 $h[n] = 0$，对于所有 $n \lt 0$
3. **频率域判据：** 稳定系统 $H(z)$ 的所有极点必须位于Z平面的单位圆内

## 3、线性时不变系统理论

### 3.1 线性系统的数学定义

设 $T\{\cdot\}$ 表示系统算子，对于任意输入信号 $x_1(t)$ 和 $x_2(t)$，以及任意常数 $a$ 和 $b$，系统满足：

$$
T\{a x_1(t) + b x_2(t)\} = a T\{x_1(t)\} + b T\{x_2(t)\}
$$

#### 线性性的验证示例

考虑系统 $y(t) = 2x(t) + 3$，测试其线性性：

$$
\begin{align*}
T\{a x_1(t) + b x_2(t)\} &= 2[a x_1(t) + b x_2(t)] + 3 \\
&= 2a x_1(t) + 2b x_2(t) + 3 \\
a T\{x_1(t)\} + b T\{x_2(t)\} &= a[2x_1(t) + 3] + b[2x_2(t) + 3] \\
&= 2a x_1(t) + 2b x_2(t) + 3(a+b)
\end{align*}
$$

由于 $3 \neq 3(a+b)$（除非 $a+b=1$），故系统非线性。

### 3.2 时不变系统的数学定义

系统满足时不变性，如果对于任意输入 $x(t)$ 和任意时移 $t_0$，有：

$$
\text{若 } y(t) = T\{x(t)\}，则 T\{x(t-t_0)\} = y(t-t_0)
$$

#### 时不变性验证示例

考虑系统 $y(t) = x(2t)$，测试其时不变性：

$$
\begin{align*}
T\{x(t-t_0)\} &= x(2t - t_0) \\
y(t-t_0) &= x(2(t-t_0)) = x(2t - 2t_0)
\end{align*}
$$

由于 $x(2t-t_0) \neq x(2t-2t_0)$，故系统时变。

### 3.3 LTI系统的特征函数与特征值

对于连续时间LTI系统，复指数函数 $e^{st}$ 是特征函数：

$$
T\{e^{st}\} = H(s)e^{st}
$$

其中 $H(s)$ 是对应的特征值，即系统函数。

对于离散时间LTI系统，复指数序列 $z^n$ 是特征函数：

$$
T\{z^n\} = H(z)z^n
$$

### 3.4 LTI系统的微分/差分方程描述

#### 连续系统微分方程

连续时间LTI系统可由常系数线性微分方程描述：

$$
\sum_{k=0}^{N} a_k \frac{d^k y(t)}{dt^k} = \sum_{k=0}^{M} b_k \frac{d^k x(t)}{dt^k}
$$

对两边取拉普拉斯变换（零初始条件）：

$$
\sum_{k=0}^{N} a_k s^k Y(s) = \sum_{k=0}^{M} b_k s^k X(s)
$$

得到系统函数：

$$
H(s) = \frac{Y(s)}{X(s)} = \frac{\sum_{k=0}^{M} b_k s^k}{\sum_{k=0}^{N} a_k s^k}
$$

#### 离散系统差分方程

离散时间LTI系统可由常系数线性差分方程描述：

$$
\sum_{k=0}^{N} a_k y[n-k] = \sum_{k=0}^{M} b_k x[n-k]
$$

对两边取Z变换（零初始条件）：

$$
\sum_{k=0}^{N} a_k z^{-k} Y(z) = \sum_{k=0}^{M} b_k z^{-k} X(z)
$$

得到系统函数：

$$
H(z) = \frac{Y(z)}{X(z)} = \frac{\sum_{k=0}^{M} b_k z^{-k}}{\sum_{k=0}^{N} a_k z^{-k}}
$$

## 4、信号变换域分析

### 4.1 傅里叶变换理论

#### 连续时间傅里叶变换（CTFT）

对于连续时间信号 $x(t)$，其傅里叶变换定义为：

$$
X(\omega) = \int_{-\infty}^{\infty} x(t)e^{-j\omega t} dt
$$

逆变换为：

$$
x(t) = \frac{1}{2\pi} \int_{-\infty}^{\infty} X(\omega)e^{j\omega t} d\omega
$$

#### 傅里叶变换的性质

| 性质 | 时域 | 频域 |
|---|---|---|
| 线性性 | $ax_1(t) + bx_2(t)$ | $aX_1(\omega) + bX_2(\omega)$ |
| 时移 | $x(t - t_0)$ | $e^{-j\omega t_0}X(\omega)$ |
| 频移 | $e^{j\omega_0 t}x(t)$ | $X(\omega - \omega_0)$ |
| 时间尺度 | $x(at)$ | $\frac{1}{|a|}X\left(\frac{\omega}{a}\right)$ |
| 微分 | $\frac{d^n x(t)}{dt^n}$ | $(j\omega)^n X(\omega)$ |
| 积分 | $\int_{-\infty}^t x(\tau)d\tau$ | $\frac{1}{j\omega}X(\omega) + \pi X(0)\delta(\omega)$ |
| 卷积 | $x(t) * h(t)$ | $X(\omega)H(\omega)$ |
| 乘积 | $x(t)h(t)$ | $\frac{1}{2\pi}X(\omega) * H(\omega)$ |

#### 常用信号的傅里叶变换

| 时域信号 | 频域表示 |
|---|---|
| 矩形脉冲 $\text{rect}\left(\frac{t}{T}\right)$ | $T \cdot \text{sinc}\left(\frac{\omega T}{2}\right) = \frac{2\sin(\omega T/2)}{\omega}$ |
| 冲激函数 $\delta(t)$ | 1 |
| 阶跃函数 $u(t)$ | $\frac{1}{j\omega} + \pi\delta(\omega)$ |
| 高斯脉冲 $e^{-at^2}$ | $\sqrt{\frac{\pi}{a}} e^{-\omega^2/(4a)}$ |

### 4.2 拉普拉斯变换理论

#### 双边拉普拉斯变换

对于连续时间信号 $x(t)$，其双边拉普拉斯变换定义为：

$$
X(s) = \int_{-\infty}^{\infty} x(t)e^{-st} dt, \quad s = \sigma + j\omega
$$

收敛域（ROC）是使积分收敛的所有 $s$ 的集合。

#### 单边拉普拉斯变换

对于因果信号，常用单边拉普拉斯变换：

$$
X(s) = \int_{0^-}^{\infty} x(t)e^{-st} dt
$$

#### 拉普拉斯变换性质

| 性质 | 时域 $x(t)$ | $s$域 $X(s)$ |
|---|---|---|
| 线性性 | $a_1x_1(t)+a_2x_2(t)$ | $a_1X_1(s)+a_2X_2(s)$ |
| 时移 | $x(t-t_0)u(t-t_0)$ | $e^{-st_0}X(s)$ |
| $s$域平移 | $e^{s_0t}x(t)$ | $X(s-s_0)$ |
| 尺度变换 | $x(at)$ | $\frac{1}{a}X\left(\frac{s}{a}\right)$ |
| 微分 | $\frac{dx(t)}{dt}$ | $sX(s) - x(0^-)$ |
| 积分 | $\int_0^t x(\tau)d\tau$ | $\frac{1}{s}X(s)$ |
| 卷积 | $x(t)*h(t)$ | $X(s)H(s)$ |
| 初值定理 | $\lim_{t\to0^+} x(t)$ | $\lim_{s\to\infty} sX(s)$ |
| 终值定理 | $\lim_{t\to\infty} x(t)$ | $\lim_{s\to0} sX(s)$ |

### 4.3 Z变换理论

#### 双边Z变换

对于离散时间信号 $x[n]$，其双边Z变换定义为：

$$
X(z) = \sum_{n=-\infty}^{\infty} x[n]z^{-n}
$$

收敛域（ROC）是使级数收敛的所有 $z$ 的集合。

#### 单边Z变换

对于因果序列，常用单边Z变换：

$$
X(z) = \sum_{n=0}^{\infty} x[n]z^{-n}
$$

#### Z变换性质

| 性质 | 时域 $x[n]$ | Z域 $X(z)$ |
|---|---|---|
| 线性性 | $a_1x_1[n]+a_2x_2[n]$ | $a_1X_1(z)+a_2X_2(z)$ |
| 时移 | $x[n-n_0]$ | $z^{-n_0}X(z) + \sum_{k=1}^{n_0}x[-k]z^{k-n_0}$ |
| Z域尺度 | $a^n x[n]$ | $X\left(\frac{z}{a}\right)$ |
| 时间翻转 | $x[-n]$ | $X\left(\frac{1}{z}\right)$ |
| 卷积 | $x[n] * h[n]$ | $X(z)H(z)$ |
| 微分 | $nx[n]$ | $-z\frac{dX(z)}{dz}$ |
| 初值定理 | $x[0]$ | $\lim_{z\to\infty} X(z)$ |
| 终值定理 | $\lim_{n\to\infty} x[n]$ | $\lim_{z\to1} (z-1)X(z)$ |

#### 常用Z变换对

$\delta[n] \leftrightarrow 1, \quad \text{ROC: 全平面}$

$u[n] \leftrightarrow \frac{1}{1-z^{-1}}, \quad \text{ROC: } |z| \gt 1$

$a^n u[n] \leftrightarrow \frac{1}{1-az^{-1}}, \quad \text{ROC: } |z| \gt |a|$

$n a^n u[n] \leftrightarrow \frac{az^{-1}}{(1-az^{-1})^2}, \quad \text{ROC: } |z| \gt |a|$

$\cos(\omega_0 n) u[n] \leftrightarrow \frac{1 - z^{-1}\cos\omega_0}{1 - 2z^{-1}\cos\omega_0 + z^{-2}}, \quad \text{ROC: } |z| \gt 1$

### 4.4 离散时间傅里叶变换（DTFT）

对于离散时间信号 $x[n]$，其DTFT定义为：

$$
X(e^{j\omega}) = \sum_{n=-\infty}^{\infty} x[n]e^{-j\omega n}
$$

DTFT是周期为 $2\pi$ 的连续函数。

#### DTFT性质

1. **周期性：** $X(e^{j(\omega+2\pi)}) = X(e^{j\omega})$
2. **线性性：** $ax_1[n] + bx_2[n] \leftrightarrow aX_1(e^{j\omega}) + bX_2(e^{j\omega})$
3. **时移：** $x[n-n_0] \leftrightarrow e^{-j\omega n_0}X(e^{j\omega})$
4. **频移：** $e^{j\omega_0 n}x[n] \leftrightarrow X(e^{j(\omega-\omega_0)})$
5. **卷积：** $x[n]*h[n] \leftrightarrow X(e^{j\omega})H(e^{j\omega})$

### 4.5 离散傅里叶变换（DFT）

对于有限长序列 $x[n]$，$n=0,1,\dots,N-1$，其DFT定义为：

$$
X[k] = \sum_{n=0}^{N-1} x[n] e^{-j\frac{2\pi}{N}kn}, \quad k=0,1,\dots,N-1
$$

逆变换（IDFT）为：

$$
x[n] = \frac{1}{N} \sum_{k=0}^{N-1} X[k] e^{j\frac{2\pi}{N}kn}, \quad n=0,1,\dots,N-1
$$

#### DFT与DTFT的关系

DFT是DTFT在频域的均匀采样：

$$
X[k] = X(e^{j\omega}) \big|_{\omega = \frac{2\pi k}{N}}
$$

#### DFT性质

1. **线性性：** $ax_1[n] + bx_2[n] \leftrightarrow aX_1[k] + bX_2[k]$
2. **循环移位：** $x[(n-m)_N] \leftrightarrow e^{-j\frac{2\pi}{N}km}X[k]$
3. **循环卷积：** $x[n] \circledast_N h[n] \leftrightarrow X[k]H[k]$
4. **对称性：** 对于实序列 $x[n]$，$X[k] = X^*[N-k]$

## 5、快速傅里叶变换（FFT）算法与实现

### 5.1 FFT算法的数学基础

#### DFT计算复杂度分析

直接计算N点DFT需要：
- 复数乘法：$N^2$ 次
- 复数加法：$N(N-1)$ 次

#### 旋转因子性质

定义旋转因子 $W_N = e^{-j\frac{2\pi}{N}}$，具有以下性质：

$$
\begin{align*}
W_N^{kn} &= e^{-j\frac{2\pi}{N}kn} \\
W_N^{k(n+N)} &= W_N^{kn} \\
W_N^{(k+N)n} &= W_N^{kn} \\
W_N^{N/2} &= -1 \\
W_N^{k+N/2} &= -W_N^k
\end{align*}
$$

### 5.2 基2-FFT算法推导

#### 时域抽取法（DIT-FFT）

将N点序列按奇偶分解：

$$
\begin{align*}
X[k] &= \sum_{n=0}^{N-1} x[n]W_N^{kn} \\
&= \sum_{r=0}^{N/2-1} x[2r]W_N^{2rk} + \sum_{r=0}^{N/2-1} x[2r+1]W_N^{(2r+1)k} \\
&= \sum_{r=0}^{N/2-1} x[2r]W_{N/2}^{rk} + W_N^k \sum_{r=0}^{N/2-1} x[2r+1]W_{N/2}^{rk}
\end{align*}
$$

定义：

$$
\begin{align*}
G[k] &= \sum_{r=0}^{N/2-1} x[2r]W_{N/2}^{rk} \quad \text{(偶数点DFT)} \\
H[k] &= \sum_{r=0}^{N/2-1} x[2r+1]W_{N/2}^{rk} \quad \text{(奇数点DFT)}
\end{align*}
$$

则：

$$
X[k] = G[k] + W_N^k H[k], \quad k=0,1,\dots,N-1
$$

由于 $G[k]$ 和 $H[k]$ 都是 $N/2$ 点周期序列：

$$
\begin{align*}
X[k] &= G[k] + W_N^k H[k], \quad k=0,1,\dots,N/2-1 \\
X[k+N/2] &= G[k] - W_N^k H[k], \quad k=0,1,\dots,N/2-1
\end{align*}
$$

#### 频域抽取法（DIF-FFT）

将频域输出按前后分解：

$$
\begin{align*}
X[2r] &= \sum_{n=0}^{N-1} x[n]W_N^{2rn} = \sum_{n=0}^{N/2-1} [x[n] + x[n+N/2]]W_{N/2}^{rn} \\
X[2r+1] &= \sum_{n=0}^{N-1} x[n]W_N^{(2r+1)n} = \sum_{n=0}^{N/2-1} [x[n] - x[n+N/2]]W_N^n W_{N/2}^{rn}
\end{align*}
$$

### 5.3 FFT算法的Python实现

```python
import numpy as np

def fft_recursive(x):
    """递归实现FFT"""
    N = len(x)
    if N <= 1:
        return x
    
    # 分治：偶数和奇数索引
    even = fft_recursive(x[0::2])
    odd = fft_recursive(x[1::2])
    
    # 旋转因子
    T = [np.exp(-2j * np.pi * k / N) * odd[k] for k in range(N//2)]
    
    # 合并结果
    return [even[k] + T[k] for k in range(N//2)] + \
           [even[k] - T[k] for k in range(N//2)]

def fft_iterative(x):
    """迭代（位逆序）FFT"""
    N = len(x)
    
    # 位逆序置换
    j = 0
    for i in range(1, N):
        bit = N >> 1
        while j & bit:
            j ^= bit
            bit >>= 1
        j ^= bit
        if i < j:
            x[i], x[j] = x[j], x[i]
    
    # 蝴蝶运算
    length = 2
    while length <= N:
        half_len = length // 2
        factor = np.exp(-2j * np.pi / length)
        for i in range(0, N, length):
            w = 1 + 0j
            for j in range(i, i + half_len):
                u = x[j]
                v = x[j + half_len] * w
                x[j] = u + v
                x[j + half_len] = u - v
                w *= factor
        length <<= 1
    
    return x
```

### 5.4 FFT的Verilog硬件实现

```verilog
module FFT #(
    parameter N = 1024,
    parameter DATA_WIDTH = 16
)(
    input wire clk,
    input wire rst_n,
    input wire start,
    input wire [DATA_WIDTH-1:0] data_in_real,
    input wire [DATA_WIDTH-1:0] data_in_imag,
    output reg [DATA_WIDTH-1:0] data_out_real,
    output reg [DATA_WIDTH-1:0] data_out_imag,
    output reg done
);

// 1. 双端口RAM存储输入数据
reg [DATA_WIDTH-1:0] mem_real [0:N-1];
reg [DATA_WIDTH-1:0] mem_imag [0:N-1];

// 2. 位逆序寻址
function [10:0] bit_reverse;
    input [10:0] address;
    begin
        bit_reverse = {address[0], address[1], address[2], 
                       address[3], address[4], address[5],
                       address[6], address[7], address[8],
                       address[9], address[10]};
    end
endfunction

// 3. CORDIC算法生成旋转因子
reg [15:0] cos_table [0:N/2-1];
reg [15:0] sin_table [0:N/2-1];

// 4. 蝴蝶运算单元
always @(posedge clk) begin
    if (!rst_n) begin
        // 复位
    end else if (start) begin
        // FFT计算流程
        // 阶段1：位逆序重排
        // 阶段2-10（对1024点）：log2(N)个阶段
        // 每个阶段：N/2个蝴蝶运算
    end
end

// 蝴蝶运算核心
task butterfly;
    input [DATA_WIDTH-1:0] a_real, a_imag;
    input [DATA_WIDTH-1:0] b_real, b_imag;
    input [DATA_WIDTH-1:0] twiddle_real, twiddle_imag;
    output [DATA_WIDTH-1:0] y0_real, y0_imag;
    output [DATA_WIDTH-1:0] y1_real, y1_imag;
    
    reg [DATA_WIDTH*2-1:0] temp_real, temp_imag;
    begin
        // 计算旋转乘法：b * W
        temp_real = b_real * twiddle_real - b_imag * twiddle_imag;
        temp_imag = b_real * twiddle_imag + b_imag * twiddle_real;
        
        // 蝴蝶加法和减法
        y0_real = a_real + temp_real[DATA_WIDTH+15:DATA_WIDTH];
        y0_imag = a_imag + temp_imag[DATA_WIDTH+15:DATA_WIDTH];
        
        y1_real = a_real - temp_real[DATA_WIDTH+15:DATA_WIDTH];
        y1_imag = a_imag - temp_imag[DATA_WIDTH+15:DATA_WIDTH];
    end
endtask

endmodule
```

## 6、采样定理与频域效应

### 6.1 采样定理的数学推导

#### 冲激串采样模型

连续信号 $x(t)$ 的冲激串采样表示为：

$$
x_s(t) = x(t) \cdot p(t) = \sum_{n=-\infty}^{\infty} x(t) \delta(t-nT_s)
$$

其中 $p(t) = \sum_{n=-\infty}^{\infty} \delta(t-nT_s)$ 为周期冲激串。

#### 频域分析

$p(t)$ 的傅里叶级数展开为：

$$
p(t) = \frac{1}{T_s} \sum_{k=-\infty}^{\infty} e^{j\frac{2\pi k}{T_s}t}
$$

因此采样信号：

$$
\begin{align*}
x_s(t) &= x(t) \cdot \frac{1}{T_s} \sum_{k=-\infty}^{\infty} e^{j\frac{2\pi k}{T_s}t} \\
&= \frac{1}{T_s} \sum_{k=-\infty}^{\infty} x(t) e^{j\frac{2\pi k}{T_s}t}
\end{align*}
$$

取傅里叶变换：

$$
\begin{align*}
X_s(\omega) &= \frac{1}{T_s} \sum_{k=-\infty}^{\infty} \mathcal{F}\{x(t)e^{j\frac{2\pi k}{T_s}t}\} \\
&= \frac{1}{T_s} \sum_{k=-\infty}^{\infty} X\left(\omega - \frac{2\pi k}{T_s}\right)
\end{align*}
$$

即：

$$
X_s(\omega) = \frac{1}{T_s} \sum_{k=-\infty}^{\infty} X(\omega - k\omega_s), \quad \omega_s = \frac{2\pi}{T_s}
$$

### 6.2 混叠现象的严格分析

#### 混叠的产生条件

当信号带宽 $B$ 大于 $\omega_s/2$ 时，频谱周期延拓会发生重叠：

$$
\text{混叠条件：} \omega_m \gt \frac{\omega_s}{2} \quad \text{或} \quad f_m \gt\frac{f_s}{2}
$$

#### 混叠频率计算

实际频率为 $f_a$ 的信号，在采样频率 $f_s$ 下，观测到的频率为：

$$
f_{\text{alias}} = |f_a - k f_s|, \quad k = \left\lfloor \frac{f_a}{f_s/2} \right\rfloor
$$

其中 $\lfloor \cdot \rfloor$ 表示向下取整。

#### 混叠的数学证明

设原信号 $x(t) = \cos(2\pi f_a t + \phi)$，采样后：

$$
\begin{align*}
x[n] &= \cos(2\pi f_a nT_s + \phi) \\
&= \cos(2\pi f_a \frac{n}{f_s} + \phi)
\end{align*}
$$

如果 $f_a = f_s + f_{\text{alias}}$，则：

$$
\begin{align*}
x[n] &= \cos(2\pi (f_s + f_{\text{alias}}) \frac{n}{f_s} + \phi) \\
&= \cos(2\pi n + 2\pi f_{\text{alias}} \frac{n}{f_s} + \phi) \\
&= \cos(2\pi f_{\text{alias}} \frac{n}{f_s} + \phi)
\end{align*}
$$

这正是频率为 $f_{\text{alias}}$ 的离散信号。

### 6.3 栅栏效应详细分析

#### 栅栏效应的数学描述

DFT只能观测到离散频率点：

$$
X[k] = X(e^{j\omega}) \big|_{\omega = \frac{2\pi k}{N}}, \quad k=0,1,\dots,N-1
$$

如同通过栅栏观察连续频谱，只能看到特定位置的样值。

#### 频谱泄露与栅栏效应的相互作用

实际中，有限长采样相当于加矩形窗：

$$
x_w[n] = x[n] \cdot w[n], \quad w[n] = 
\begin{cases}
1, & 0 \leq n \leq N-1 \\
0, & \text{其他}
\end{cases}
$$

频域上相当于频谱卷积：

$$
X_w(e^{j\omega}) = \frac{1}{2\pi} X(e^{j\omega}) * W(e^{j\omega})
$$

其中 $W(e^{j\omega}) = e^{-j\omega(N-1)/2} \frac{\sin(\omega N/2)}{\sin(\omega/2)}$ 是矩形窗的频谱。

#### 栅栏效应的影响量化

设真实频谱峰值为 $\omega_0$，DFT观测到的最近频率点为 $\omega_k = 2\pi k/N$，则观测误差：

$$
\Delta \omega = \omega_0 - \omega_k
$$

观测到的幅度误差：

$$
\Delta |X| = |X(e^{j\omega_0})| - |X(e^{j\omega_k})| \approx |X'(e^{j\omega_0})| \cdot \Delta \omega
$$

### 6.4 抗混叠滤波器设计

#### 理想抗混叠滤波器

理想抗混叠滤波器频率响应：

$$
H_{\text{aa}}(\omega) = 
\begin{cases}
1, & |\omega| \leq \omega_c \\
0, & |\omega| &gt; \omega_c
\end{cases}
$$

其中 $\omega_c = \pi f_s$（数字域）或 $\omega_c = 2\pi f_s/2$（模拟域）。

#### 实际滤波器设计

常用巴特沃斯滤波器，其幅度平方函数：

$$
|H(j\omega)|^2 = \frac{1}{1 + \left(\frac{\omega}{\omega_c}\right)^{2n}}
$$

$n$ 阶巴特沃斯滤波器的传递函数：

$$
H(s) = \frac{\omega_c^n}{\prod_{k=1}^{n} (s - s_k)}, \quad s_k = \omega_c e^{j\frac{\pi}{2n}(2k+n-1)}
$$

#### 滤波器参数选择

设计指标：
- 通带截止频率：$f_p = f_{\text{max}}$（信号最高频率）
- 阻带起始频率：$f_{\text{stop}} = f_s - f_{\text{max}}$
- 通带衰减：$\alpha_p$ dB
- 阻带衰减：$\alpha_s$ dB

所需滤波器阶数：

$$
n \geq \frac{\log\left[\left(10^{\alpha_s/10}-1\right)/\left(10^{\alpha_p/10}-1\right)\right]}{2\log(\Omega_s/\Omega_p)}
$$

其中 $\Omega_p = \omega_p/\omega_c$，$\Omega_s = \omega_s/\omega_c$。

### 6.5 信号重建理论

#### 理想重建滤波器

理想重建滤波器是理想低通滤波器：

$$
h_r(t) = \text{sinc}\left(\frac{\pi t}{T_s}\right) = \frac{\sin(\pi t/T_s)}{\pi t/T_s}
$$

频率响应：

$$
H_r(\omega) = 
\begin{cases}
T_s, & |\omega| \leq \pi/T_s \\
0, & |\omega| &gt; \pi/T_s
\end{cases}
$$

#### 实际DAC的零阶保持

零阶保持的时域响应：

$$
h_{\text{ZOH}}(t) = \text{rect}\left(\frac{t - T_s/2}{T_s}\right)
$$

频率响应：

$$
H_{\text{ZOH}}(\omega) = T_s \cdot \text{sinc}\left(\frac{\omega T_s}{2}\right) e^{-j\omega T_s/2}
$$

需要在DAC后接补偿滤波器：

$$
H_c(\omega) = \frac{1}{H_{\text{ZOH}}(\omega)} = \frac{e^{j\omega T_s/2}}{\text{sinc}(\omega T_s/2)}, \quad |\omega| \leq \pi/T_s
$$

### 6.6 过采样与欠采样技术

#### 过采样（Oversampling）

过采样率定义为：

$$
OSR = \frac{f_s}{2f_{\text{max}}}
$$

过采样的优势：
1. 降低抗混叠滤波器要求
2. 提高信噪比（SNR）
3. 减少量化噪声

信噪比改善：

$$
\text{SNR}_{\text{improvement}} = 10\log_{10}(OSR) \quad \text{dB}
$$

#### 欠采样（Undersampling）或带通采样

对于带通信号，带宽 $B$，中心频率 $f_c$，采样频率需满足：

$$
\frac{2f_c + B}{m+1} \leq f_s \leq \frac{2f_c - B}{m}
$$

其中 $m$ 为满足条件的最大整数。

### 6.7 量化效应分析

#### 量化误差模型

设量化步长为 $\Delta$，则量化误差 $e[n]$ 可建模为均匀分布的白噪声：

$$
p(e) = 
\begin{cases}
\frac{1}{\Delta}, & |e| \leq \Delta/2 \\
0, & \text{其他}
\end{cases}
$$

均值：$E[e] = 0$

方差：$\sigma_e^2 = \frac{\Delta^2}{12}$

#### 量化信噪比

对于满幅度正弦信号，幅度 $A = 2^{b-1}\Delta$，功率 $P_s = A^2/2$，量化噪声功率 $P_n = \Delta^2/12$，信噪比：

$$
\text{SNR} = 10\log_{10}\left(\frac{P_s}{P_n}\right) = 6.02b + 1.76 \quad \text{dB}
$$

其中 $b$ 为量化位数。

#### 过采样对量化噪声的改善

过采样将量化噪声功率分散到更宽的频带 $[-\pi,\pi]$，经过数字滤波后，噪声功率降低：

$$
\text{SNR}_{\text{OS}} = 6.02b + 1.76 + 10\log_{10}(OSR) \quad \text{dB}
$$

# 滤波器系统理论与设计方法

## 1.滤波器的基本分类与数学描述

### 1.1 滤波器的频率响应特性

滤波器根据其频率响应幅度的特性可分为四类基本形式。设滤波器的频率响应函数为$H(\omega)$，其中$\omega=2\pi f$为角频率。

**低通滤波器**的幅度响应满足：

$$
|H(\omega)| \approx 
\begin{cases}
1, & \text{当 } \omega < \omega_c \\
0, & \text{当 } \omega > \omega_c
\end{cases}
$$

其中$\omega_c$为截止角频率。

**高通滤波器**的幅度响应满足：

$$
|H(\omega)| \approx 
\begin{cases}
0, & \text{当 } \omega < \omega_c \\
1, & \text{当 } \omega > \omega_c
\end{cases}
$$

**带通滤波器**的幅度响应在频带$[\omega_1, \omega_2]$内近似为1，在此频带外近似为0，其中$\omega_1$为下截止频率，$\omega_2$为上截止频率，中心频率$\omega_0 = \sqrt{\omega_1\omega_2}$，带宽$BW = \omega_2 - \omega_1$。

**带阻滤波器**的幅度响应在频带$[\omega_1, \omega_2]$内近似为0，在此频带外近似为1。

### 1.2 滤波器的性能参数

**通带**定义为幅度响应满足$|H(\omega)| \geq 1/\sqrt{2} \approx 0.707$的频率范围，对应衰减不超过3 dB。**阻带**定义为幅度响应低于规定衰减值$A_{\min}$的频率范围，通常$A_{\min}$取20 dB、40 dB或更高。

**截止频率**$\omega_c$通常指幅度响应下降至通带最大值$1/\sqrt{2}$时的频率，即-3 dB点。对于具有纹波的滤波器，截止频率可定义为纹波带宽的边缘频率。

**纹波参数**$\delta_p$和$\delta_s$分别表示通带和阻带内幅度响应的最大偏差。通带纹波通常表示为：

$$
1 - \delta_p \leq |H(\omega)| \leq 1 + \delta_p, \quad \omega \in \text{通带}
$$

或以分贝表示：$R_p = -20\log_{10}(1 - \delta_p)$ dB

阻带衰减表示为：

$$
|H(\omega)| \leq \delta_s, \quad \omega \in \text{阻带}
$$

或以分贝表示：$A_s = -20\log_{10}(\delta_s)$ dB

**过渡带**为通带边缘频率$\omega_p$与阻带起始频率$\omega_s$之间的区域，即$\omega_p < \omega < \omega_s$。过渡带宽度$\Delta\omega = \omega_s - \omega_p$。

**滤波器阶数**n决定了幅度响应在过渡带的陡峭程度。对于无传输零点的滤波器，阻带衰减渐近线斜率为$-20n$ dB/十倍频程。

## 2.经典滤波器逼近函数 

### 2.1 巴特沃斯逼近

巴特沃斯滤波器在$\omega=0$处具有最大平坦幅度特性，其幅度平方函数为：

$$
|H(j\omega)|^2 = \frac{1}{1 + (\omega/\omega_c)^{2n}}
$$

其中$n$为滤波器阶数。

在$s$复平面，巴特沃斯滤波器的传递函数极点位于半径为$\omega_c$的圆上，角度间隔为$\pi/n$，且全部位于左半平面。第$k$个极点位置为：

$$
s_k = \omega_c \exp\left[j\left(\frac{\pi}{2} + \frac{(2k-1)\pi}{2n}\right)\right], \quad k=1,2,\ldots,n
$$

归一化($\omega_c=1$ rad/s)巴特沃斯多项式的系数可通过递推公式计算或查表获得。

### 2.2 切比雪夫逼近

切比雪夫I型滤波器在通带具有等波纹特性，阻带单调衰减。其幅度平方函数为：

$$
|H(j\omega)|^2 = \frac{1}{1 + \varepsilon^2 C_n^2(\omega/\omega_p)}
$$

其中$C_n(x)$为第一类切比雪夫多项式：$C_n(x)=\cos(n \arccos(x)), |x|\leq 1$；$C_n(x)=\cosh(n \operatorname{arccosh}(x)), |x|>1$。$\varepsilon$为纹波系数，与通带纹波$R_p$的关系为：$\varepsilon = \sqrt{10^{R_p/10} - 1}$。

切比雪夫II型滤波器在通带单调，阻带具有等波纹特性，其幅度平方函数为：

$$
|H(j\omega)|^2 = \frac{1}{1 + \varepsilon^2 / C_n^2(\omega_s/\omega)}
$$

切比雪夫滤波器的极点位于椭圆上，椭圆方程由纹波参数决定。

### 2.3 椭圆逼近

椭圆滤波器在通带和阻带均具有等波纹特性，提供了给定阶数下的最陡过渡带。其幅度平方函数为：

$$
|H(j\omega)|^2 = \frac{1}{1 + \varepsilon^2 R_n^2(\omega, L)}
$$

其中$R_n$为雅可比椭圆函数，$L$为选择性因子，定义为阻带起始频率与通带截止频率之比。

椭圆滤波器的传递函数包含传输零点，位于阻带内$j\omega$轴上，这使其在过渡带边缘具有极高的斜率。

### 2.4 贝塞尔逼近

贝塞尔滤波器具有最大平坦群延迟特性，其传递函数由反向贝塞尔多项式构成：

$$
B_n(s) = \sum_{k=0}^{n} a_k s^k, \quad \text{其中 } a_k = \frac{(2n-k)!}{2^{n-k} k! (n-k)!}
$$

贝塞尔滤波器的相位响应近似线性，群延迟在通带内接近常数，但幅度响应选择性较差。

## 3.滤波器设计方法

### 3.1 归一化低通原型

滤波器设计通常从归一化低通原型开始，其截止频率$\omega_c'=1$ rad/s，参考阻抗$R'=1\Omega$。原型滤波器的传递函数$H_p(s')$确定后，通过频率变换和阻抗缩放得到实际滤波器。

对于无源LC滤波器，常用梯形结构实现。元件值可通过网络综合法或查表获得。例如，$n$阶巴特沃斯低通原型的元件值($g$值)为：

$$
g_k = 2 \sin\left[\frac{(2k-1)\pi}{2n}\right], \quad k=1,2,\ldots,n
$$

### 3.2 频率变换

**低通到低通变换**：将原型频率$s'$映射为实际频率$s$，变换关系为$s' = s/\omega_c$。原型电感$L'$变换为实际电感$L = (R/\omega_c)L'$，原型电容$C'$变换为实际电容$C = C'/(R\omega_c)$。

**低通到高通变换**：变换关系为$s' = \omega_c/s$。原型电感$L'$变换为实际电容$C = 1/(R\omega_cL')$，原型电容$C'$变换为实际电感$L = R/(\omega_cC')$。

**低通到带通变换**：变换关系为$s' = \dfrac{s^2 + \omega_0^2}{BW \cdot s}$，其中$\omega_0=\sqrt{\omega_1\omega_2}$为中心频率，$BW=\omega_2-\omega_1$为带宽。原型电感$L'$变换为串联LC谐振电路：$L_s = \dfrac{R \cdot BW \cdot L'}{\omega_0^2}$，$C_s = \dfrac{1}{\omega_0^2 L_s}$。原型电容$C'$变换为并联LC谐振电路：$C_p = \dfrac{BW \cdot C'}{R\omega_0^2}$，$L_p = \dfrac{1}{\omega_0^2 C_p}$。

**低通到带阻变换**：变换关系为$s' = \dfrac{BW \cdot s}{s^2 + \omega_0^2}$。这是带通变换的逆变换。

### 3.3 滤波器阶数确定

给定通带截止频率$\omega_p$、阻带起始频率$\omega_s$、通带最大衰减$A_p$(dB)、阻带最小衰减$A_s$(dB)，可计算所需滤波器阶数。

对于巴特沃斯滤波器：

$$
n \geq \frac{\log\left[(10^{A_s/10}-1)/(10^{A_p/10}-1)\right]}{2 \log(\omega_s/\omega_p)}
$$

对于切比雪夫I型滤波器：

$$
n \geq \frac{\operatorname{arccosh}\left[\sqrt{(10^{A_s/10}-1)/(10^{A_p/10}-1)}\right]}{\operatorname{arccosh}(\omega_s/\omega_p)}
$$

## 4.无源滤波器实现

### 4.1 LC梯形网络

无源滤波器通常采用梯形网络结构，有T型和π型两种基本形式。综合方法包括影像参数法和插入损耗法。

对于双端接载的LC梯形网络（源电阻$R_s$，负载电阻$R_L$），其传递函数可通过达林顿综合法获得。该方法将给定的传递函数$H(s)$实现为无损LC网络，两端接电阻。

具体步骤：

- 由$|H(j\omega)|^2$确定反射系数$\rho(s)\rho(-s) = 1 - H(s)H(-s)$
- 选择左半平面零点构成$\rho(s)$
- 计算输入阻抗$Z_{in}(s) = R_s[1+\rho(s)]/[1-\rho(s)]$
- 通过连分式展开实现LC梯形网络

### 4.2 元件灵敏度

灵敏度$S_x^y = (\partial y/\partial x)(x/y)$表示参数$y$对元件$x$变化的敏感程度。对于滤波器，重要的灵敏度包括：

- 极点频率灵敏度：$S_{L,C}^{\omega_0} = -1/2$
- 品质因数Q灵敏度：$S_{L,C}^{Q} = \pm 1/2$（取决于电路拓扑）

无源LC滤波器的灵敏度较低，巴特沃斯逼近的灵敏度最低，椭圆逼近的灵敏度最高。

### 4.3 实际元件非理想性

实际电感包含串联电阻$R_L$，导致品质因数$Q_L = \omega L/R_L$有限。电容存在等效串联电阻ESR和寄生电感。这些非理想性影响滤波器的插入损耗和频率响应。

设计时需考虑元件值容差、温度系数和长期稳定性。通常需要容差分析，使用蒙特卡洛方法评估性能变化范围。

## 5.有源滤波器

### 5.1 有源滤波器基本结构

有源滤波器使用运算放大器、电阻和电容实现滤波功能，无需电感。基本二阶节结构包括：

**Sallen-Key结构**：电压控制电压源(VCVS)型，传递函数为：

$$
H(s) = \frac{K}{s^2RC_1C_2 + s(RC_1+RC_2-C_1R(1-K)) + 1}
$$

其中$K$为同相放大器增益（通常$K=1$为单位增益）。

**多重反馈(MFB)结构**：电流反馈型，传递函数为：

$$
H(s) = -\frac{R_2/R_1}{s^2R_2R_3C_1C_2 + sC_1(R_2+R_3+R_2R_3/R_1) + 1}
$$

**状态变量滤波器**：由积分器和加法器组成，可同时实现低通、高通和带通输出。传递函数为：

$$
H_{LP}(s) = -\frac{R_6/R_5}{s^2(R_1R_3C_1C_2)/(R_2R_4) + s(R_1C_1)/(R_2) + 1}
$$

### 5.2 运算放大器限制

有源滤波器的性能受运放参数限制：
- 增益带宽积GBW：滤波器截止频率$f_c$应满足$f_c < GBW/(10Q_{\max})$，其中$Q_{\max}$为最高品质因数
- 压摆率SR：处理大信号时，SR应满足$SR > 2\pi f_{\max} V_p$，其中$f_{\max}$为最高信号频率，$V_p$为峰值电压
- 输入阻抗和偏置电流：影响低频精度
- 噪声：决定滤波器的最小可检测信号

### 5.3 高阶有源滤波器实现

高阶滤波器通过二阶节和一阶节级联实现。$n$阶滤波器需要$\lfloor n/2 \rfloor$个二阶节，若$n$为奇数则再加一个一阶节。

级联设计步骤：
- 将高阶传递函数分解为二阶因式乘积
- 为每个二阶节分配极点和零点
- 设计各二阶节电路，通常从高Q节开始
- 确定各级增益分配以满足动态范围要求
- 级联时考虑节间阻抗匹配

## 6.滤波器设计流程

### 6.1 设计规范

给定以下滤波器规格：
- 类型：带通滤波器
- 通带：900-1100 Hz通带纹波：$\leq 0.5$ dB
- 阻带：$\leq 800$ Hz 和 $\geq 1200$ Hz
- 阻带衰减：$\geq 40$ dB
- 阻抗：600 $\Omega$

通带边缘频率：$\omega_{p1}=2\pi\times 900$，$\omega_{p2}=2\pi\times 1100$

阻带边缘频率：$\omega_{s1}=2\pi\times 800$，$\omega_{s2}=2\pi\times 1200$

中心频率：$\omega_0 = \sqrt{\omega_{p1}\omega_{p2}} \approx 2\pi\times 995$

带宽：$BW = \omega_{p2} - \omega_{p1} = 2\pi\times 200$

选择性：$\omega_{s2}/\omega_{p2} = 1200/1100 \approx 1.091$，$\omega_{p1}/\omega_{s1} = 900/800 = 1.125$

计算低通原型要求：$\Omega_s = \min(\omega_{s2}/\omega_{p2}, \omega_{p1}/\omega_{s1}) = 1.091$

对于切比雪夫I型（通带纹波0.5 dB）：

$$
n \geq \frac{\operatorname{arccosh}\left[\sqrt{(10^{40/10}-1)/(10^{0.5/10}-1)}\right]}{\operatorname{arccosh}(1.091)} \approx 7.2
$$

故选择$n=8$。

查表得8阶0.5 dB纹波切比雪夫低通原型元件值（对于π型结构）：

$$
\begin{aligned}
&g_1=1.6703, \quad g_2=1.1926, \quad g_3=2.3661, \quad g_4=0.8419, \\
&g_5=2.2404, \quad g_6=0.6555, \quad g_7=1.9841, \quad g_8=0.8140
\end{aligned}
$$

将低通原型变换为带通滤波器：
对于原型电感$L_k'$，变换为串联LC电路：

$$
\begin{aligned}
L_{sk} &= \frac{R \cdot BW \cdot L_k'}{\omega_0^2} \\
C_{sk} &= \frac{1}{\omega_0^2 L_{sk}}
\end{aligned}
$$

对于原型电容$C_k'$，变换为并联LC电路：

$$
\begin{aligned}
C_{pk} &= \frac{BW \cdot C_k'}{R\omega_0^2} \\
L_{pk} &= \frac{1}{\omega_0^2 C_{pk}}
\end{aligned}
$$

代入数值计算实际元件值：

$$
\begin{aligned}
\omega_0 &= 2\pi\times 995 \approx 6251.3 \text{ rad/s} \\
BW &= 2\pi\times 200 \approx 1256.6 \text{ rad/s} \\
R &= 600 \Omega
\end{aligned}
$$

例如，对于$g_1=1.6703$（串联电感）：

$$
\begin{aligned}
L_{s1} &= \frac{600\times 1256.6\times 1.6703}{6251.3^2} \approx 0.0322 \text{ H} = 32.2 \text{ mH} \\
C_{s1} &= \frac{1}{6251.3^2\times 0.0322} \approx 7.94\times 10^{-7} \text{ F} = 0.794 \mu\text{F}
\end{aligned}
$$

重复计算所有元件值。

作为替代方案，可采用有源滤波器实现。将8阶滤波器分解为4个二阶节级联。每个二阶节的传递函数为：

$$
H_i(s) = \frac{K_i \omega_{0i}^2}{s^2 + (\omega_{0i}/Q_i)s + \omega_{0i}^2}
$$

使用状态变量结构实现各二阶节，可独立调整中心频率和Q值。节间使用缓冲器隔离。

计算各元件对中心频率和带宽的灵敏度。对于LC谐振电路：

$$
\begin{aligned}
S_L^{\omega_0} &= S_C^{\omega_0} = -\frac{1}{2} \\
S_L^{Q} &= S_C^{Q} = \frac{1}{2}
\end{aligned}
$$

这表明元件值变化1\%会导致中心频率变化0.5\%，Q值变化0.5\%。

通过容差分析，确定元件精度要求。若要求中心频率变化小于1\%，则电感和电容容差应小于2\%。使用温度补偿电容（如NPO陶瓷）可改善温度稳定性。

### 6.2 滤波器实现中的实际问题

在较高频率下（$>10$ MHz），寄生参数影响显著：
- 电感自谐振频率：由分布电容引起，限制最大工作频率
- 电容串联电感：由引线电感引起，影响高频特性
- 印刷电路板走线电感：约1 nH/mm，在GHz范围不可忽略

滤波器的动态范围定义为最大不失真输出与等效输入噪声之比。对于有源滤波器，噪声主要来自：
- 电阻热噪声：$e_n = \sqrt{4kTRB}$，其中$k$为玻尔兹曼常数，$T$为绝对温度，$B$为带宽
- 运放电压噪声和电流噪声
- 电源噪声耦合

最小化噪声措施包括：使用低噪声运放;优化电阻值（降低热噪声但增加电流噪声）;良好的电源去耦;屏蔽和接地技术

### 6.3 现代滤波器技术

**开关电容滤波器**使用开关和电容模拟电阻，其等效电阻$R_{eq} = 1/(f_{clk} C)$，其中$f_{clk}$为时钟频率。截止频率与时钟频率成比例，易于精确控制。传递函数由电容比值决定，与绝对电容值无关，适合集成电路实现。限制包括：时钟馈通和电荷注入;有限开关速度限制最高工作频率;混叠效应需要抗混叠滤波器

**自适应滤波器**系数可实时调整，以最小化误差信号$e(n)$。最常用算法为最小均方(LMS)算法：

$$
w(n+1) = w(n) + \mu e(n) x(n)
$$

其中$w(n)$为系数向量，$\mu$为步长参数，$x(n)$为输入向量。

# 数字滤波器

## 1.数字频率与模拟频率的根本关系

要理解数字频率，必须从连续时间信号的离散化过程开始。一个模拟信号 $x_a(t)$ 经过理想采样后，得到数字序列 $x[n] = x_a(nT)$，其中 $T$ 为采样周期，其倒数 $f_s = 1/T$ 称为采样频率。

一个模拟复指数信号 $e^{j\Omega t}$ 的角频率为 $\Omega$（单位：弧度/秒）。采样后，该信号变为 $e^{j\Omega nT} = e^{j(\Omega T)n}$。我们定义 **数字频率** $\omega = \Omega T$，其单位为 **弧度/样本**。因此，数字序列可表示为 $e^{j\omega n}$。

这个关系 $\omega = \Omega T = 2\pi f / f_s$ 是连接模拟与数字领域的桥梁。它指出，数字频率 $\omega$ 本质上是模拟频率 $\Omega$ 相对于采样频率 $f_s$ 的归一化值。

由于离散时间傅里叶变换（DTFT）的周期性，数字频率 $\omega$ 通常只考虑一个 $2\pi$ 周期，例如 $[-\pi, \pi]$ 或 $[0, 2\pi]$。根据奈奎斯特-香农采样定理，为了避免混叠，模拟信号的最高频率分量必须小于 $f_s/2$。对应地，在数字频率域，有意义的最高频率为 $\omega = \pi$（对应 $\Omega = \pi f_s$）。当模拟频率超过 $f_s/2$（即 $\omega$ 超过 $\pi$）时，会产生混叠，即高频分量会被错误地映射到 $[- \pi, \pi]$ 区间内的某个低频上。

## 2.无限脉冲响应（IIR）滤波器
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

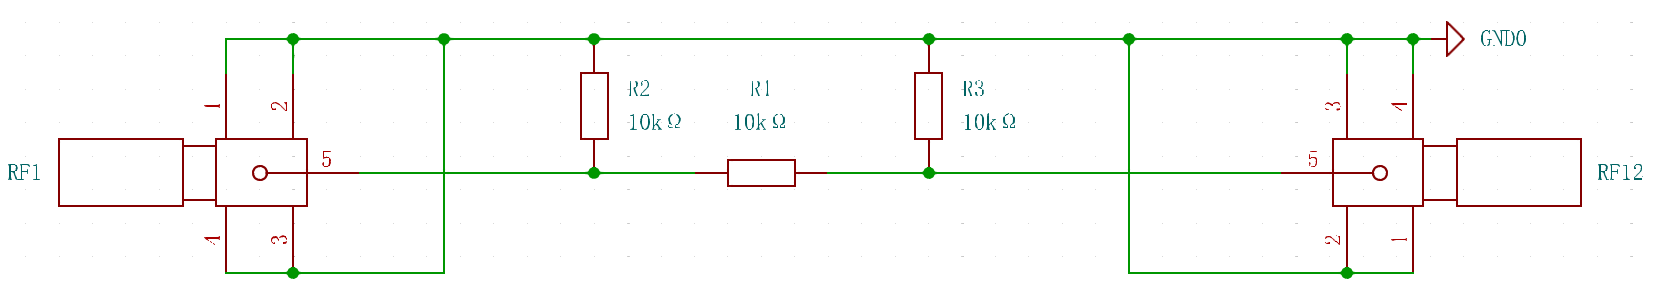
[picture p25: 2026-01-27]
Bitmap/Attenuator_PI_Schematic.png

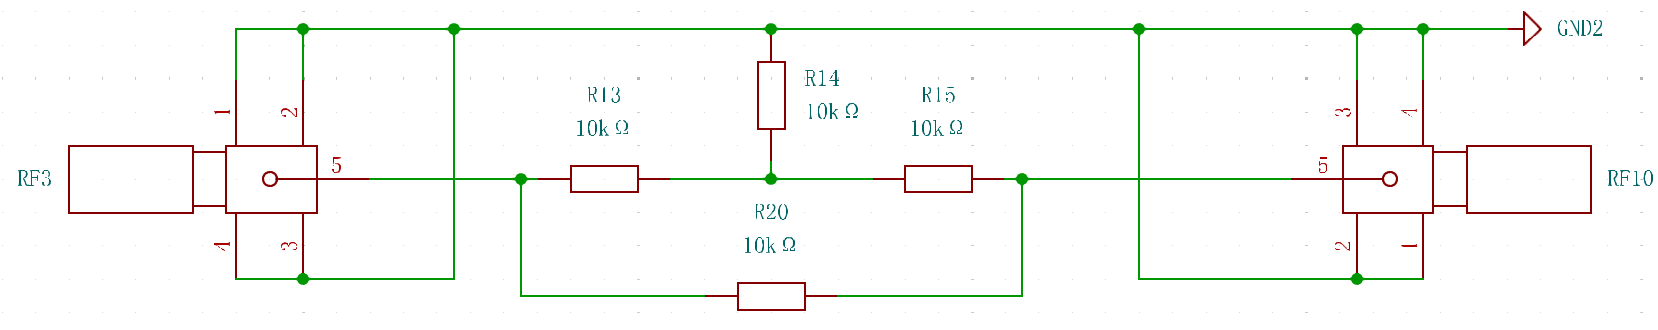
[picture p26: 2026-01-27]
Bitmap/Attenuator_BridgeT_Schematic.png

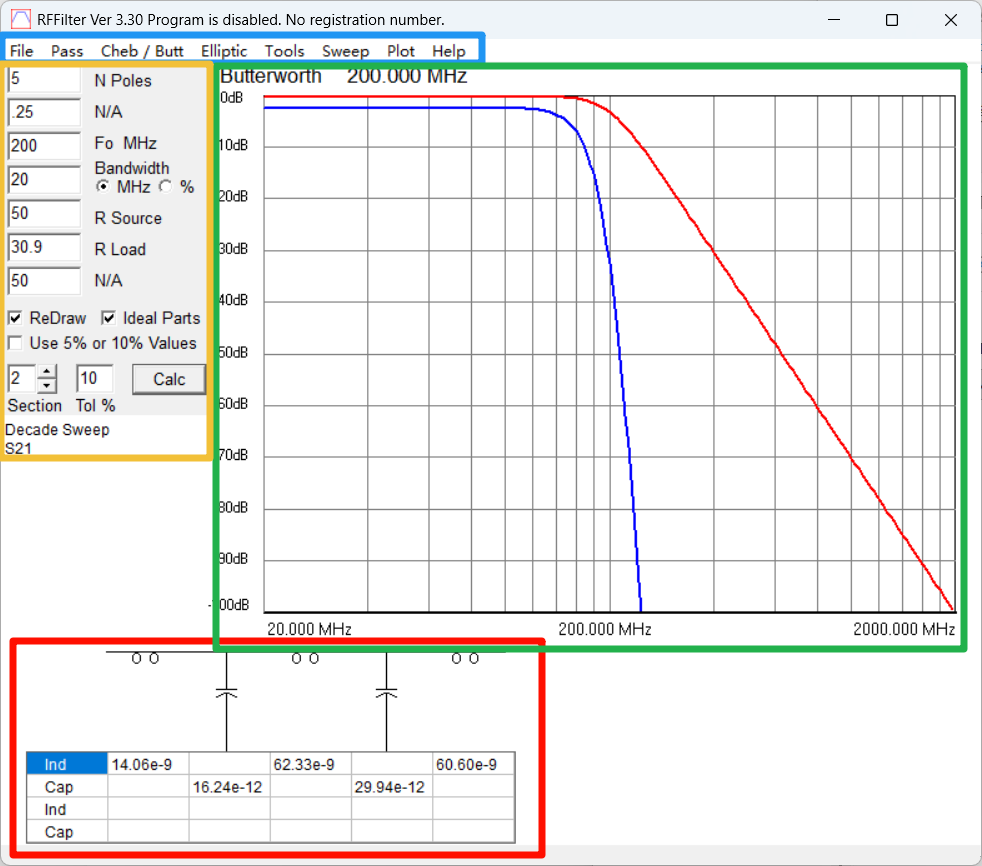
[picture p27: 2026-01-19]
Learning/FilterDesign/Bitmap/RFFilter.png

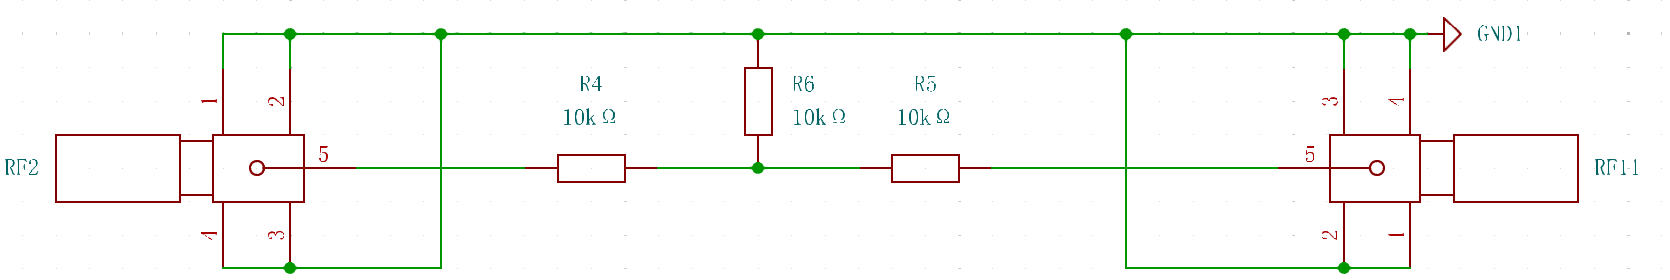
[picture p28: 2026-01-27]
Bitmap/Attenuator_T_Schematic.png

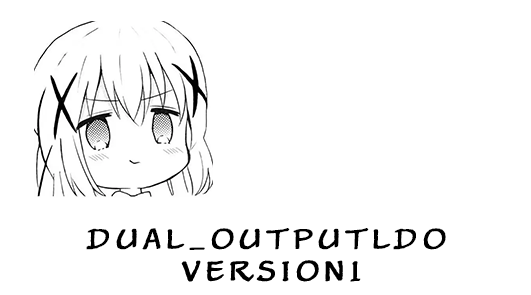
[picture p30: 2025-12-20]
Bitmap/Dual_OutputLDO底层.png

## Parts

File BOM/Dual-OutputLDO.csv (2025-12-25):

Reference | Value | Qty
C1,C2,C5,C6,C7,C16,C18 | 22uF | 7
C3,C8,C11,C12 | 1uF | 4
C4,C17,C19 | 100nF | 3
C9 | 220pF | 1
C10 | 10uF | 1
C13,C14 | 2.2uF | 2
C15 | 4.7uF | 1
CN1,CN2,CN3,LED1,U1,U2 | ~ | 6
L1 | 3.3uH | 1
R1 | 10Ω | 1
R2 | MP_R1 | 1
R3 | MP_R2 | 1
R4,R9 | 10kΩ | 2
R5,R7 | LM_R1 | 2
R6,R8 | LM_R2 | 2

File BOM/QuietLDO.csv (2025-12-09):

Reference | Value | Footprint | Qty | Manufacturer Part
hole1,hole2,hole3,hole4 | ~ | persional_library:m3 125x300 | 4
CN1,CN2,CN3,CN4,CN5,CN6,CN7,CN8,CN9,CN10,CN11,CN12,CN13,CN14,CN15,CN16 | ~ | persional_library:CONN-TH_2P-P1.25_XUNPU_WAFER-GH1.25-2PWB | 16 | WAFER-GH1.25-2PWB
R1,R2,R4,R5,R7,R8,R11,R12,R14,R15,R16,R17,R18,R20,R21,R22,R23,R24 | NC | persional_library:R0603 | 18 | 0603WAF1002T5E
R3,R6,R9,R10,R13,R19 | 0Ω | persional_library:R0603 | 6 | 0603WAF1002T5E
R25,R26,R27,R28,R33 | 10kΩ | persional_library:R0603 | 5 | 0603WAF1002T5E
R34 | 10Ω | persional_library:R0603 | 1 | 0603WAF1002T5E
R35 | 100kΩ | persional_library:R0603 | 1 | 0603WAF1002T5E
R36 | 13.7kΩ | persional_library:R0603 | 1 | 0603WAF1002T5E
C1,C2,C9,C14,C17,C22,C25,C30 | 1uF | persional_library:C0603 | 8 | CL10A105KB8NNNC
C3,C4,C5,C6,C7,C8,C10,C11,C12,C13,C15,C16,C18,C19,C20,C21,C23,C24,C26,C27,C28,C29,C31,C32 | 10uF | persional_library:C0603 | 24 | CL10A105KB8NNNC
C37 | 220pF | persional_library:C0603 | 1 | CL10A105KB8NNNC
C33,C41 | 1uF | persional_library:C0805 | 2 | CL21A226MAQNNNE
C34,C35,C36,C39,C40 | 22uF | persional_library:C0805 | 5 | CL21A226MAQNNNE
C38 | 100nF | persional_library:C0805 | 1 | CL21A226MAQNNNE
SW2 | ~ | persional_library:SW-SMD_16P-L11.7-W5.4-P1.27-LS8.5 | 1 | DSHP08TSGER
L1 | 3.3uH | persional_library:IND-SMD_L7.0-W6.6 | 1 | FXL0630-2R2-M
LED1,LED2,LED3,LED4 | ~ | persional_library:LED0603-RD | 4 | LTST-C190KSKT
U5 | ~ | persional_library:SOT-23-8_L2.9-W1.6-P0.65-LS2.8-BR | 1 | MP2236GJ-Z
SW1 | ~ | persional_library:SW-TH_SK12D07VG4 | 1 | SK12D07VG4
CN17 | ~ | persional_library:CONN-TH_XT30PW-M | 1 | XT30PW-M30.G.Y
CN18 | ~ | persional_library:CONN-TH_2P-P2.50_HX25003-2A | 1 | ZX-XH2.54-2PZZ
U1,U2,U3,U4 | ~ | persional_library:VQFN-20_L5.0-W5.0-P0.65-TL-EP | 4 | TPS7A4701RGWR

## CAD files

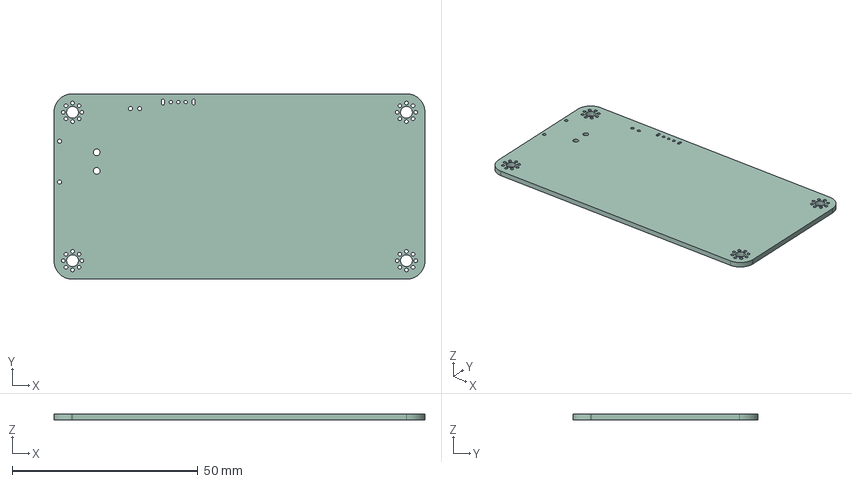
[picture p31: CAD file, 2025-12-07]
3D/QuietLDO.step
100.0 x 50.0 x 1.60 mm

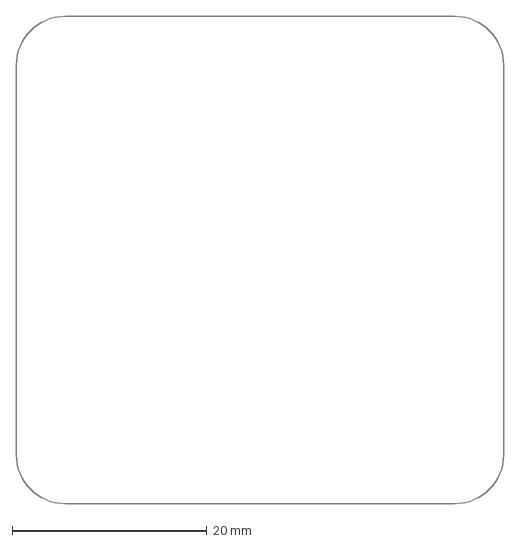
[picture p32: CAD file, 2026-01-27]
CAD/Attenuator-Board.dxf
50.0 x 50.0 mm

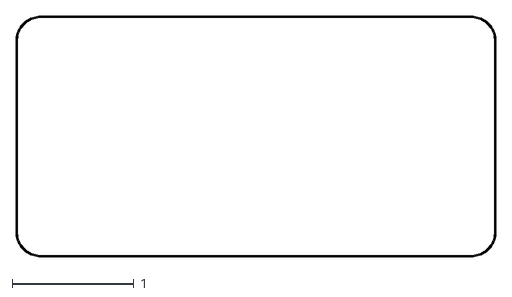
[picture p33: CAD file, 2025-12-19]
Hardware/QuietLDO/QuietLDO_Stencil/QuietLDO-Edge_Cuts.dxf
3.95 x 1.98

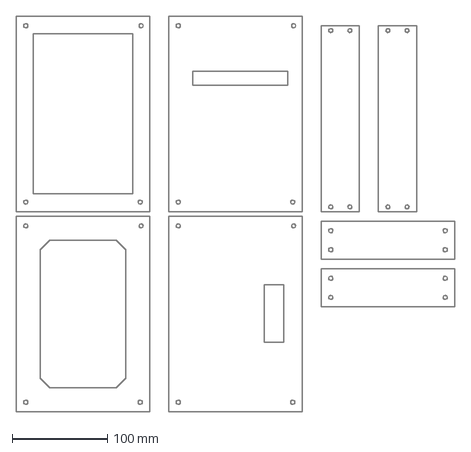
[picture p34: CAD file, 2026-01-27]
CAD/HDMI支架.dxf
460.0 x 415.0 mm

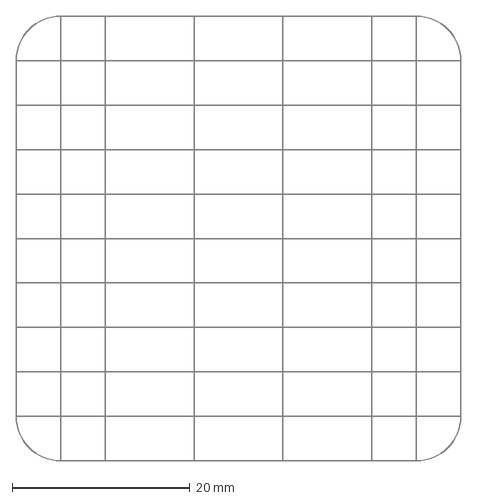
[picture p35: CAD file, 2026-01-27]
CAD/Attenuator.dxf
50.0 x 50.0 mm

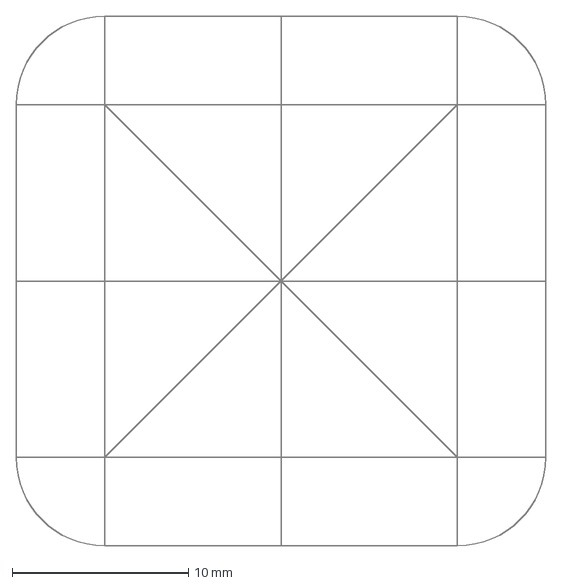
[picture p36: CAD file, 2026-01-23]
CAD/RF_DualSwitch.dxf
30.0 x 30.0 mm

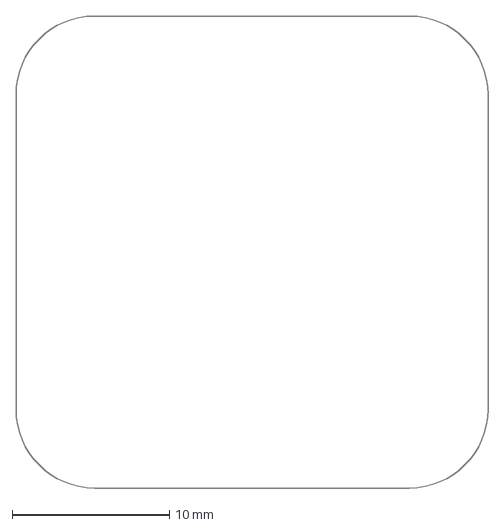
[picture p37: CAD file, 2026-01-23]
CAD/RF_DualSwitch_Board.dxf
30.0 x 30.0 mm

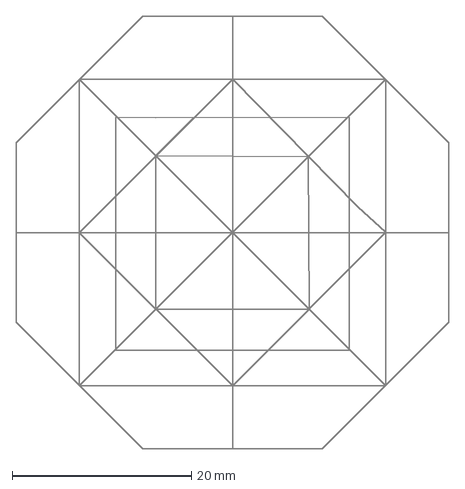
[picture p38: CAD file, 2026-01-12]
CAD/RF_TribSwitch.dxf
48.3 x 48.3 mm

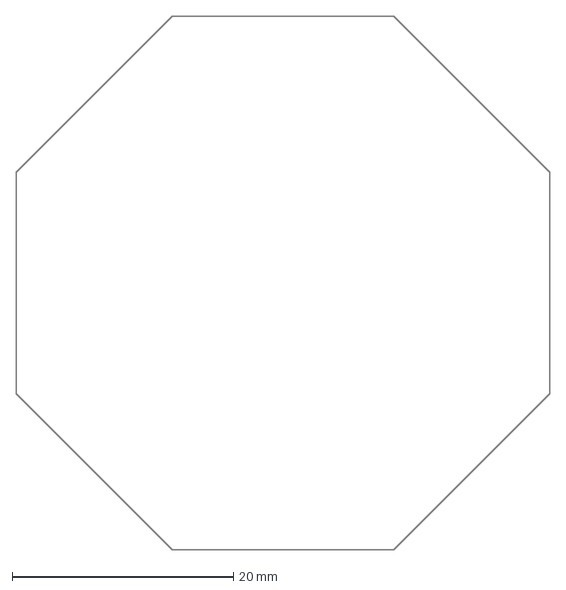
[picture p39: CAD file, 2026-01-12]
CAD/RF_TribSwitch_Board.dxf
48.3 x 48.3 mm

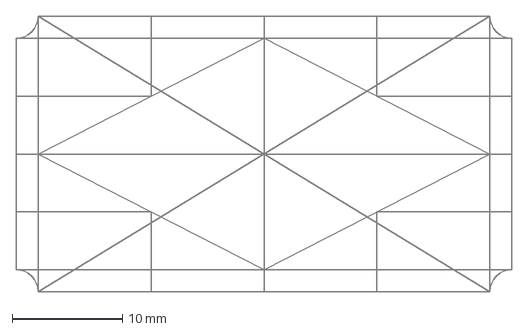
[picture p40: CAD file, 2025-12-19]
CAD/Dual-OutputLDO.dxf
45.0 x 25.0 mm

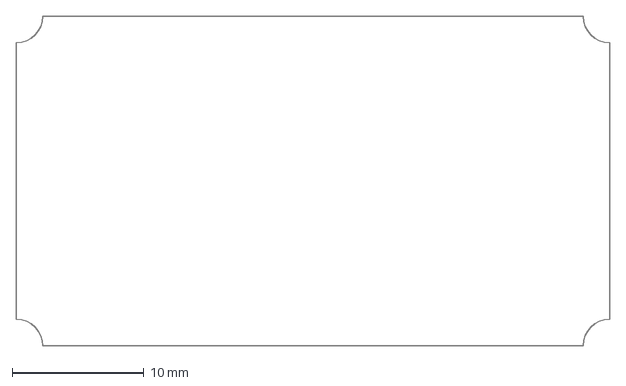
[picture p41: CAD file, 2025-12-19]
CAD/Dual-OutputLDO-Board.dxf
45.0 x 25.0 mm

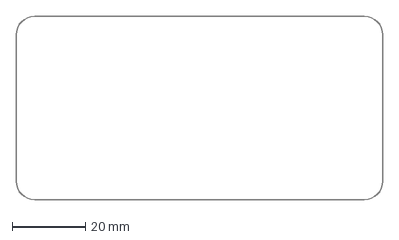
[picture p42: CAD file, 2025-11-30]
CAD/QuietLDO-Board.dxf
100.0 x 50.0 mm

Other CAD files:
CAD/QuietLDO.dxf
Hardware/QuietLDO/QuietLDO_Stencil/QuietLDO-B_Paste.dxf
Hardware/QuietLDO/QuietLDO_Stencil/QuietLDO-F_Paste.dxf
Tools/PCB2STEP/QuietLDO-B_Paste.dxf
Tools/PCB2STEP/QuietLDO-F_Paste.dxf

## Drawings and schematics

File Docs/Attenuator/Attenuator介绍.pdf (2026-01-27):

# Attenuator 衰减器模块

## PI型衰减器

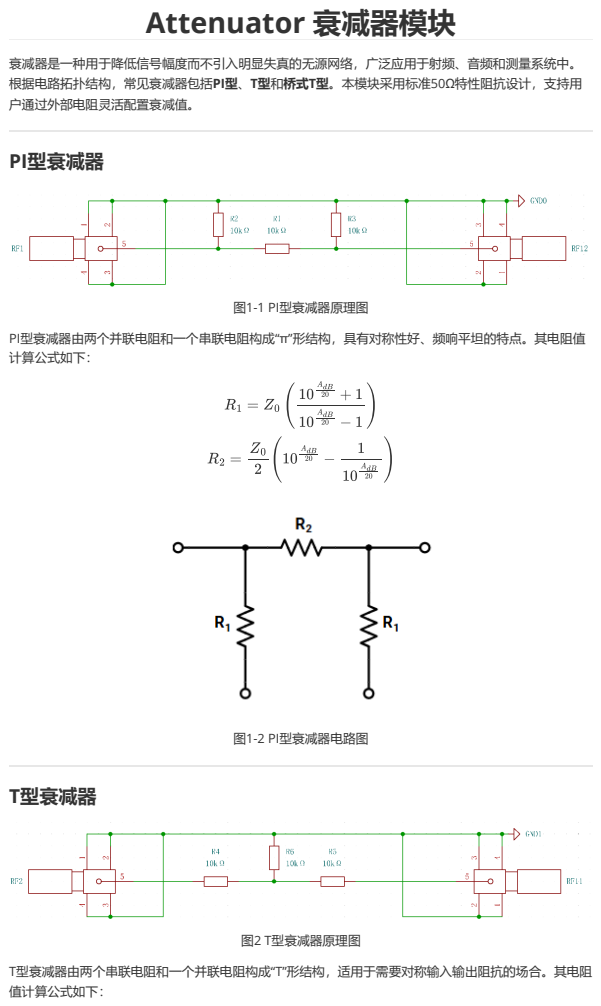
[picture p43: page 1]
图1-1 PI型衰减器原理图; 图1-2 PI型衰减器电路图; 图2 T型衰减器原理图; T型衰减器

衰减器是一种用于降低信号幅度而不引入明显失真的无源网络，广泛应用于射频、音频和测量系统中。
根据电路拓扑结构，常见衰减器包括PI型、T型和桥式T型。本模块采用标准50Ω特性阻抗设计，支持用
户通过外部电阻灵活配置衰减值。

PI型衰减器由两个并联电阻和一个串联电阻构成“π”形结构，具有对称性好、频响平坦的特点。其电阻值
计算公式如下：

T型衰减器由两个串联电阻和一个并联电阻构成“T”形结构，适用于需要对称输入输出阻抗的场合。其电阻
值计算公式如下：

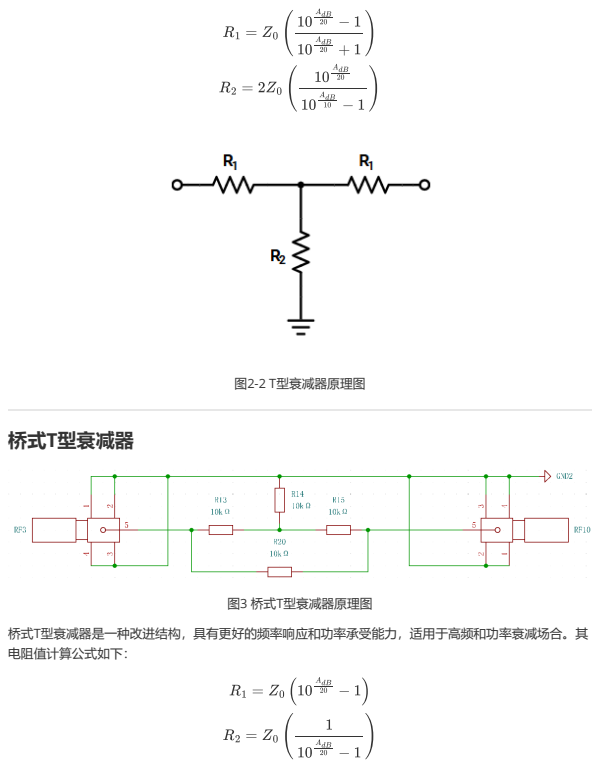
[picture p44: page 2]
图2-2 T型衰减器原理图; 图3 桥式T型衰减器原理图; 桥式T型衰减器

桥式T型衰减器是一种改进结构，具有更好的频率响应和功率承受能力，适用于高频和功率衰减场合。其
电阻值计算公式如下：

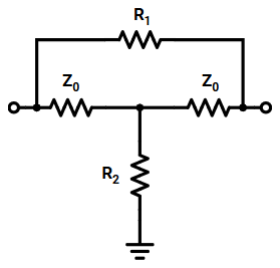
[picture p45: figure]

图3-2 桥式T型衰减器原理图

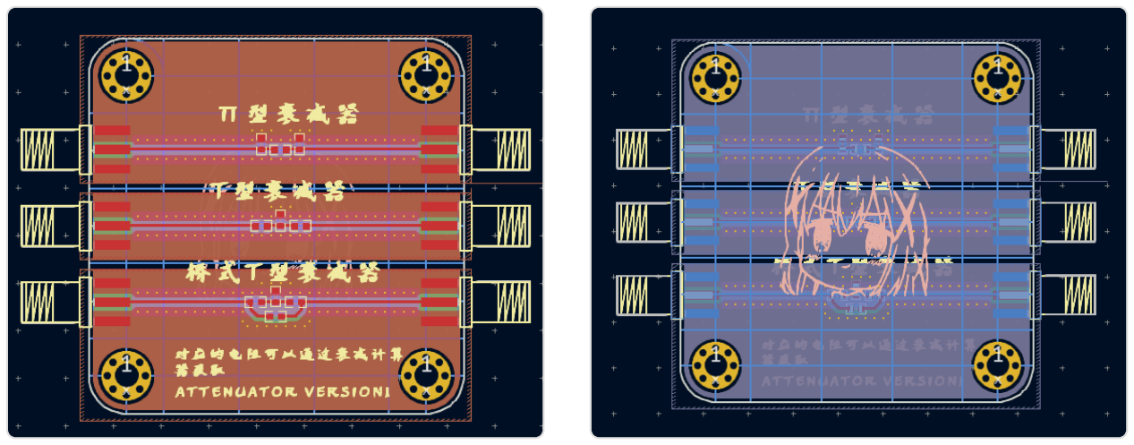
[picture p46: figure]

图4 Attenuator PCB设计

## PCB设计与尺寸

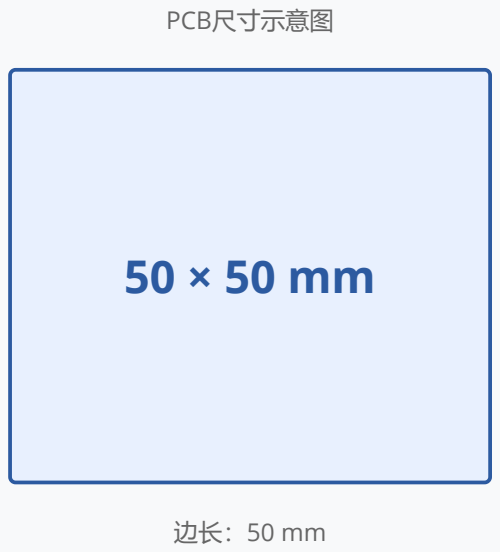
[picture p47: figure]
PCB尺寸示意图

正方形 PCB

安装孔径
M3

安装孔数量
4个

板厚

## 1.6 mm

安装孔位置

## 四角对称

衰减量 (dB) | PI型衰减器 | T型衰减器 | 桥式T型衰减器
3 dB | R₁=292Ω, R₂=17.6Ω | R₁=8.55Ω, R₂=292Ω | R₁=20.5Ω, R₂=121Ω
6 dB | R₁=150Ω, R₂=37.4Ω | R₁=16.6Ω, R₂=150Ω | R₁=50Ω, R₂=50Ω
10 dB | R₁=96.2Ω, R₂=71.2Ω | R₁=25.9Ω, R₂=96.2Ω | R₁=107Ω, R₂=23.5Ω
20 dB | R₁=61.1Ω, R₂=247Ω | R₁=40.9Ω, R₂=61.1Ω | R₁=450Ω, R₂=5.56Ω

## 使用注意

选择电阻时需注意其功率承受能力与频率特性，建议使用薄膜电阻或高频专用电阻。 焊接时注意电阻布局对称，避免引入寄生参数影响高频性能。 使用M3铜柱与螺母固定PCB，确保机械稳固。
在高频或大功率应用时，注意散热与屏蔽。

## 附录：建议匹配电阻（Z₀=50Ω）

注：电阻值为理论计算值，实际选型应选用最接近的标准阻值，并考虑电阻精度与温度系数。

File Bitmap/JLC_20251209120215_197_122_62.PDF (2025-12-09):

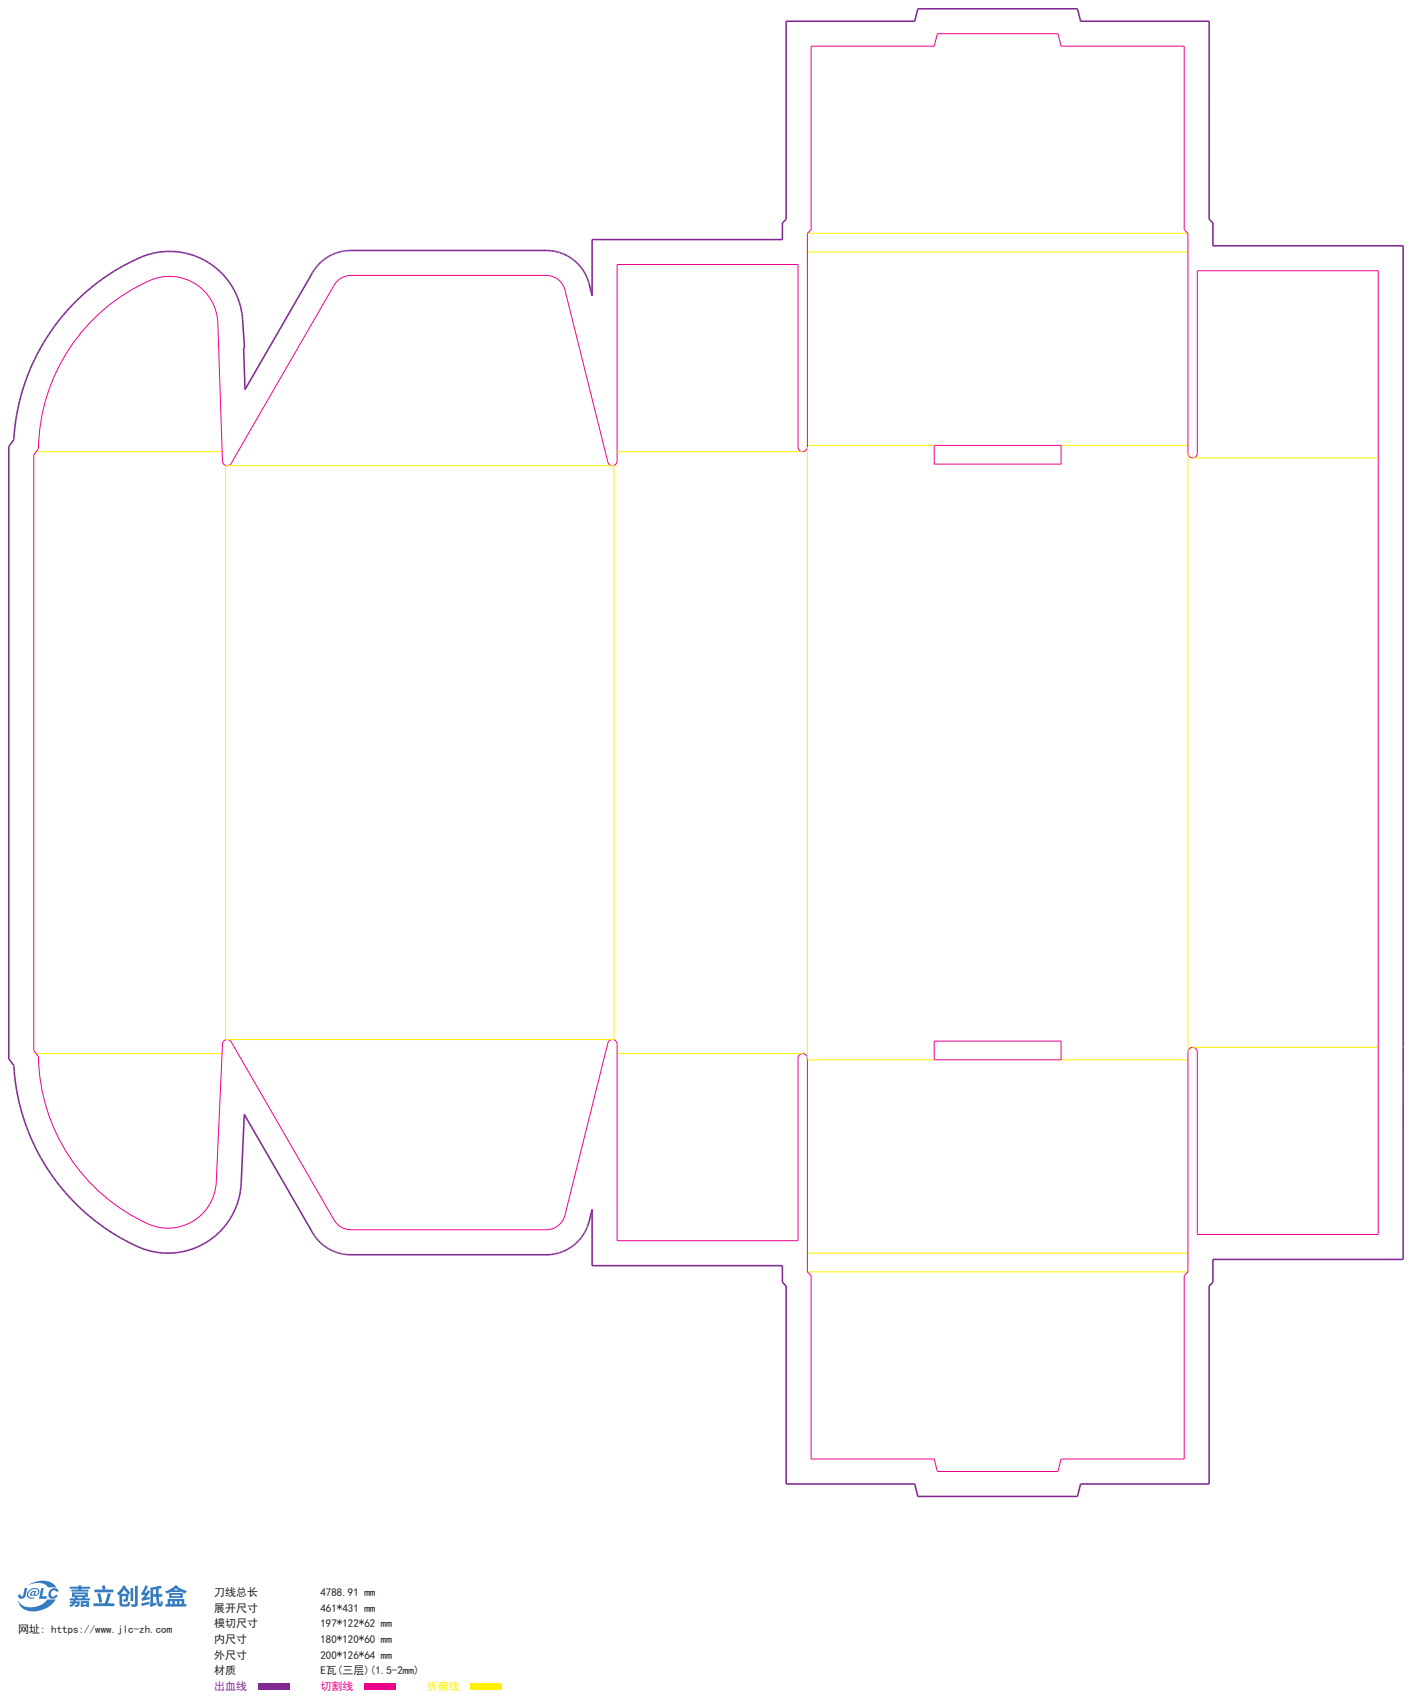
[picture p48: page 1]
刀线总长; 展开尺寸; 模切尺寸; 内尺寸; 外尺寸; 出血线; 切割线; 折痕线

网址: https://www.jlc-zh.com

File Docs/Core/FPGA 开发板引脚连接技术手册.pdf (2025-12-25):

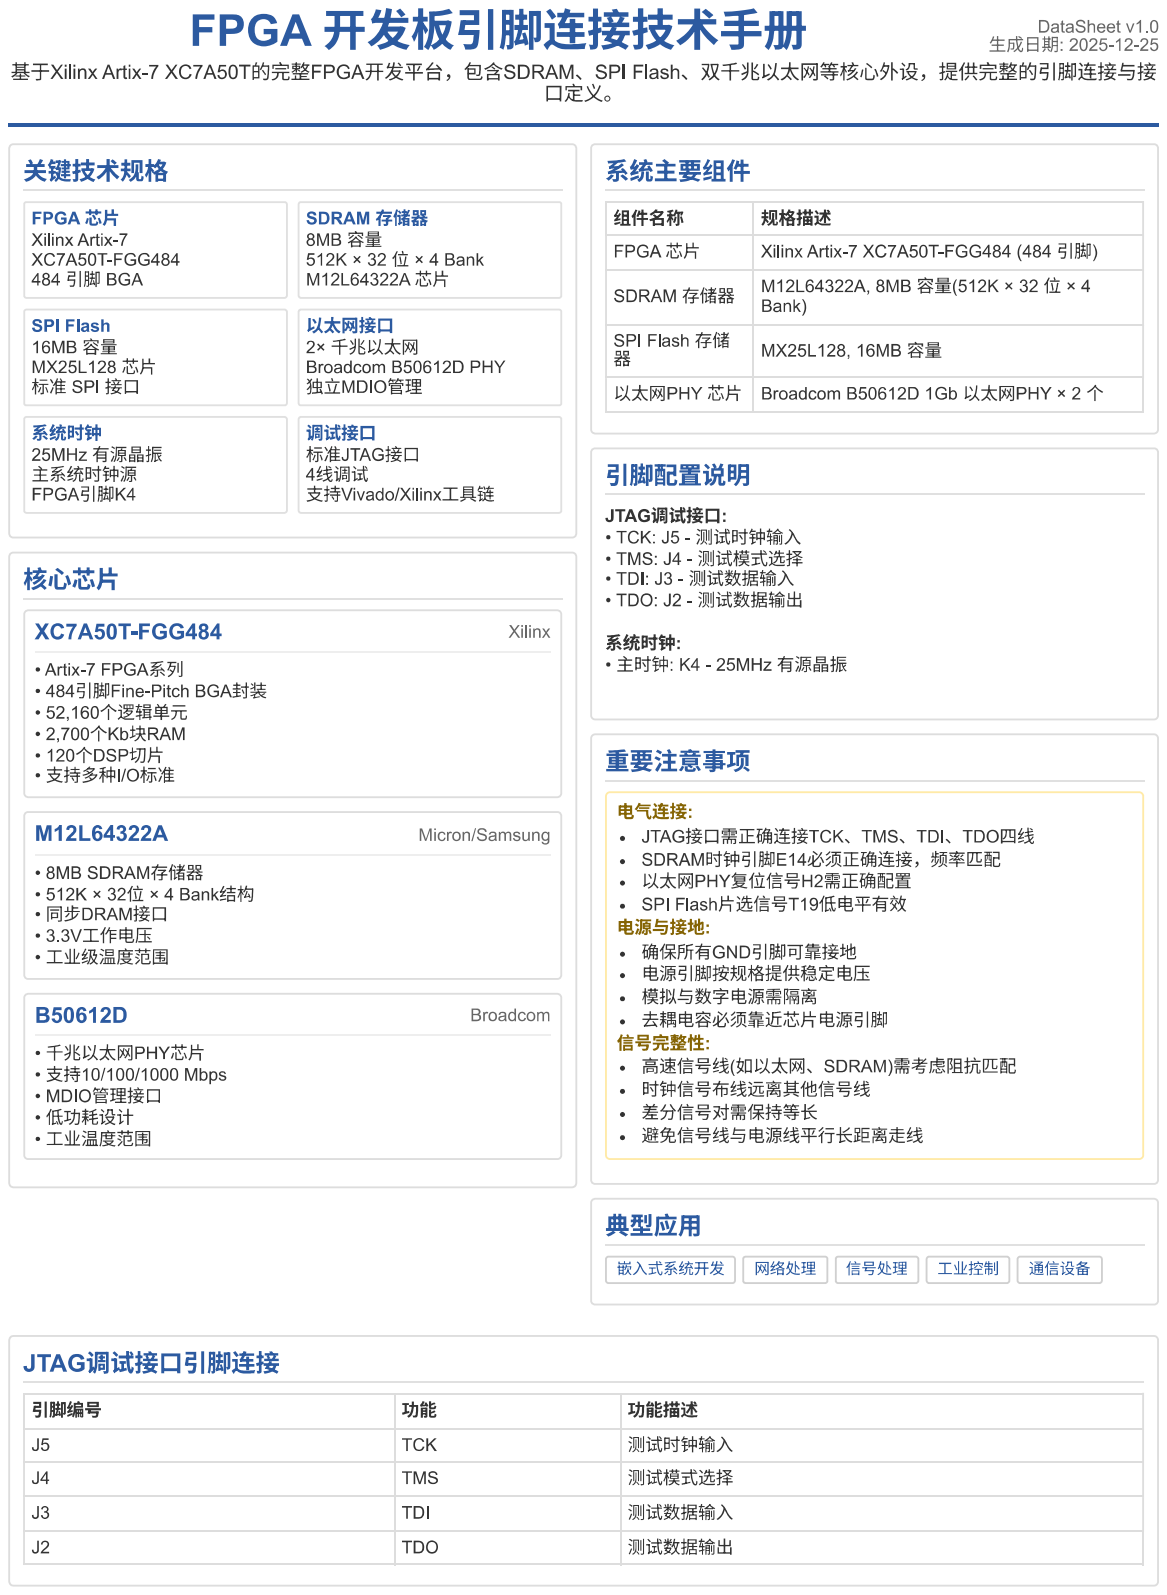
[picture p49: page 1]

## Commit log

2025-11-23 add new project
    [ADC_version1.kicad_pcb, ADC_version1.kicad_sch, DAC_version1.kicad_pcb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]
2025-11-28 add QuietLDO SCH
    [QuietLDO.kicad_pcb, QuietLDO.kicad_sch]
2025-11-30 start QuietPCB
    [QuietLDO-Board.dxf, QuietLDO.dxf, QuietLDO.kicad_pcb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]
2025-12-05 add QuietLDO PCB
    [QuietLDO.kicad_pcb, QuietLDO.kicad_sch]
2025-12-05 complete QuietLDO
    [QuietLDO.kicad_pcb]
2025-12-07 complete the datasheet of QuietLDO
    [QuietLDO.kicad_pcb, QuietLDO.step]
2025-12-09 add BOM Checklist Function
    [MultiClk-SIS5351A.kicad_pcb, MultiClk-SIS5351A.kicad_sch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]
2025-12-19 add Dual Output LDO of the Readme and start to design the logo or pictures
    [Dual-OutputLDO-Board.dxf, Dual-OutputLDO.dxf, Dual-OutputLDO.kicad_pcb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]
2025-12-20 complete Dual-OutputLDO
    [Dual-OutputLDO.kicad_pcb]
2025-12-25 add FPGA
    [AetherIO.kicad_sch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]
2026-01-01 add Filter Design
    [AetherIO.kicad_sch, Connect.kicad_sch, FPGA.kicad_sch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]
2026-01-02 add new key and filter design
    [FPGA.kicad_sch, LED.kicad_sch]
2026-01-12 start RF_Switch
    [Power.kicad_sch, RF_DualSwitch.kicad_sch, RF_TribSwitch.dxf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]
2026-01-23 complete RF_Switch
    [RF_DualSwitch.dxf, RF_DualSwitch.kicad_sch, RF_DualSwitch_Board.dxf]
2026-01-27 complete Attenuator Datasheet
    [Attenuator-Board.dxf, Attenuator.dxf, Attenuator.kicad_sch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]
